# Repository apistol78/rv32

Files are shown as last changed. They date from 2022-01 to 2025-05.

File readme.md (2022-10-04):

# MOJO Risc-V CPU and System-on-a-Chip
The MOJO SOC is an educational and fun system for FPGA and "Bare metal" programming experimentations.\
It's a RISC-V CPU running at 100 MHz, 32 MiB RAM, audio and 320*200 video resolution.
To make user input easy I've moved USB host functionality to an external PCB using Raspberry Pico as a FPGA <-> HID bridge.

# Prerequisites
This project require an install of Traktor to generate required resources.
You will also need a RISC-V GCC toolchain compiled and installed at __/opt/riscv32/bin__ on your machine.

# How to build
Run __build.sh__ to build host (i.e. Linux) and target products:
```
./build.sh
```
After everything has been built you should be able to run the emulators:
```
./build/linux/ReleaseStatic/Rv32T -elf=./build/rv32/ReleaseStatic/Boot
```
or
```
./build/linux/ReleaseStatic/Rv32 -elf=./build/rv32/ReleaseStatic/Boot
```

# CPU
MOJO CPU is a conventional 5-stage (F,D,X,M,W) pipelined RISC-V CPU. It also contain configurable data- and instruction caches.

Written using SystemVerilog and are split up into logical pieces where each stage of the pipeline is in a separate module:

| Module | Description |
|---|---|
| CPU_ALU | ALU unit, fully combinatorial |
| CPU_CSR | CSR control unit |
| CPU_DCache_Comb | Data cache, combinatorial |
| CPU_DCache_Reg | Data cache, registered |
| CPU_DCache_None | Data cache, disabled |
| CPU_Decode | Decode stage |
| CPU_Defines | CPU defines |
| CPU_Divide | Divison wrapper, usually implemented with a vendor IP |
| CPU_Execute | Execute stage |
| CPU_Fetch | Fetch stage |
| CPU_Forward | Register forwarding logic |
| CPU_ICache_Comb | Instruction cache, combinatorial |
| CPU_ICache_Reg | Instruction cache, registered |
| CPU_ICache_None | Instruction cache, disabled |
| CPU_Memory | Memory stage |
| CPU_Multiply | Multiplication wrapper, usually implemented with a vendor IP |
| CPU_Registers | Register file |
| CPU_SkidBuffer | Generalized skid-buffer |
| CPU_Types | CPU types |
| CPU_Writeback | Writeback stage |

# Perifherials
A lot of perifherial modules has been implemented as port of the SoC:
| Module | Description |
|---|---|
| AUDIO_controller, AUDIO_i2s_output, AUDIO_pwm_output | PCM based audio modules |
| BRAM | Various block-ram modules |
| BRIDGE | BUS bridge, to separate BUS devices for improved timing. |
| BROM | Block-rom module |
| BusAccess | BUS multiplexed access |
| ClockDivider | Generic clock divider |
| DMA | Direct memory access controller |
| FIFO_BRAM | Block ram backed FIFO |
| FIFO | Register backed FIFO |
| GPIO | General purpose IO controller |
| I2C | I2C controller |
| LED | LED controller |
| PLIC | PLIC interrupt controller |
| RESET | Reset controller |
| SD | SD controller |
| SDRAM_controller | Generic SDRAM controller |
| SRAM_interface | Generic SRAM controller |
| SystemRegisters | System wide register map |
| Timer | Hardware timer with compare |
| UART | UART controller |
| VIDEO_controller | Video output controller |
| VIDEO_VGA | Video VGA signal generator |
| WriteBuffer | Write buffer (queue) with readback or read-through |

# System-on-a-Chip
A couple of custom PCBs designed to connect to QM-Tech FPGA boards is the physical basis for MOJO SoC.
The SoC support following perifherials:
* HDMI output
* Stereo audio output through PWM and through I2S HDMI.
* SD card interface using 4-bit SD protocol.
* 2 UARTs, one for host and one for HID input.
* Raspberry Pico based USB host to FPGA bridge supporting three external HID devices (keyboard, mouse and gamepad).

## Emulators
Two different emulators, one C++ highlevel emulator and one based on Verilator. The highlevel is useful for application development and the other is used for verification of gate level logic.

## Runtime
C/C++ runtime library, including a preemptive multithreaded kernel, expose all hardware features to user programs. Support CRT for easy portability.

## Schematics
KiCad schematics for all perifherial boards are available and been built using JLCPCB.

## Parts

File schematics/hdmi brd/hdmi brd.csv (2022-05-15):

Comment | Designator | Footprint | LCSC
0.1uF | C1,C2,C7,C8,C9,C10,C11,C12,C13,C14,C15 | Capacitor_SMD:C_0402_1005Metric | C1525
0.1uF | C3,C16,C17,C18 | Capacitor_SMD:C_0805_2012Metric_Pad1.18x1.45mm_HandSolder
100nF | C4,C19,C20,C21 | Capacitor_SMD:C_0805_2012Metric_Pad1.18x1.45mm_HandSolder
10uF | C5 | Capacitor_SMD:CP_Elec_5x5.3
100uF | C6 | Capacitor_SMD:CP_Elec_5x5.3
MountingHole | H1,H2 | MountingHole:MountingHole_3.2mm_M3_DIN965_Pad
Conn_02x32_Odd_Even | J1 | Connector_PinSocket_2.54mm:PinSocket_2x32_P2.54mm_Vertical
685119134923 | J2 | 685119134923 | C720616
0.022uH | L1 | Inductor_SMD:L_0805_2012Metric_Pad1.05x1.20mm_HandSolder
0.022uH | L2,L3,L4 | Inductor_SMD:L_0805_2012Metric_Pad1.15x1.40mm_HandSolder
4.7k | R1,R3,R4,R5,R6,R7 | Resistor_SMD:R_0402_1005Metric | C25900
10k | R2 | Resistor_SMD:R_0402_1005Metric | C11660
TestPoint | TP1,TP2,TP3,TP4 | TestPoint:TestPoint_Pad_D1.0mm
SII9022ACNU | U1 | Package_DFN_QFN:QFN-72-1EP_10x10mm_P0.5mm_EP6x6mm | C369565
AZ1117EH-1.2TRG1 | U2 | Package_TO_SOT_SMD:SOT-223-3_TabPin2 | C92104

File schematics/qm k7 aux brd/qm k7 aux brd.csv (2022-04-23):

Source: | /home/apistol/private/rv32/schematics/qm k7 aux brd/qm k7 aux brd.kicad_sch
Date: | Fri 22 Apr 2022 02:09:59 PM CEST
Tool: | Eeschema 6.0.4-6f826c9f35~116~ubuntu21.10.1
Generator: | /usr/share/kicad/plugins/bom_csv_grouped_by_value.py
Component Count: | 27
Individual Components:
Item | Qty | Reference(s) | Value | LibPart | Footprint | Datasheet
 |  | C1 | 10uF | Device:C_Polarized | Capacitor_SMD:CP_Elec_5x5.3 | ~
 |  | C2 | 100uF | Device:C_Polarized | Capacitor_SMD:CP_Elec_5x5.3 | ~
 |  | C3 | 3.3uF | pspice:C | Capacitor_SMD:C_0805_2012Metric_Pad1.18x1.45mm_HandSolder | ~
 |  | C4 | 3.3uF | pspice:C | Capacitor_SMD:C_0805_2012Metric_Pad1.18x1.45mm_HandSolder | ~
 |  | C5 | 2.7nF | pspice:C | Capacitor_SMD:C_0805_2012Metric_Pad1.18x1.45mm_HandSolder | ~
 |  | C6 | 2.7nF | pspice:C | Capacitor_SMD:C_0805_2012Metric_Pad1.18x1.45mm_HandSolder | ~
 |  | C7 | 10uF | pspice:C | Capacitor_SMD:C_0805_2012Metric_Pad1.18x1.45mm_HandSolder | ~
 |  | C8 | 100nF | pspice:C | Capacitor_SMD:C_0805_2012Metric_Pad1.18x1.45mm_HandSolder | ~
 |  | C9 | 10uF | pspice:C | Capacitor_SMD:C_0805_2012Metric_Pad1.18x1.45mm_HandSolder | ~
 |  | H1 | MountingHole | Mechanical:MountingHole | MountingHole:MountingHole_3.2mm_M3_DIN965_Pad | ~
 |  | H2 | MountingHole | Mechanical:MountingHole | MountingHole:MountingHole_3.2mm_M3_DIN965_Pad | ~
 |  | J1 | LEFT | Connector_Generic:Conn_02x32_Odd_Even | Connector_PinSocket_2.54mm:PinSocket_2x32_P2.54mm_Vertical | ~
 |  | J2 | Micro_SD_Card | Connector:Micro_SD_Card | Connector_Card:microSD_HC_Hirose_DM3D-SF | http://katalog.we-online.de/em/datasheet/693072010801.pdf
 |  | J3 | Conn_01x03 | Connector_Generic:Conn_01x03 | Connector_PinHeader_2.54mm:PinHeader_1x03_P2.54mm_Vertical | ~
 |  | J4 | Conn_01x03 | Connector_Generic:Conn_01x03 | Connector_PinHeader_2.54mm:PinHeader_1x03_P2.54mm_Vertical | ~
 |  | R1 | 4k7 | Device:R | Resistor_SMD:R_0805_2012Metric_Pad1.20x1.40mm_HandSolder | ~
 |  | R2 | 4k7 | Device:R | Resistor_SMD:R_0805_2012Metric_Pad1.20x1.40mm_HandSolder | ~
 |  | R3 | 4k7 | Device:R | Resistor_SMD:R_0805_2012Metric_Pad1.20x1.40mm_HandSolder | ~
 |  | R4 | 4k7 | Device:R | Resistor_SMD:R_0805_2012Metric_Pad1.20x1.40mm_HandSolder | ~
 |  | R5 | 4k7 | Device:R | Resistor_SMD:R_0805_2012Metric_Pad1.20x1.40mm_HandSolder | ~
 |  | R6 | 10k | Device:R | Resistor_SMD:R_0805_2012Metric_Pad1.20x1.40mm_HandSolder | ~
 |  | R7 | 10k | Device:R | Resistor_SMD:R_0805_2012Metric_Pad1.20x1.40mm_HandSolder | ~
 |  | R8 | 470 | Device:R | Resistor_SMD:R_0805_2012Metric_Pad1.20x1.40mm_HandSolder | ~
 |  | R9 | 470 | Device:R | Resistor_SMD:R_0805_2012Metric_Pad1.20x1.40mm_HandSolder | ~
 |  | TP1 | TestPoint | Connector:TestPoint | TestPoint:TestPoint_Pad_D2.5mm | ~
 |  | U1 | AP1117-33 | Regulator_Linear:AP1117-33 | Package_TO_SOT_SMD:SOT-223-3_TabPin2 | http://www.diodes.com/datasheets/AP1117.pdf
 |  | U2 | CS4344-CZZ | 2022-04-22_11-49-30:CS4344-CZZ | footprints:CS4344-CZZ
Collated Components:
Item | Qty | Reference(s) | Value | LibPart | Footprint | Datasheet
1 | 1 | C1 | 10uF | Device:C_Polarized | Capacitor_SMD:CP_Elec_5x5.3 | ~
2 | 1 | C2 | 100uF | Device:C_Polarized | Capacitor_SMD:CP_Elec_5x5.3 | ~
3 | 2 | C3, C4 | 3.3uF | pspice:C | Capacitor_SMD:C_0805_2012Metric_Pad1.18x1.45mm_HandSolder | ~
4 | 2 | C5, C6 | 2.7nF | pspice:C | Capacitor_SMD:C_0805_2012Metric_Pad1.18x1.45mm_HandSolder | ~
5 | 2 | C7, C9 | 10uF | pspice:C | Capacitor_SMD:C_0805_2012Metric_Pad1.18x1.45mm_HandSolder | ~
6 | 1 | C8 | 100nF | pspice:C | Capacitor_SMD:C_0805_2012Metric_Pad1.18x1.45mm_HandSolder | ~
7 | 2 | H1, H2 | MountingHole | Mechanical:MountingHole | MountingHole:MountingHole_3.2mm_M3_DIN965_Pad | ~
8 | 1 | J1 | LEFT | Connector_Generic:Conn_02x32_Odd_Even | Connector_PinSocket_2.54mm:PinSocket_2x32_P2.54mm_Vertical | ~
9 | 1 | J2 | Micro_SD_Card | Connector:Micro_SD_Card | Connector_Card:microSD_HC_Hirose_DM3D-SF | http://katalog.we-online.de/em/datasheet/693072010801.pdf
10 | 2 | J3, J4 | Conn_01x03 | Connector_Generic:Conn_01x03 | Connector_PinHeader_2.54mm:PinHeader_1x03_P2.54mm_Vertical | ~
11 | 5 | R1, R2, R3, R4, R5 | 4k7 | Device:R | Resistor_SMD:R_0805_2012Metric_Pad1.20x1.40mm_HandSolder | ~
12 | 2 | R6, R7 | 10k | Device:R | Resistor_SMD:R_0805_2012Metric_Pad1.20x1.40mm_HandSolder | ~
13 | 2 | R8, R9 | 470 | Device:R | Resistor_SMD:R_0805_2012Metric_Pad1.20x1.40mm_HandSolder | ~
14 | 1 | TP1 | TestPoint | Connector:TestPoint | TestPoint:TestPoint_Pad_D2.5mm | ~
15 | 1 | U1 | AP1117-33 | Regulator_Linear:AP1117-33 | Package_TO_SOT_SMD:SOT-223-3_TabPin2 | http://www.diodes.com/datasheets/AP1117.pdf
16 | 1 | U2 | CS4344-CZZ | 2022-04-22_11-49-30:CS4344-CZZ | footprints:CS4344-CZZ

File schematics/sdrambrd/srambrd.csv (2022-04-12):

Source: | C:\temp\srambrd2\sdrambrd\srambrd.kicad_sch
Date: | 4/6/2022 11:04:05 AM
Tool: | Eeschema (6.0.4)
Generator: | C:\Program Files\KiCad\6.0\bin\scripting\plugins/bom_csv_grouped_by_value_with_fp.py
Component Count: | 24
Ref | Qnty | Value | Cmp name | Footprint | Description | Vendor
C1, C2, | 2 | 100nF | C | Capacitor_SMD:C_0805_2012Metric_Pad1.18x1.45mm_HandSolder | Capacitor symbol for simulation only
C3, C4, C5, C6, | 4 | 10nF | C | Capacitor_SMD:C_0805_2012Metric_Pad1.18x1.45mm_HandSolder | Capacitor symbol for simulation only
C7, C8, | 2 | 100uF | C_Polarized | Capacitor_SMD:CP_Elec_5x5.3 | Polarized capacitor
H1, H2, | 2 | MountingHole | MountingHole | MountingHole:MountingHole_3.2mm_M3_DIN965_Pad | Mounting Hole without connection
J1, | 1 | LEFT | Conn_02x32_Odd_Even | Connector_PinSocket_2.54mm:PinSocket_2x32_P2.54mm_Vertical | Generic connector, double row, 02x32, odd/even pin numbering scheme (row 1 odd numbers, row 2 even numbers), script generated (kicad-library-utils/schlib/autogen/connector/)
J2, | 1 | Micro_SD_Card | Micro_SD_Card | Connector_Card:microSD_HC_Hirose_DM3BT-DSF-PEJS | Micro SD Card Socket
J3, J4, | 2 | Conn_01x03 | Conn_01x03 | Connector_PinHeader_2.54mm:PinHeader_1x03_P2.54mm_Vertical | Generic connector, single row, 01x03, script generated (kicad-library-utils/schlib/autogen/connector/)
R1, R2, R3, R4, R5, R6, R7, R8, R9, | 9 | 4k7 | R | Resistor_SMD:R_0805_2012Metric_Pad1.20x1.40mm_HandSolder | Resistor
U1, | 1 | IS61LV25616AL | IS61LV25616AL | Package_SO:TSOP-II-44_10.16x18.41mm_P0.8mm

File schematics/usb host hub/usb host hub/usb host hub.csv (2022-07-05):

Comment | Designator | Footprint | LCSC
27pF | C1,C2 | Capacitor_SMD:C_0805_2012Metric
1uF | C13,C14 | Capacitor_SMD:C_0402_1005Metric
10uF | C15 | Capacitor_SMD:CP_Elec_5x5.3
100uF | C16 | Capacitor_SMD:CP_Elec_5x5.3
10uF | C19 | Capacitor_SMD:C_0402_1005Metric
10uF | C21,C22,C23 | Capacitor_SMD:C_0805_2012Metric
100nF | C3,C4,C5,C6,C7,C8,C9,C10,C11,C12,C17,C20 | Capacitor_SMD:C_0402_1005Metric | C307331
LED | D1 | LED_SMD:LED_0805_2012Metric | C2297
MountingHole | H1,H2,H3,H4 | MountingHole:MountingHole_3.2mm_M3_DIN965_Pad
292303-1 | J1,J2,J6 | 292303-1:TE_292303-1
Conn_01x04_Male | J4 | Connector_PinHeader_2.54mm:PinHeader_1x04_P2.54mm_Vertical
Conn_01x04_Male | J5 | Connector_JST:JST_EH_B4B-EH-A_1x04_P2.50mm_Vertical
1k | R1 | Resistor_SMD:R_0805_2012Metric
10k | R10 | Resistor_SMD:R_0402_1005Metric | C269674
47 | R11 | Resistor_SMD:R_0805_2012Metric
33k | R12,R14,R15 | Resistor_SMD:R_0805_2012Metric
2.7k 1% | R13 | Resistor_SMD:R_0402_1005Metric | C25885
27 | R2,R3 | Resistor_SMD:R_0805_2012Metric
27 | R4,R5,R6,R7,R8,R9 | Resistor_SMD:R_0402_1005Metric
TestPoint_Small | TP1,TP_DRV1,TP_LED1,TP_LED2,TP_1V1 | TestPoint:TestPoint_Pad_D1.5mm
RP2040 | U1 | parts:QFN40P700X700X90-57N | C2040
FE1.1s | U2 | Package_SO:SSOP-28_3.9x9.9mm_P0.635mm | C9359
W25Q128JVS | U3 | Package_SO:SOIC-8_5.23x5.23mm_P1.27mm | C97521
AZ1117EH-3.3TRG1 | U4 | Package_TO_SOT_SMD:SOT-223-3_TabPin2 | C108494
USBLC6-2SC6 | U5,U6,U7 | Package_TO_SOT_SMD:SOT-23-6
12MHz | Y1,Y2 | Crystal:Crystal_SMD_HC49-SD

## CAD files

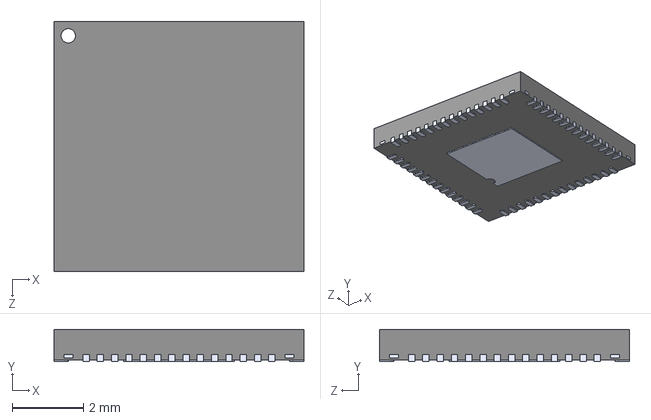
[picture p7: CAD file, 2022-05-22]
schematics/motherboard/parts/rp2040/RP2040.step
7.00 x 0.9 x 7.00 mm

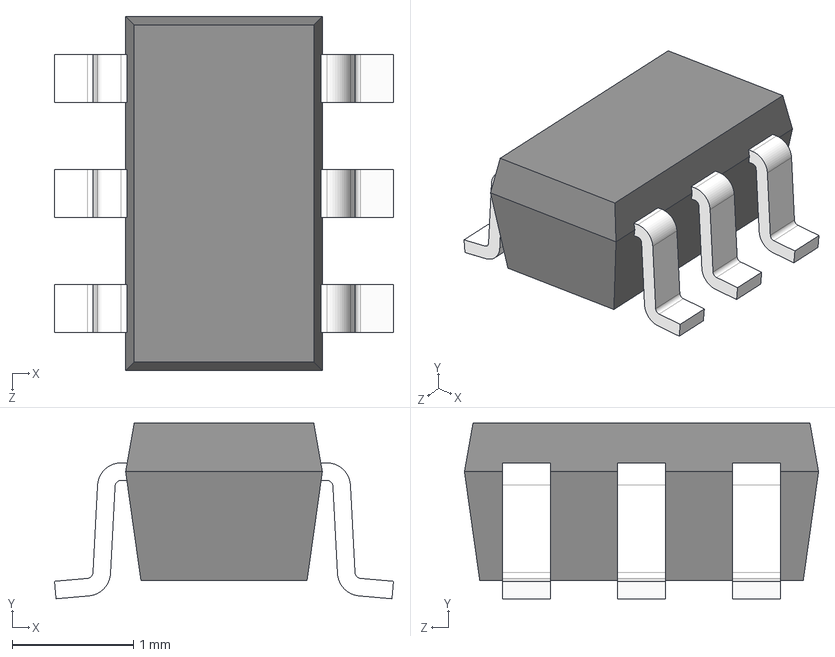
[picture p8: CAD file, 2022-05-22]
schematics/motherboard/parts/USBLC6-2SC6/USBLC6-2SC6.step
2.80 x 1.45 x 2.92 mm

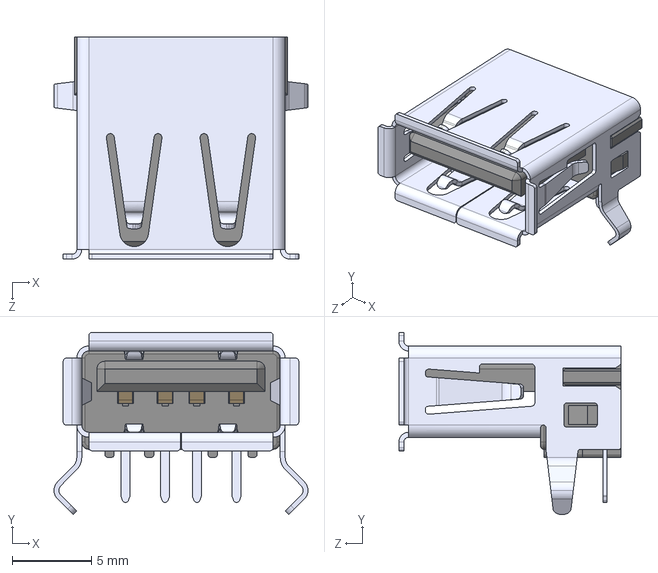
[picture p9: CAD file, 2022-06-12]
schematics/motherboard/parts/292303-1/292303-1.step
16.0 x 11.5 x 14.0 mm

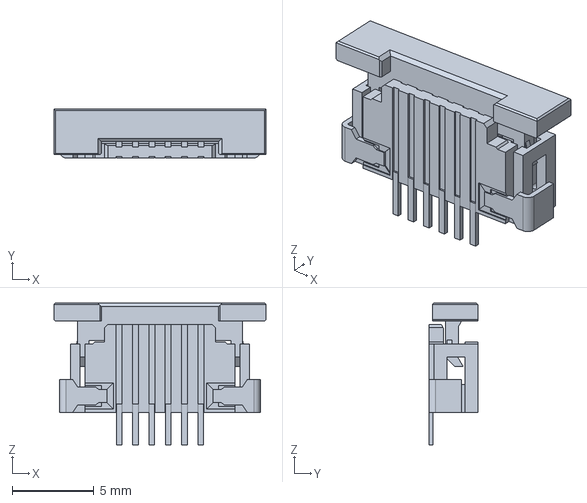
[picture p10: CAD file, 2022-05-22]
schematics/motherboard/parts/52271-0679/52271-0679.step
13.0 x 3.00 x 8.70 mm

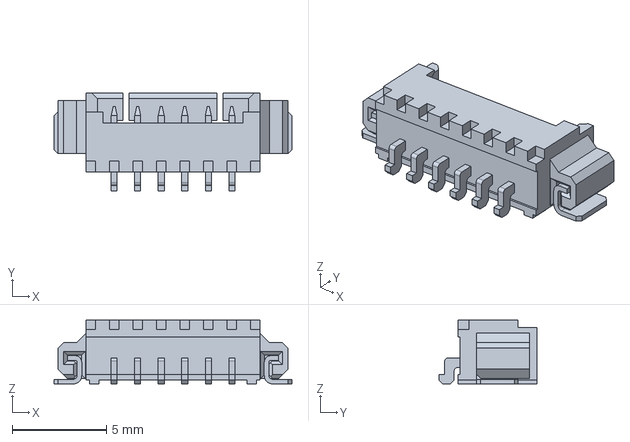
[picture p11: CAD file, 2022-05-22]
schematics/motherboard/parts/532610671/532610671.step
12.7 x 5.20 x 3.40 mm

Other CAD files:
board/qmtech_cv/SoC.stp
board/qmtech_cv_2/SoC.stp
board/SDRAM/stp1.stp
board/terasic_cv_gx/SoC.stp

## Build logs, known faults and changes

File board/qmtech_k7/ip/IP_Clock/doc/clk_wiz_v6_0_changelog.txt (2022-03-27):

2021.2:
 * Version 6.0 (Rev. 9)
 * Bug Fix: CR Fixes
 * Other: CR Fixes

2021.1.1:
 * Version 6.0 (Rev. 8)
 * No changes

2021.1:
 * Version 6.0 (Rev. 8)
 * Bug Fix: Internal GUI fixes
 * Other: CR Fixes

2020.3:
 * Version 6.0 (Rev. 7)
 * Bug Fix: Internal GUI fixes
 * Other: CR Fixes

2020.2.2:
 * Version 6.0 (Rev. 6)
 * No changes

2020.2.1:
 * Version 6.0 (Rev. 6)
 * No changes

2020.2:
 * Version 6.0 (Rev. 6)
 * Bug Fix: Internal GUI fixes
 * Other: CR Fixes

2020.1.1:
 * Version 6.0 (Rev. 5)
 * No changes

2020.1:
 * Version 6.0 (Rev. 5)
 * Bug Fix: Internal GUI fixes
 * Other: CR Fixes

2019.2.2:
 * Version 6.0 (Rev. 4)
 * No changes

2019.2.1:
 * Version 6.0 (Rev. 4)
 * No changes

2019.2:
 * Version 6.0 (Rev. 4)
 * Bug Fix: Internal GUI fixes
 * Other: CR Fixes

2019.1.3:
 * Version 6.0 (Rev. 3)
 * No changes

2019.1.2:
 * Version 6.0 (Rev. 3)
 * No changes

2019.1.1:
 * Version 6.0 (Rev. 3)
 * No changes

2019.1:
 * Version 6.0 (Rev. 3)
 * Bug Fix: Internal GUI fixes
 * Other: New family support added

2018.3.1:
 * Version 6.0 (Rev. 2)
 * No changes

2018.3:
 * Version 6.0 (Rev. 2)
 * Bug Fix: Made input source independent for primary and secondary clock
 * Other: New family support added

2018.2:
 * Version 6.0 (Rev. 1)
 * Bug Fix: Removed vco freq check when Primitive is None
 * Other: New family support added

2018.1:
 * Version 6.0
 * Bug Fix: Bug fixes in Dynamic Reconfiguration feature and Write DRP feature
 * Bug Fix: Bug fixes for connection issue for s_axi_aresetn pin in IPI
 * Feature Enhancement: The default value of USE_PHASE_ALIGMENT is updated to false for UltraScale and UltraScale+ devices. Phase Alignment feature uses extra clock routes in UltraScale and UltraScale+ designs when MMCMs are used. These routing resources are wasted when user do not understand when phase alignment is really needed. Now, implementation tools can use these extra clock routing resources for high fanout signals.
 * Feature Enhancement: A column "Max. freq of buffer" is added in the Output Clock table which shows the maximum frequency that the selected output buffer can support
 * Other: DRCs added for invalid input values in Override mode

2017.4:
 * Version 5.4 (Rev. 3)
 * Bug Fix: Internal GUI issues are fixed for COMPENSATION mode as INTERNAL
 * Bug Fix: Fixed issue in dynamic reconfiguration of fractional values of M in MMCME3, MMCME4

2017.3:
 * Version 5.4 (Rev. 2)
 * General: Internal GUI changes. No effect on the customer design. Added support for aspartan7 devices

2017.2:
 * Version 5.4 (Rev. 1)
 * General: Internal GUI changes. No effect on the customer design.

2017.1:
 * Version 5.4
 * Port Change: Minor version upgrade. CLR pins are added to the pin list when selected buffer is BUFGCEDIV for ultrascale and ultrascale plus devices.
 * Other: Added support for new zynq ultrascale plus devices.

2016.4:
 * Version 5.3 (Rev. 3)
 * Bug Fix: Internal GUI issues are fixed.

2016.3:
 * Version 5.3 (Rev. 2)
 * Feature Enhancement: Added new option "Auto" under PRIMITIVE selection for ultrascale and above devices. This option allows the Wizard to instantiate appropriate primitive for the user inputs.
 * Feature Enhancement: Added Matched Routing Option for better timing solutions.
 * Feature Enhancement: Options 'Buffer' and 'Buffer_with_CE' are added to the buffer selection list.
 * Other: Source HDL files are concatenated into a single file to speed up synthesis and simulation. No changes required by the user
 * Other: Added support for Spartan7 devices.

2016.2:
 * Version 5.3 (Rev. 1)
 * Internal register bit update, no effect on customer designs.

2016.1:
 * Version 5.3
 * Added Clock Monitor Feature as part of clocking wizard
 * DRP registers can be directly written through AXI without resource utilization
 * Changes to HDL library management to support Vivado IP simulation library

2015.4.2:
 * Version 5.2 (Rev. 1)
 * No changes

2015.4.1:
 * Version 5.2 (Rev. 1)
 * No changes

2015.4:
 * Version 5.2 (Rev. 1)
 * Internal device family change, no functional changes

2015.3:
 * Version 5.2
 * IP revision number added to HDL module, library, and include file names, to support designs with both locked and upgraded IP instances
 * Port Renaming tab is hidden in the GUI in IP Integrator as this feature is not supported
 * Phase alignment feature is removed for ultrascale PLL as primitve has limited capabilities of supporting this feature
 * When clocking wizard is targetted on a board part, the frequency values that gets propagated to primary and secondary clocks are displayed in floating number format
 * Example design and simulation files are delivered in verilog only

2015.2.1:
 * Version 5.1 (Rev. 6)
 * No changes

2015.2:
 * Version 5.1 (Rev. 6)
 * No changes

2015.1:
 * Version 5.1 (Rev. 6)
 * Updated mmcm_pll_filter_lookup and mmcm_pll_lock_lookup functions in the header file for 7-Series and UltraScale devices
 * Supported devices and production status are now determined automatically, to simplify support for future devices

2014.4.1:
 * Version 5.1 (Rev. 5)
 * No changes

2014.4:
 * Version 5.1 (Rev. 5)
 * Internal device family change, no functional changes
 * updates related to the source selection based on board interface for zed board

2014.3:
 * Version 5.1 (Rev. 4)
 * Option added to enable dynamic phase and duty cycle for resource optimization in AXI4-Lite interface

2014.2:
 * Version 5.1 (Rev. 3)
 * Updated for AXI4-Lite interface locked status register address and bit mapping to align with the pg065

2014.1:
 * Version 5.1 (Rev. 2)
 * Updated to use inverted output CLKOUTB 0-3 of Clocking Primitive based on requested 180 phase w.r.t. previous clock
 * Internal device family name change, no functional changes

2013.4:
 * Version 5.1 (Rev. 1)
 * Added support for Ultrascale devices
 * Updated Board Flow GUI to select the clock interfaces
 * Fixed issue with Stub file parameter error for BUFR output driver

2013.3:
 * Version 5.1
 * Added AXI4-Lite interface to dynamically reconfigure MMCM/PLL
 * Improved safe clock logic to remove glitches on clock outputs for odd multiples of input clock frequencies
 * Fixed precision issues between displayed and actual frequencies
 * Added tool tips to GUI
 * Added Jitter and Phase error values to IP properties
 * Added support for Cadence IES and Synopsys VCS simulators
 * Reduced warnings in synthesis and simulation
 * Enhanced support for IP Integrator

2013.2:
 * Version 5.0 (Rev. 1)
 * Fixed issue with clock constraints for multiple instances of clocking wizard
 * Updated Life-Cycle status of devices

2013.1:
 * Version 5.0
 * Lower case ports for Verilog
 * Added Safe Clock Startup and Clock Sequencing

(c) Copyright 2008 - 2021 Xilinx, Inc. All rights reserved.

This file contains confidential and proprietary information
of Xilinx, Inc. and is protected under U.S. and
international copyright and other intellectual property
laws.

DISCLAIMER
This disclaimer is not a license and does not grant any
rights to the materials distributed herewith. Except as
otherwise provided in a valid license issued to you by
Xilinx, and to the maximum extent permitted by applicable
law: (1) THESE MATERIALS ARE MADE AVAILABLE "AS IS" AND
WITH ALL FAULTS, AND XILINX HEREBY DISCLAIMS ALL WARRANTIES
AND CONDITIONS, EXPRESS, IMPLIED, OR STATUTORY, INCLUDING
BUT NOT LIMITED TO WARRANTIES OF MERCHANTABILITY, NON-
INFRINGEMENT, OR FITNESS FOR ANY PARTICULAR PURPOSE; and
(2) Xilinx shall not be liable (whether in contract or tort,
including negligence, or under any other theory of
liability) for any loss or damage of any kind or nature
related to, arising under or in connection with these
materials, including for any direct, or any indirect,
special, incidental, or consequential loss or damage
(including loss of data, profits, goodwill, or any type of
loss or damage suffered as a result of any action brought
by a third party) even if such damage or loss was
reasonably foreseeable or Xilinx had been advised of the
possibility of the same.

CRITICAL APPLICATIONS
Xilinx products are not designed or intended to be fail-
safe, or for use in any application requiring fail-safe
performance, such as life-support or safety devices or
systems, Class III medical devices, nuclear facilities,
applications related to the deployment of airbags, or any
other applications that could lead to death, personal
injury, or severe property or environmental damage
(individually and collectively, "Critical
Applications"). Customer assumes the sole risk and
liability of any use of Xilinx products in Critical
Applications, subject only to applicable laws and
regulations governing limitations on product liability.

THIS COPYRIGHT NOTICE AND DISCLAIMER MUST BE RETAINED AS
PART OF THIS FILE AT ALL TIMES.

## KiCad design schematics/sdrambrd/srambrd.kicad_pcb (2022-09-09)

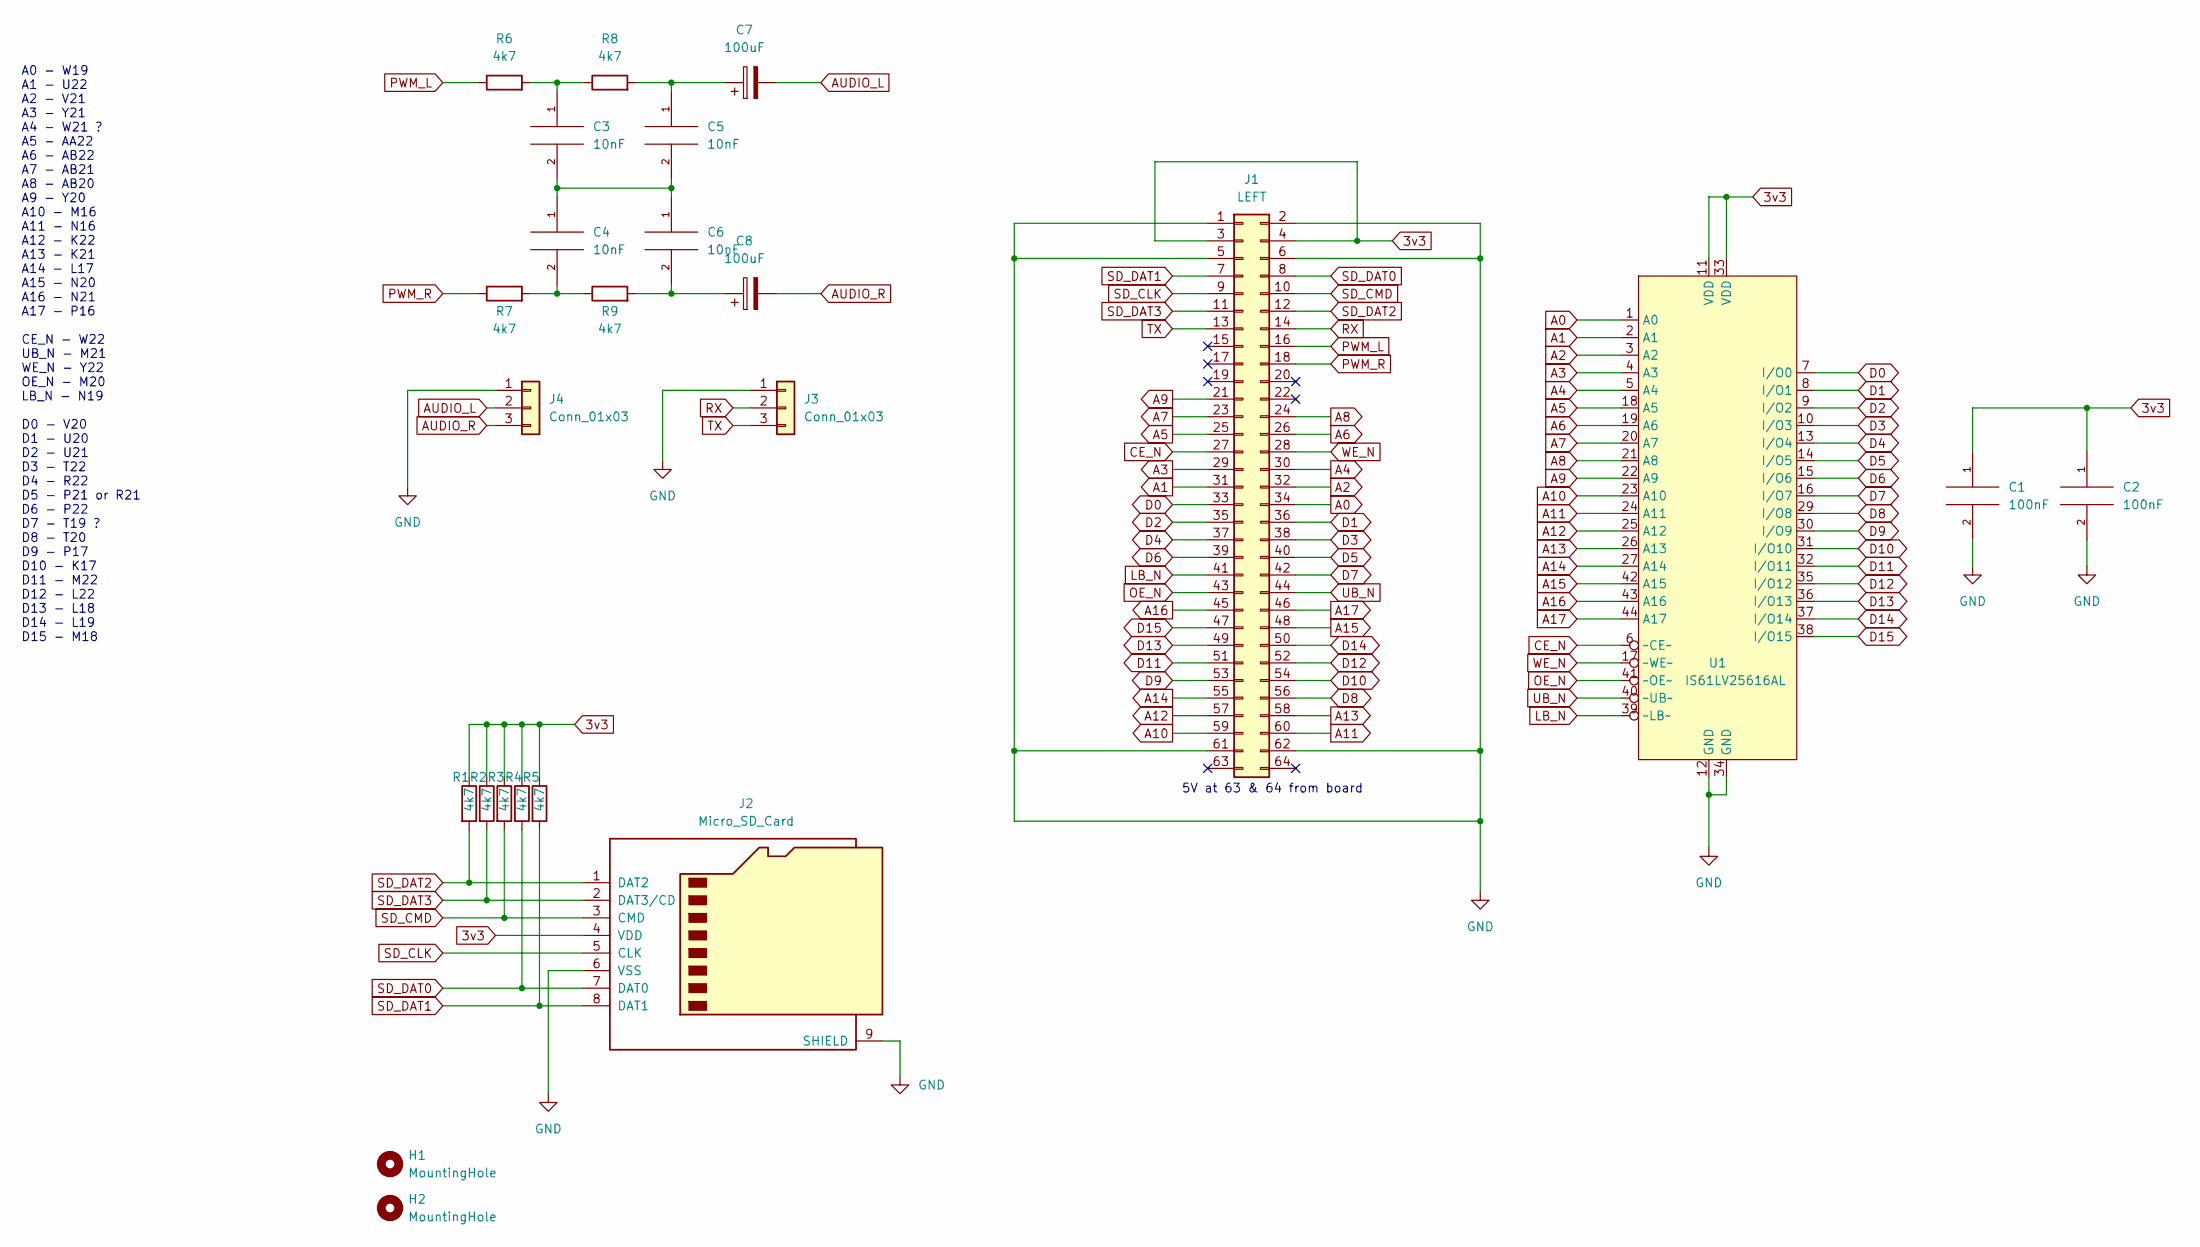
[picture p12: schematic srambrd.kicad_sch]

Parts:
C1, C2: 100nF; C_0805_2012Metric_Pad1.18x1.45mm_HandSolder
C3, C4, C5, C6: 10nF; C_0805_2012Metric_Pad1.18x1.45mm_HandSolder
C7, C8: 100uF; CP_Elec_5x5.3
H1, H2: MountingHole; MountingHole_3.2mm_M3_DIN965_Pad
J1: LEFT; PinSocket_2x32_P2.54mm_Vertical
J2: Micro_SD_Card; microSD_HC_Hirose_DM3D-SF
J3, J4: Conn_01x03; PinHeader_1x03_P2.54mm_Vertical
R1, R2, R3, R4, R5, R6, R7, R8, R9: 4k7; R_0805_2012Metric_Pad1.20x1.40mm_HandSolder
U1: IS61LV25616AL; TSOP-II-44_10.16x18.41mm_P0.8mm

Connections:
3v3: C1.1, C2.1, J1.3, J1.4, J2.4 (VDD), R1.1, R2.1, R3.1, R4.1, R5.1, U1.11 (VDD), U1.33 (VDD)
A0: J1.34, U1.1 (A0)
A1: J1.31, U1.2 (A1)
A2: J1.32, U1.3 (A2)
A3: J1.29, U1.4 (A3)
A4: J1.30, U1.5 (A4)
A5: J1.25, U1.18 (A5)
A6: J1.26, U1.19 (A6)
A7: J1.23, U1.20 (A7)
A8: J1.24, U1.21 (A8)
A9: J1.21, U1.22 (A9)
A10: J1.59, U1.23 (A10)
A11: J1.60, U1.24 (A11)
A12: J1.57, U1.25 (A12)
A13: J1.58, U1.26 (A13)
A14: J1.55, U1.27 (A14)
A15: J1.48, U1.42 (A15)
A16: J1.45, U1.43 (A16)
A17: J1.46, U1.44 (A17)
AUDIO_L: C7.2, J4.2
AUDIO_R: C8.2, J4.3
CE_N: J1.27, U1.6 (~CE~)
D0: J1.33, U1.7 (I/O0)
D1: J1.36, U1.8 (I/O1)
D2: J1.35, U1.9 (I/O2)
D3: J1.38, U1.10 (I/O3)
D4: J1.37, U1.13 (I/O4)
D5: J1.40, U1.14 (I/O5)
D6: J1.39, U1.15 (I/O6)
D7: J1.42, U1.16 (I/O7)
D8: J1.56, U1.29 (I/O8)
D9: J1.53, U1.30 (I/O9)
D10: J1.54, U1.31 (I/O10)
D11: J1.51, U1.32 (I/O11)
D12: J1.52, U1.35 (I/O12)
D13: J1.49, U1.36 (I/O13)
D14: J1.50, U1.37 (I/O14)
D15: J1.47, U1.38 (I/O15)
GND: C1.2, C2.2, J1.1, J1.2, J1.5, J1.6, J1.61, J1.62, J2.6 (VSS), J2.9 (SHIELD), J3.1, J4.1, U1.12 (GND), U1.34 (GND)
LB_N: J1.41, U1.39 (~LB~)
unnamed: C3.1, R6.2, R8.1
unnamed: C3.2, C4.1, C5.2, C6.1
unnamed: C4.2, R7.2, R9.1
unnamed: C5.1, C7.1, R8.2
unnamed: C6.2, C8.1, R9.2
OE_N: J1.43, U1.41 (~OE~)
PWM_L: J1.16, R6.1
PWM_R: J1.18, R7.1
RX: J1.14, J3.2
SD_CLK: J1.9, J2.5 (CLK)
SD_CMD: J1.10, J2.3 (CMD), R3.2
SD_DAT0: J1.8, J2.7 (DAT0), R4.2
SD_DAT1: J1.7, J2.8 (DAT1), R5.2
SD_DAT2: J1.12, J2.1 (DAT2), R1.2
SD_DAT3: J1.11, J2.2 (DAT3/CD), R2.2
TX: J1.13, J3.3
UB_N: J1.44, U1.40 (~UB~)
WE_N: J1.28, U1.17 (~WE~)

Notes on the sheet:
5V at 63 & 64 from board
A0 - W19 A1 - U22 A2 - V21 A3 - Y21 A4 - W21 ? A5 - AA22 A6 - AB22 A7 - AB21 A8 - AB20 A9 - Y20 A10 - M16 A11 - N16 A12 - K22 A13 - K21 A14 - L17 A15 - N20 A16 - N21 A17 - P16 CE_N - W22 UB_N - M21 WE_N - Y22 OE_N - M20 LB_N - N19 D0 - V20 D1 - U20 D2 - U21 D3 - T22 D4 - R22 D5 - P21 or R21 D6 - P2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

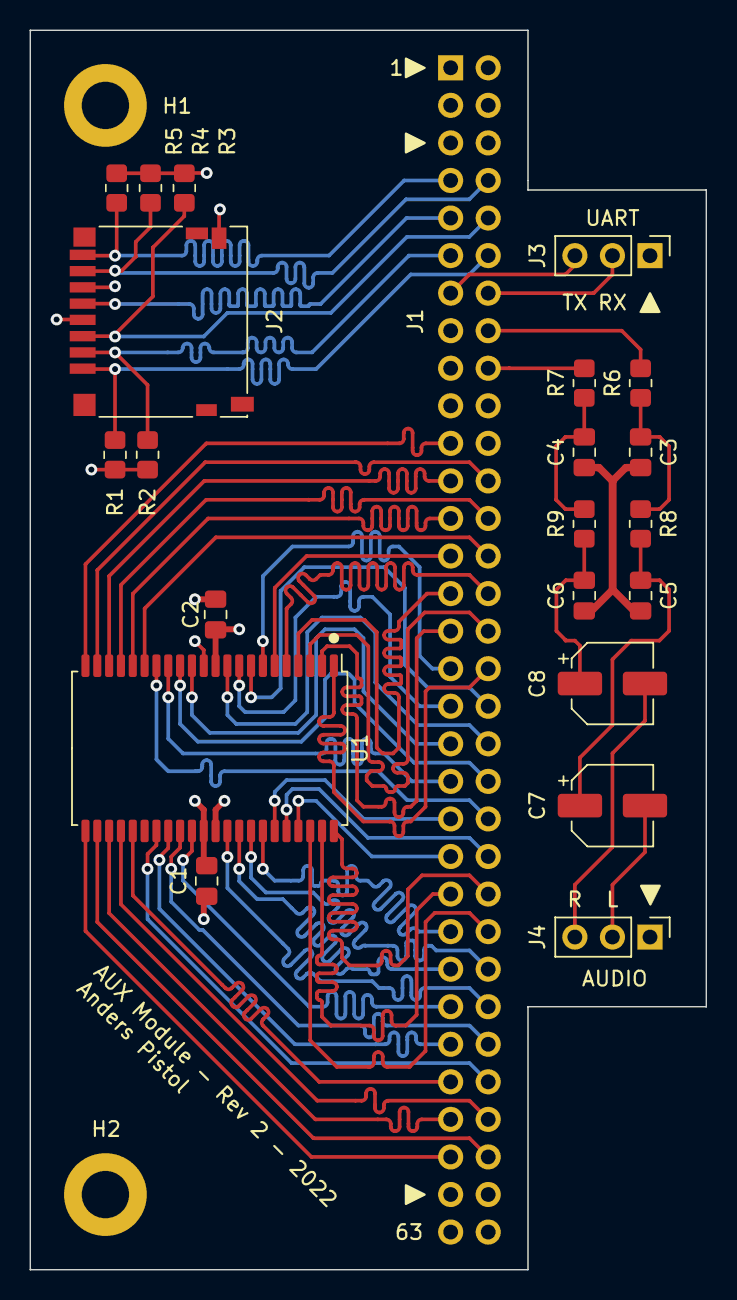
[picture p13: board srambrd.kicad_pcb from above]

Board: 4 copper layers, 45.7 x 83.8 mm, 24 parts (1 on the bottom side), 58 nets.

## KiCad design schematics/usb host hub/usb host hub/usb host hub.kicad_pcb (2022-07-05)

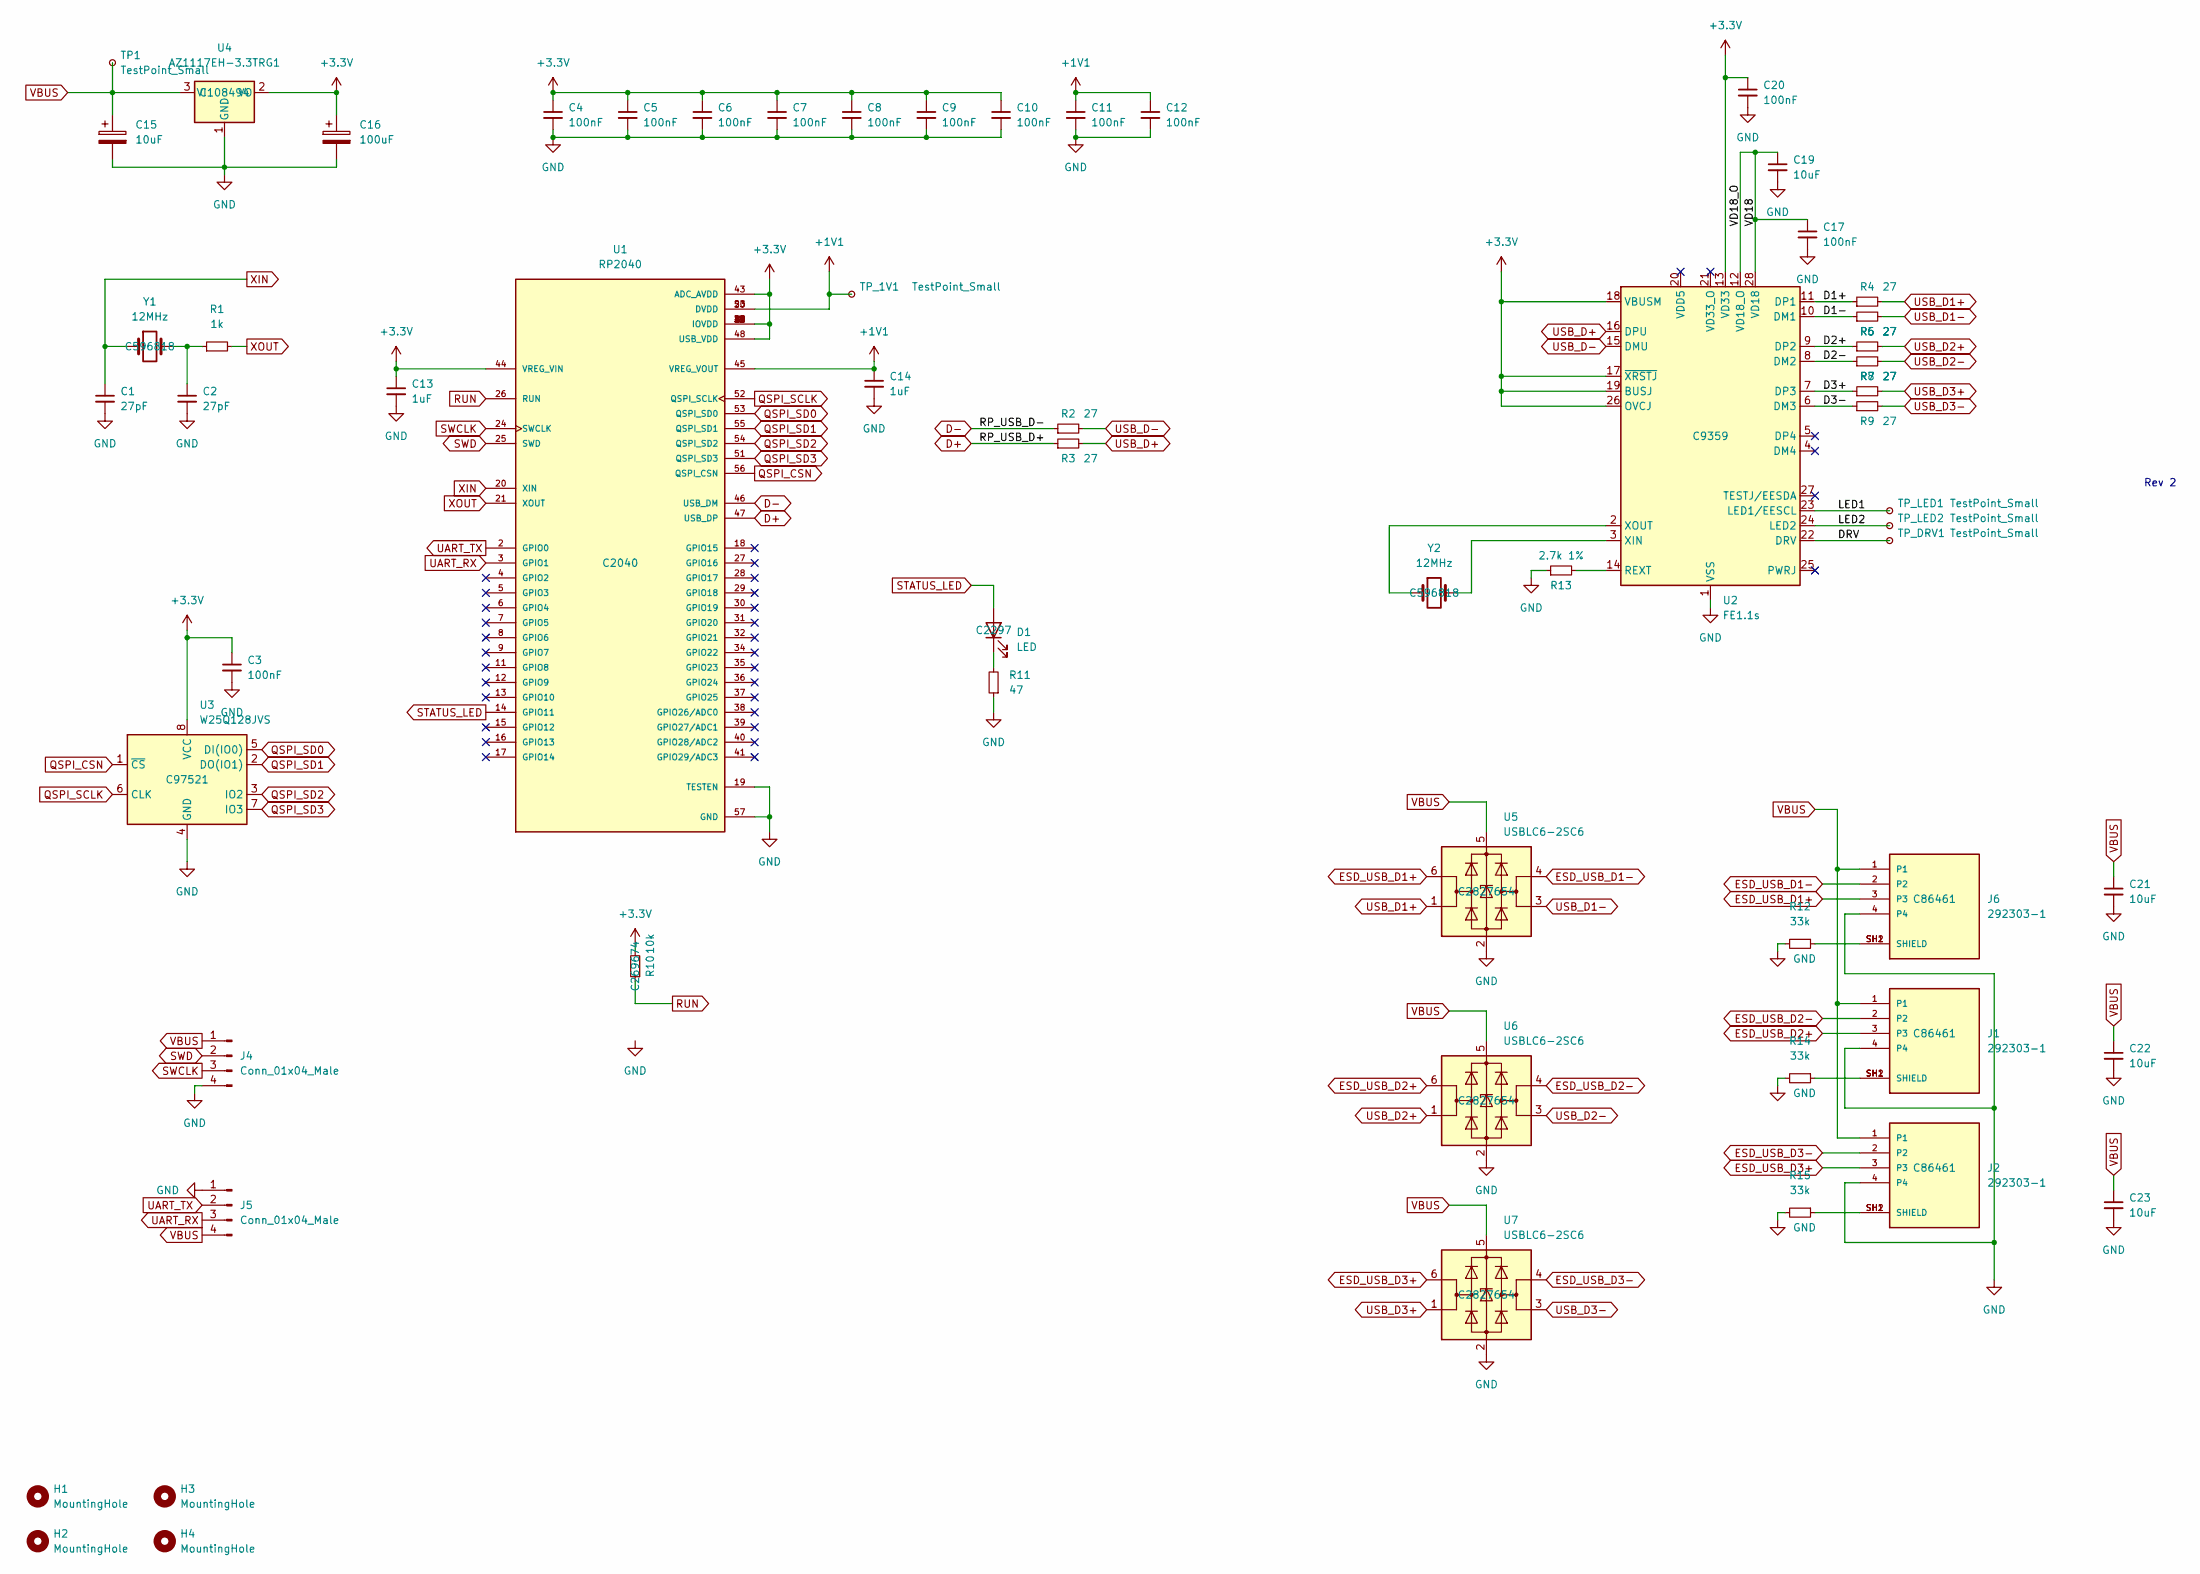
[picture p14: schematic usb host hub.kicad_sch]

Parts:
C1, C2: 27pF; C_0805_2012Metric
C3, C4, C5, C6, C7, C8, C9, C10, C11, C12, C17, C20: 100nF; C_0402_1005Metric; LCSC C307331
C13, C14: 1uF; C_0402_1005Metric
C15: 10uF; CP_Elec_5x5.3
C16: 100uF; CP_Elec_5x5.3
C19: 10uF; C_0402_1005Metric
C21, C22, C23: 10uF; C_0805_2012Metric
D1: LED; LED_0805_2012Metric; LCSC C2297
H1, H2, H3, H4: MountingHole; MountingHole_3.2mm_M3_DIN965_Pad
J1, J2, J6: 292303-1; TE_292303-1
J4: Conn_01x04_Male; PinHeader_1x04_P2.54mm_Vertical
J5: Conn_01x04_Male; JST_EH_B4B-EH-A_1x04_P2.50mm_Vertical
R1: 1k; R_0805_2012Metric
R2, R3: 27; R_0805_2012Metric
R4, R5, R6, R7, R8, R9: 27; R_0402_1005Metric
R10: 10k; R_0402_1005Metric; LCSC C269674
R11: 47; R_0805_2012Metric
R12, R14, R15: 33k; R_0805_2012Metric
R13: 2.7k 1%; R_0402_1005Metric; LCSC C25885
TP1: TestPoint_Small; TestPoint_Pad_D1.5mm
TP_1V1: TestPoint_Small; TestPoint_Pad_D1.5mm
TP_DRV1: TestPoint_Small; TestPoint_Pad_D1.5mm
TP_LED1, TP_LED2: TestPoint_Small; TestPoint_Pad_D1.5mm
U1: RP2040; QFN40P700X700X90-57N; PARTREV 1.6.1; LCSC C2040
U2: FE1.1s; SSOP-28_3.9x9.9mm_P0.635mm; LCSC C9359
U3: W25Q128JVS; SOIC-8_5.23x5.23mm_P1.27mm; LCSC C97521
U4: AZ1117EH-3.3TRG1; SOT-223-3_TabPin2; LCSC C108494
U5, U6, U7: USBLC6-2SC6; SOT-23-6
Y1, Y2: 12MHz; Crystal_SMD_HC49-SD

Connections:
+1V1: C11.1, C12.1, C14.1, TP_1V1.1, U1.23 (DVDD), U1.45 (VREG_VOUT), U1.50 (DVDD)
+3V3: C3.1, C4.1, C5.1, C6.1, C7.1, C8.1, C9.1, C10.1, C13.1, C16.1, C20.1, R10.2, U1.1 (IOVDD), U1.10 (IOVDD), U1.22 (IOVDD), U1.33 (IOVDD), U1.42 (IOVDD), U1.43 (ADC_AVDD), U1.44 (VREG_VIN), U1.48 (USB_VDD), U1.49 (IOVDD), U2.13 (VD33), U2.17 (~XRSTJ), U2.18 (VBUSM), U2.19 (BUSJ), U2.26 (OVCJ), U3.8 (VCC), U4.2 (VO)
/D1+: R4.1, U2.11 (DP1)
/D1-: R5.1, U2.10 (DM1)
/D2+: R6.1, U2.9 (DP2)
/D2-: R7.1, U2.8 (DM2)
/D3+: R8.1, U2.7 (DP3)
/D3-: R9.1, U2.6 (DM3)
/DRV: TP_DRV1.1, U2.22 (DRV)
/LED1: TP_LED1.1, U2.23 (LED1/EESCL)
/LED2: TP_LED2.1, U2.24 (LED2)
/VD18: C17.1, C19.1, U2.12 (VD18_O), U2.28 (VD18)
D+: R3.1, U1.47 (USB_DP)
D-: R2.1, U1.46 (USB_DM)
ESD_USB_D1+: J6.3, U5.6 (I/O1)
ESD_USB_D1-: J6.2, U5.4 (I/O2)
ESD_USB_D2+: J1.3, U6.6 (I/O1)
ESD_USB_D2-: J1.2, U6.4 (I/O2)
ESD_USB_D3+: J2.3, U7.6 (I/O1)
ESD_USB_D3-: J2.2, U7.4 (I/O2)
GND: C1.2, C2.2, C3.2, C4.2, C5.2, C6.2, C7.2, C8.2, C9.2, C10.2, C11.2, C12.2, C13.2, C14.2, C15.2, C16.2, C17.2, C19.2, C20.2, C21.2, C22.2, C23.2, J1.4, J2.4, J4.4, J5.1, J6.4, R11.1, R12.2, R13.1, R14.2, R15.2, U1.19 (TESTEN), U1.57 (GND), U2.1 (VSS), U3.4 (GND), U4.1 (GND), U5.2 (GND), U6.2 (GND), U7.2 (GND)
unnamed: C2.1, R1.1, Y1.2
unnamed: D1.1 (K), R11.2
unnamed: J1.SH1 (SHIELD), J1.SH2 (SHIELD), R14.1
unnamed: J2.SH1 (SHIELD), J2.SH2 (SHIELD), R15.1
unnamed: J6.SH1 (SHIELD), J6.SH2 (SHIELD), R12.1
unnamed: R13.2, U2.14 (REXT)
unnamed: U2.3 (XIN), Y2.2
unnamed: U2.2 (XOUT), Y2.1
QSPI_CSN: U1.56 (QSPI_CSN), U3.1 (~CS)
QSPI_SCLK: U1.52 (QSPI_SCLK), U3.6 (CLK)
QSPI_SD0: U1.53 (QSPI_SD0), U3.5 (DI(IO0))
QSPI_SD1: U1.55 (QSPI_SD1), U3.2 (DO(IO1))
QSPI_SD2: U1.54 (QSPI_SD2), U3.3 (IO2)
QSPI_SD3: U1.51 (QSPI_SD3), U3.7 (IO3)
RUN: R10.1, U1.26 (RUN)
STATUS_LED: D1.2 (A), U1.14 (GPIO11)
SWCLK: J4.3, U1.24 (SWCLK)
SWD: J4.2, U1.25 (SWD)
UART_RX: J5.3, U1.3 (GPIO1)
UART_TX: J5.2, U1.2 (GPIO0)
USB_D1+: R4.2, U5.1 (I/O1)
USB_D1-: R5.2, U5.3 (I/O2)
USB_D2+: R6.2, U6.1 (I/O1)
USB_D2-: R7.2, U6.3 (I/O2)
USB_D3+: R8.2, U7.1 (I/O1)
USB_D3-: R9.2, U7.3 (I/O2)
USB_D+: R3.2, U2.16 (DPU)
USB_D-: R2.2, U2.15 (DMU)
VBUS: C15.1, C21.1, C22.1, C23.1, J1.1, J2.1, J4.1, J5.4, J6.1, TP1.1, U4.3 (VI), U5.5 (VBUS), U6.5 (VBUS), U7.5 (VBUS)
XIN: C1.1, U1.20 (XIN), Y1.1
XOUT: R1.2, U1.21 (XOUT)

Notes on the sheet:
Rev 2

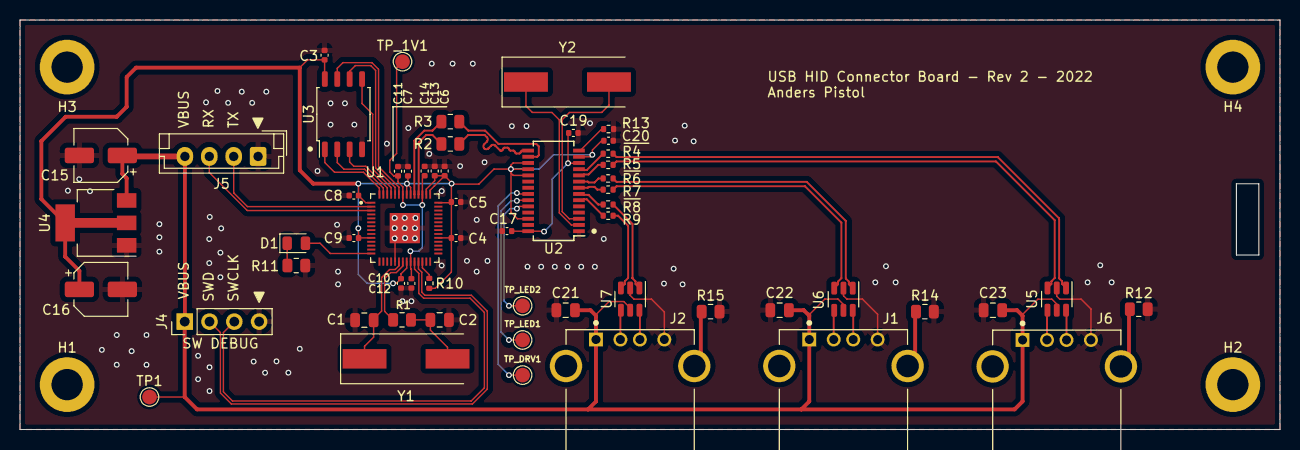
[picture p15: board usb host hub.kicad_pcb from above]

Board: 2 copper layers, 129.0 x 41.9 mm, 61 parts (0 on the bottom side), 52 nets.

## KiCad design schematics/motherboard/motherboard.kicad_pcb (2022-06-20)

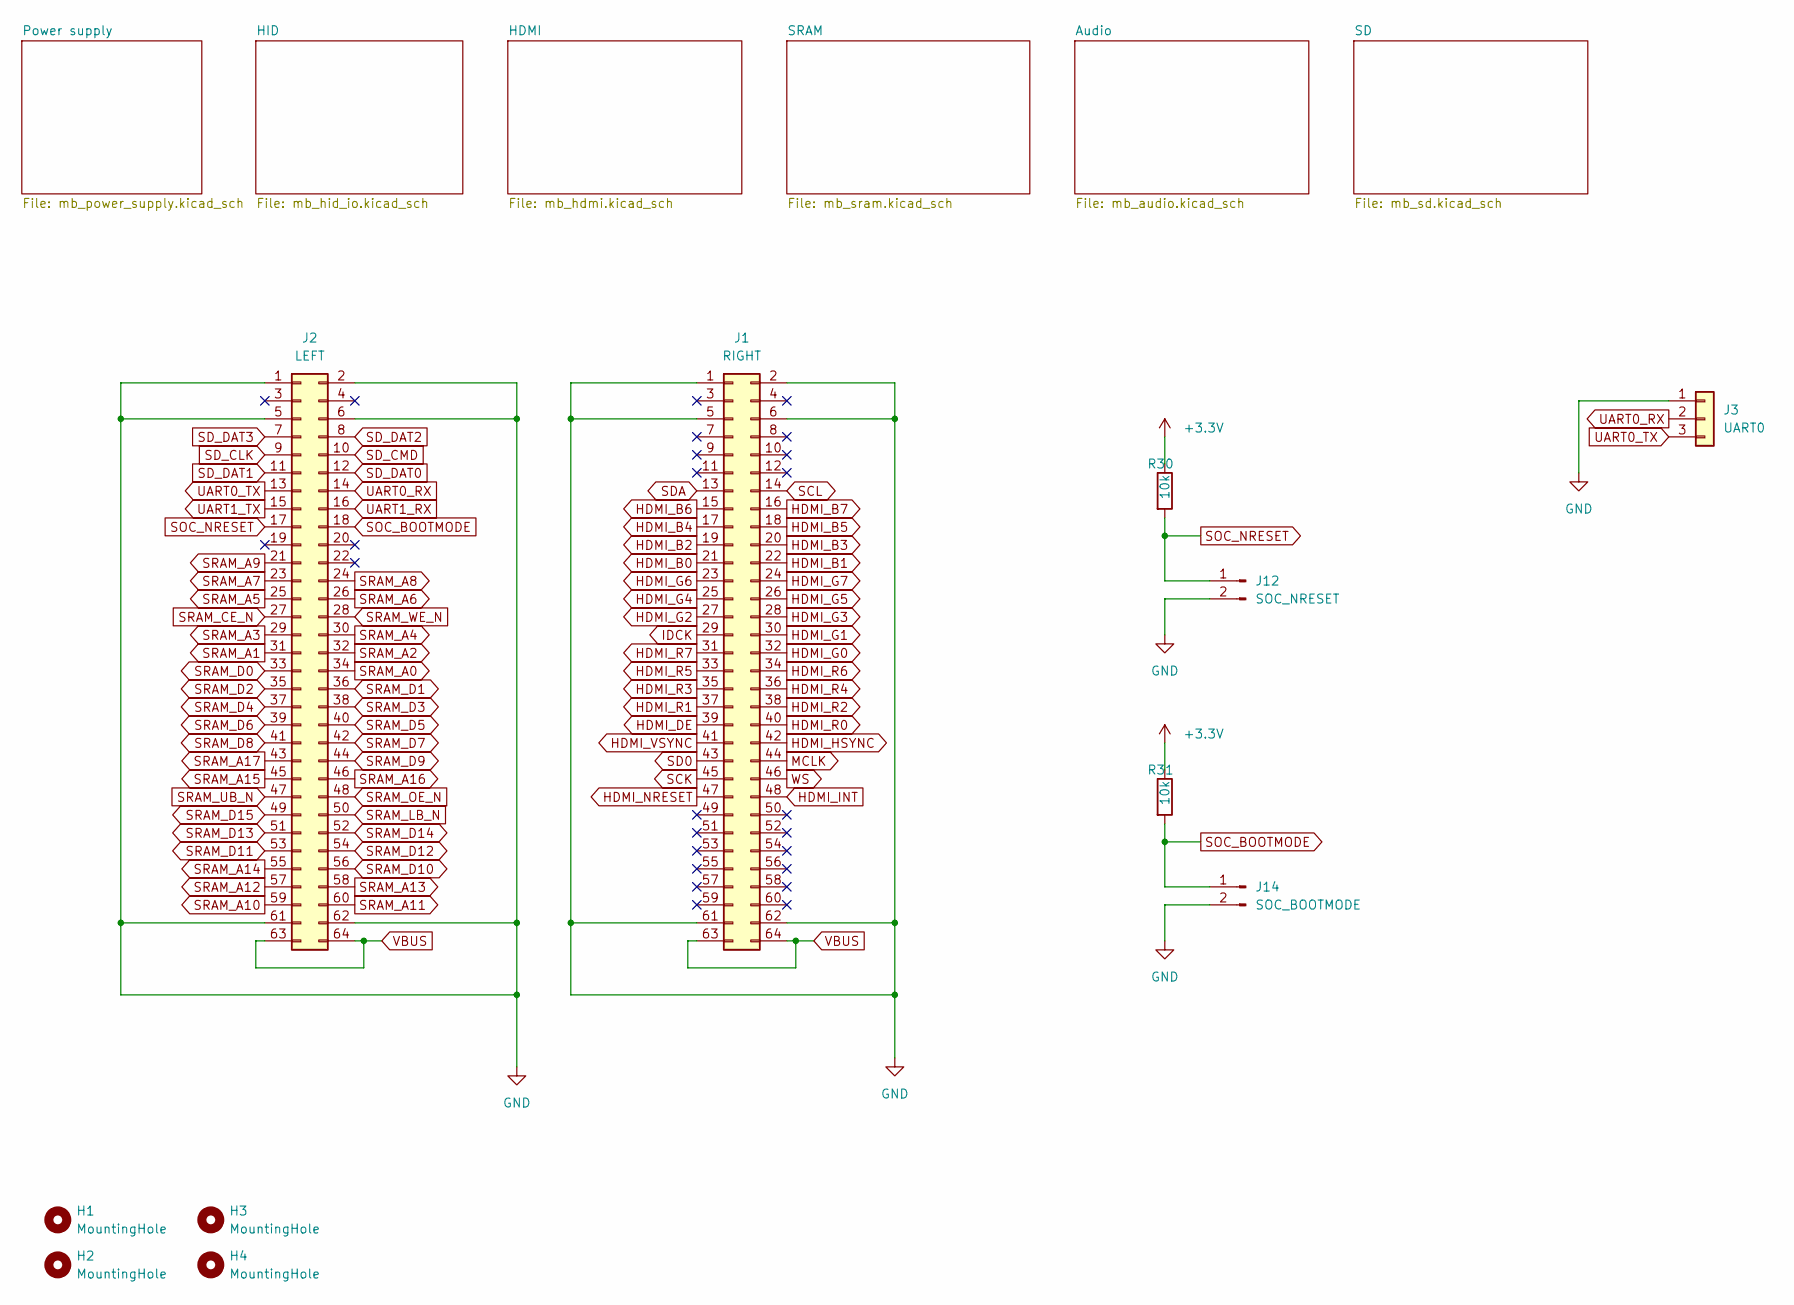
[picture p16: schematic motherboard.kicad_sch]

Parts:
H1, H2, H3, H4: MountingHole; MountingHole_3.2mm_M3_Pad_Via
J1: RIGHT; PinSocket_2x32_P2.54mm_Vertical
J2: LEFT; PinSocket_2x32_P2.54mm_Vertical
J3: UART0; PinHeader_1x03_P2.54mm_Vertical
J12: SOC_NRESET; PinHeader_1x02_P2.54mm_Vertical
J14: SOC_BOOTMODE; PinHeader_1x02_P2.54mm_Vertical
R30, R31: 10k; R_0805_2012Metric_Pad1.20x1.40mm_HandSolder

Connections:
+3V3: R30.1, R31.1; also elsewhere on the board
GND: J1.1, J1.2, J1.5, J1.6, J1.61, J1.62, J2.1, J2.2, J2.5, J2.6, J2.61, J2.62, J3.1, J12.2, J14.2; also elsewhere on the board
HDMI_B0: J1.21; also elsewhere on the board
HDMI_B1: J1.22; also elsewhere on the board
HDMI_B2: J1.19; also elsewhere on the board
HDMI_B3: J1.20; also elsewhere on the board
HDMI_B4: J1.17; also elsewhere on the board
HDMI_B5: J1.18; also elsewhere on the board
HDMI_B6: J1.15; also elsewhere on the board
HDMI_B7: J1.16; also elsewhere on the board
HDMI_DE: J1.39; also elsewhere on the board
HDMI_G0: J1.32; also elsewhere on the board
HDMI_G1: J1.30; also elsewhere on the board
HDMI_G2: J1.27; also elsewhere on the board
HDMI_G3: J1.28; also elsewhere on the board
HDMI_G4: J1.25; also elsewhere on the board
HDMI_G5: J1.26; also elsewhere on the board
HDMI_G6: J1.23; also elsewhere on the board
HDMI_G7: J1.24; also elsewhere on the board
HDMI_HSYNC: J1.42; also elsewhere on the board
HDMI_INT: J1.48; also elsewhere on the board
HDMI_NRESET: J1.47; also elsewhere on the board
HDMI_R0: J1.40; also elsewhere on the board
HDMI_R1: J1.37; also elsewhere on the board
HDMI_R2: J1.38; also elsewhere on the board
HDMI_R3: J1.35; also elsewhere on the board
HDMI_R4: J1.36; also elsewhere on the board
HDMI_R5: J1.33; also elsewhere on the board
HDMI_R6: J1.34; also elsewhere on the board
HDMI_R7: J1.31; also elsewhere on the board
HDMI_VSYNC: J1.41; also elsewhere on the board
IDCK: J1.29; also elsewhere on the board
MCLK: J1.44; also elsewhere on the board
SCK: J1.45; also elsewhere on the board
SCL: J1.14; also elsewhere on the board
SD0: J1.43; also elsewhere on the board
SDA: J1.13; also elsewhere on the board
SD_CLK: J2.9; also elsewhere on the board
SD_CMD: J2.10; also elsewhere on the board
SD_DAT0: J2.12; also elsewhere on the board
SD_DAT1: J2.11; also elsewhere on the board
SD_DAT2: J2.8; also elsewhere on the board
SD_DAT3: J2.7; also elsewhere on the board
SOC_BOOTMODE: J2.18, J14.1, R31.2
SOC_NRESET: J2.17, J12.1, R30.2
SRAM_A0: J2.34; also elsewhere on the board
SRAM_A1: J2.31; also elsewhere on the board
SRAM_A2: J2.32; also elsewhere on the board
SRAM_A3: J2.29; also elsewhere on the board
SRAM_A4: J2.30; also elsewhere on the board
SRAM_A5: J2.25; also elsewhere on the board
SRAM_A6: J2.26; also elsewhere on the board
SRAM_A7: J2.23; also elsewhere on the board
SRAM_A8: J2.24; also elsewhere on the board
SRAM_A9: J2.21; also elsewhere on the board
SRAM_A10: J2.59; also elsewhere on the board
SRAM_A11: J2.60; also elsewhere on the board
SRAM_A12: J2.57; also elsewhere on the board
SRAM_A13: J2.58; also elsewhere on the board
SRAM_A14: J2.55; also elsewhere on the board
SRAM_A15: J2.45; also elsewhere on the board
SRAM_A16: J2.46; also elsewhere on the board
SRAM_A17: J2.43; also elsewhere on the board
SRAM_CE_N: J2.27; also elsewhere on the board
SRAM_D0: J2.33; also elsewhere on the board
SRAM_D1: J2.36; also elsewhere on the board
SRAM_D2: J2.35; also elsewhere on the board
SRAM_D3: J2.38; also elsewhere on the board
SRAM_D4: J2.37; also elsewhere on the board
SRAM_D5: J2.40; also elsewhere on the board
SRAM_D6: J2.39; also elsewhere on the board
SRAM_D7: J2.42; also elsewhere on the board
SRAM_D8: J2.41; also elsewhere on the board
SRAM_D9: J2.44; also elsewhere on the board
SRAM_D10: J2.56; also elsewhere on the board
SRAM_D11: J2.53; also elsewhere on the board
SRAM_D12: J2.54; also elsewhere on the board
SRAM_D13: J2.51; also elsewhere on the board
SRAM_D14: J2.52; also elsewhere on the board
SRAM_D15: J2.49; also elsewhere on the board
SRAM_LB_N: J2.50; also elsewhere on the board
SRAM_OE_N: J2.48; also elsewhere on the board
SRAM_UB_N: J2.47; also elsewhere on the board
SRAM_WE_N: J2.28; also elsewhere on the board
UART0_RX: J2.14, J3.2
UART0_TX: J2.13, J3.3
UART1_RX: J2.16; also elsewhere on the board
UART1_TX: J2.15; also elsewhere on the board
VBUS: J1.63, J1.64, J2.63, J2.64; also elsewhere on the board
WS: J1.46; also elsewhere on the board

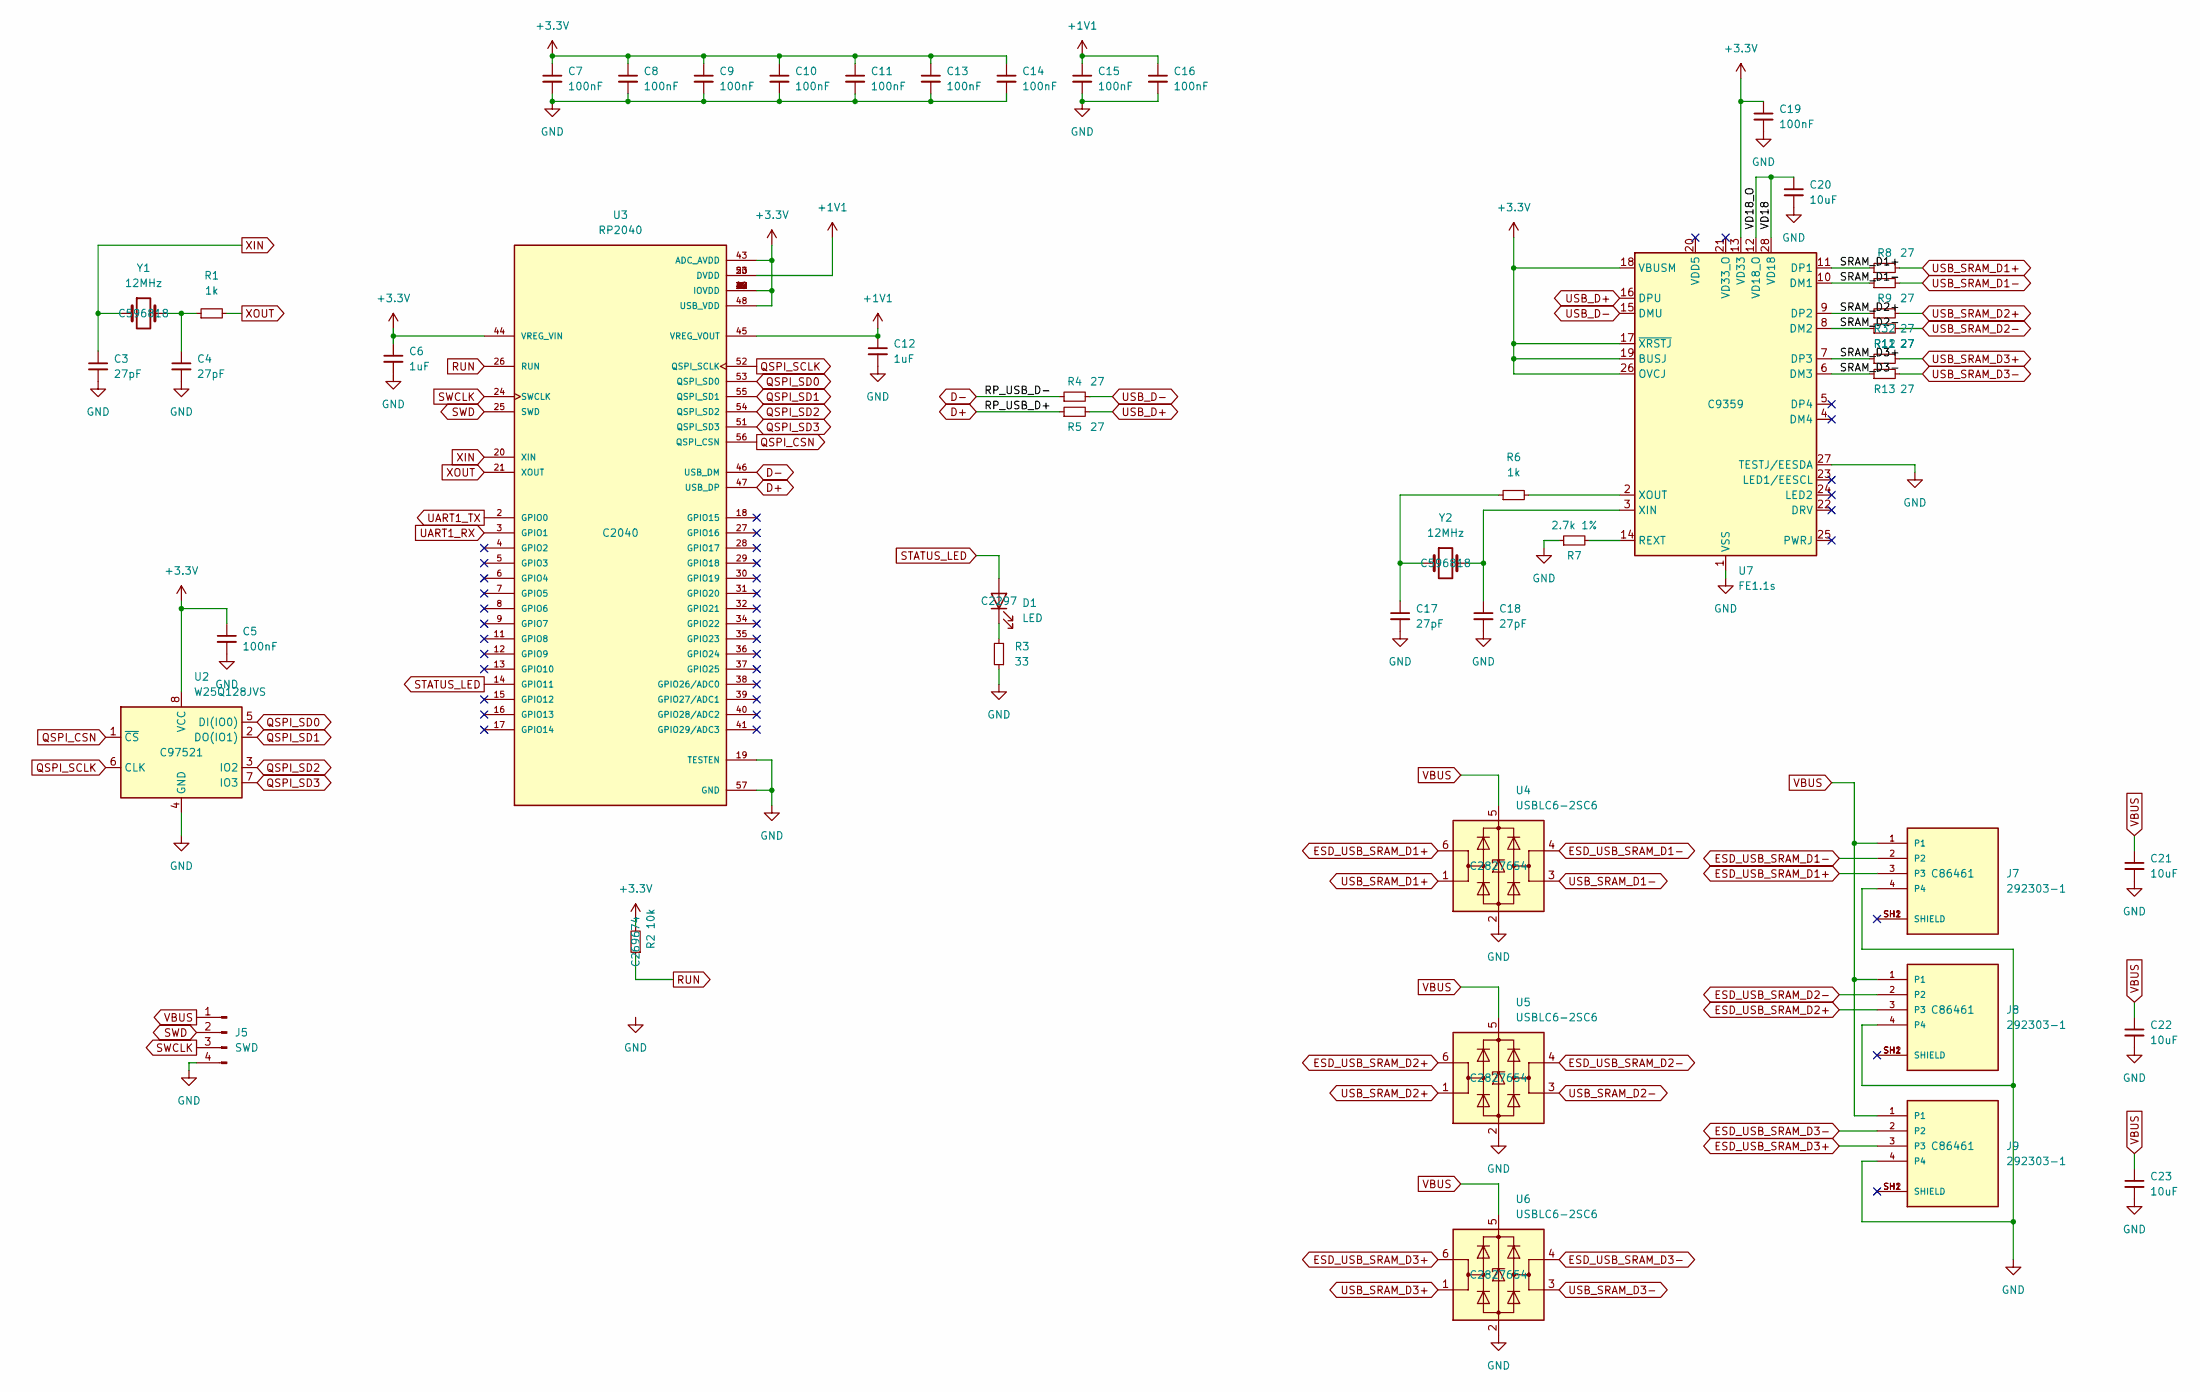
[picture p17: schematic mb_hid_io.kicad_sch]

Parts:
C3, C4, C17, C18: 27pF; C_0805_2012Metric
C5, C7, C8, C9, C10, C11, C13, C14, C15, C16, C19: 100nF; C_0402_1005Metric; LCSC C307331
C6, C12: 1uF; C_0402_1005Metric
C20: 10uF; C_0402_1005Metric
C21, C22, C23: 10uF; C_0805_2012Metric
D1: LED; LED_0805_2012Metric; LCSC C2297
J5: SWD; PinHeader_1x04_P2.54mm_Vertical
J7, J8, J9: 292303-1; TE_292303-1
R1, R6: 1k; R_0805_2012Metric
R2: 10k; R_0402_1005Metric; LCSC C269674
R3: 33; R_0805_2012Metric
R4, R5: 27; R_0805_2012Metric
R7: 2.7k 1%; R_0402_1005Metric; LCSC C25885
R8, R9, R11, R12, R13, R32: 27; R_0402_1005Metric
U2: W25Q128JVS; SOIC-8_5.23x5.23mm_P1.27mm; LCSC C97521
U3: RP2040; QFN40P700X700X90-57N; PARTREV 1.6.1; LCSC C2040
U4, U5, U6: USBLC6-2SC6; SOT-23-6
U7: FE1.1s; SSOP-28_3.9x9.9mm_P0.635mm; LCSC C9359
Y1, Y2: 12MHz; Crystal_SMD_HC49-SD

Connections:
+1V1: C12.1, C15.1, C16.1, U3.23 (DVDD), U3.45 (VREG_VOUT), U3.50 (DVDD)
+3V3: C5.1, C6.1, C7.1, C8.1, C9.1, C10.1, C11.1, C13.1, C14.1, C19.1, R2.2, U2.8 (VCC), U3.1 (IOVDD), U3.10 (IOVDD), U3.22 (IOVDD), U3.33 (IOVDD), U3.42 (IOVDD), U3.43 (ADC_AVDD), U3.44 (VREG_VIN), U3.48 (USB_VDD), U3.49 (IOVDD), U7.13 (VD33), U7.17 (~XRSTJ), U7.18 (VBUSM), U7.19 (BUSJ), U7.26 (OVCJ); also elsewhere on the board
/HID/SRAM_D1+: R8.1, U7.11 (DP1)
/HID/SRAM_D1-: R9.1, U7.10 (DM1)
/HID/SRAM_D2+: R32.1, U7.9 (DP2)
/HID/SRAM_D2-: R11.1, U7.8 (DM2)
/HID/SRAM_D3+: R12.1, U7.7 (DP3)
/HID/SRAM_D3-: R13.1, U7.6 (DM3)
/HID/VD18: C20.1, U7.12 (VD18_O), U7.28 (VD18)
D+: R5.1, U3.47 (USB_DP)
D-: R4.1, U3.46 (USB_DM)
ESD_USB_SRAM_D1+: J7.3, U4.6 (I/O1)
ESD_USB_SRAM_D1-: J7.2, U4.4 (I/O2)
ESD_USB_SRAM_D2+: J8.3, U5.6 (I/O1)
ESD_USB_SRAM_D2-: J8.2, U5.4 (I/O2)
ESD_USB_SRAM_D3+: J9.3, U6.6 (I/O1)
ESD_USB_SRAM_D3-: J9.2, U6.4 (I/O2)
GND: C3.2, C4.2, C5.2, C6.2, C7.2, C8.2, C9.2, C10.2, C11.2, C12.2, C13.2, C14.2, C15.2, C16.2, C17.2, C18.2, C19.2, C20.2, C21.2, C22.2, C23.2, J5.4, J7.4, J8.4, J9.4, R3.1, R7.1, U2.4 (GND), U3.19 (TESTEN), U3.57 (GND), U4.2 (GND), U5.2 (GND), U6.2 (GND), U7.1 (VSS), U7.27 (TESTJ/EESDA); also elsewhere on the board
unnamed: C4.1, R1.1, Y1.2
unnamed: C17.1, R6.1, Y2.1
unnamed: C18.1, U7.3 (XIN), Y2.2
unnamed: D1.1 (K), R3.2
unnamed: R6.2, U7.2 (XOUT)
unnamed: R7.2, U7.14 (REXT)
QSPI_CSN: U2.1 (~CS), U3.56 (QSPI_CSN)
QSPI_SCLK: U2.6 (CLK), U3.52 (QSPI_SCLK)
QSPI_SD0: U2.5 (DI(IO0)), U3.53 (QSPI_SD0)
QSPI_SD1: U2.2 (DO(IO1)), U3.55 (QSPI_SD1)
QSPI_SD2: U2.3 (IO2), U3.54 (QSPI_SD2)
QSPI_SD3: U2.7 (IO3), U3.51 (QSPI_SD3)
RUN: R2.1, U3.26 (RUN)
STATUS_LED: D1.2 (A), U3.14 (GPIO11)
SWCLK: J5.3, U3.24 (SWCLK)
SWD: J5.2, U3.25 (SWD)
UART1_RX: U3.3 (GPIO1); also elsewhere on the board
UART1_TX: U3.2 (GPIO0); also elsewhere on the board
USB_D+: R5.2, U7.16 (DPU)
USB_D-: R4.2, U7.15 (DMU)
USB_SRAM_D1+: R8.2, U4.1 (I/O1)
USB_SRAM_D1-: R9.2, U4.3 (I/O2)
USB_SRAM_D2+: R32.2, U5.1 (I/O1)
USB_SRAM_D2-: R11.2, U5.3 (I/O2)
USB_SRAM_D3+: R12.2, U6.1 (I/O1)
USB_SRAM_D3-: R13.2, U6.3 (I/O2)
VBUS: C21.1, C22.1, C23.1, J5.1, J7.1, J8.1, J9.1, U4.5 (VBUS), U5.5 (VBUS), U6.5 (VBUS); also elsewhere on the board
XIN: C3.1, U3.20 (XIN), Y1.1
XOUT: R1.2, U3.21 (XOUT)

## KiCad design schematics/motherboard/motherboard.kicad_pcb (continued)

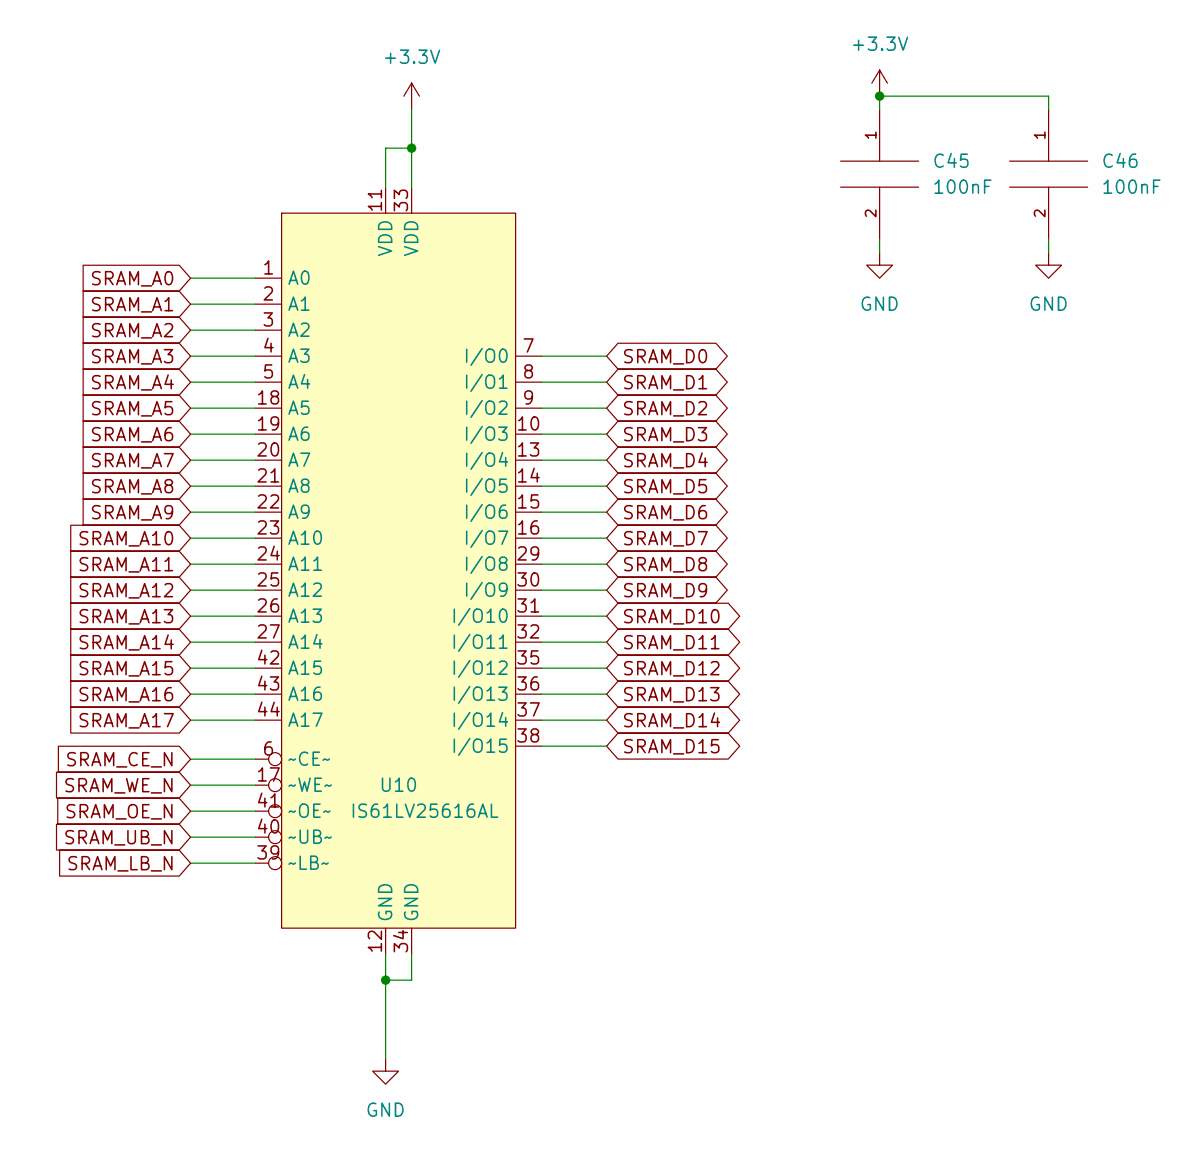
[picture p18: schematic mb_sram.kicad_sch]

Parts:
C45, C46: 100nF; C_0805_2012Metric_Pad1.18x1.45mm_HandSolder
U10: IS61LV25616AL; TSOP-II-44_10.16x18.41mm_P0.8mm

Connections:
+3V3: C45.1, C46.1, U10.11 (VDD), U10.33 (VDD); also elsewhere on the board
GND: C45.2, C46.2, U10.12 (GND), U10.34 (GND); also elsewhere on the board
SRAM_A0: U10.1 (A0); also elsewhere on the board
SRAM_A1: U10.2 (A1); also elsewhere on the board
SRAM_A2: U10.3 (A2); also elsewhere on the board
SRAM_A3: U10.4 (A3); also elsewhere on the board
SRAM_A4: U10.5 (A4); also elsewhere on the board
SRAM_A5: U10.18 (A5); also elsewhere on the board
SRAM_A6: U10.19 (A6); also elsewhere on the board
SRAM_A7: U10.20 (A7); also elsewhere on the board
SRAM_A8: U10.21 (A8); also elsewhere on the board
SRAM_A9: U10.22 (A9); also elsewhere on the board
SRAM_A10: U10.23 (A10); also elsewhere on the board
SRAM_A11: U10.24 (A11); also elsewhere on the board
SRAM_A12: U10.25 (A12); also elsewhere on the board
SRAM_A13: U10.26 (A13); also elsewhere on the board
SRAM_A14: U10.27 (A14); also elsewhere on the board
SRAM_A15: U10.42 (A15); also elsewhere on the board
SRAM_A16: U10.43 (A16); also elsewhere on the board
SRAM_A17: U10.44 (A17); also elsewhere on the board
SRAM_CE_N: U10.6 (~CE~); also elsewhere on the board
SRAM_D0: U10.7 (I/O0); also elsewhere on the board
SRAM_D1: U10.8 (I/O1); also elsewhere on the board
SRAM_D2: U10.9 (I/O2); also elsewhere on the board
SRAM_D3: U10.10 (I/O3); also elsewhere on the board
SRAM_D4: U10.13 (I/O4); also elsewhere on the board
SRAM_D5: U10.14 (I/O5); also elsewhere on the board
SRAM_D6: U10.15 (I/O6); also elsewhere on the board
SRAM_D7: U10.16 (I/O7); also elsewhere on the board
SRAM_D8: U10.29 (I/O8); also elsewhere on the board
SRAM_D9: U10.30 (I/O9); also elsewhere on the board
SRAM_D10: U10.31 (I/O10); also elsewhere on the board
SRAM_D11: U10.32 (I/O11); also elsewhere on the board
SRAM_D12: U10.35 (I/O12); also elsewhere on the board
SRAM_D13: U10.36 (I/O13); also elsewhere on the board
SRAM_D14: U10.37 (I/O14); also elsewhere on the board
SRAM_D15: U10.38 (I/O15); also elsewhere on the board
SRAM_LB_N: U10.39 (~LB~); also elsewhere on the board
SRAM_OE_N: U10.41 (~OE~); also elsewhere on the board
SRAM_UB_N: U10.40 (~UB~); also elsewhere on the board
SRAM_WE_N: U10.17 (~WE~); also elsewhere on the board

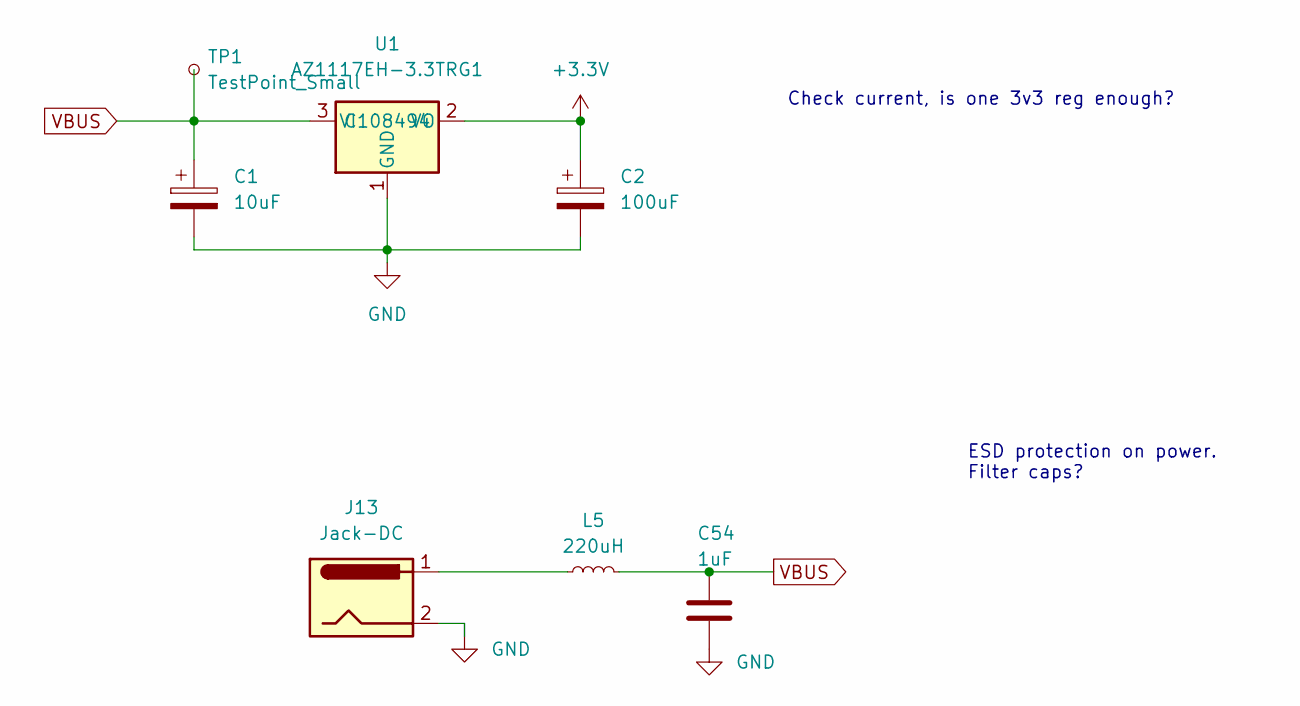
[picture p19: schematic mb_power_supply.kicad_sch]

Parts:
C1: 10uF; CP_Elec_5x5.3
C2: 100uF; CP_Elec_5x5.3
C54: 1uF; C_0805_2012Metric_Pad1.18x1.45mm_HandSolder
J13: Jack-DC; BarrelJack_CLIFF_FC681465S_SMT_Horizontal
L5: 220uH; L_0805_2012Metric
TP1: TestPoint_Small; TestPoint_Pad_D1.5mm
U1: AZ1117EH-3.3TRG1; SOT-223-3_TabPin2; LCSC C108494

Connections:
+3V3: C2.1, U1.2 (VO); also elsewhere on the board
GND: C1.2, C2.2, C54.2, J13.2, U1.1 (GND); also elsewhere on the board
unnamed: J13.1, L5.1
VBUS: C1.1, C54.1, L5.2, TP1.1, U1.3 (VI); also elsewhere on the board

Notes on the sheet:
Check current, is one 3v3 reg enough?
ESD protection on power. Filter caps?

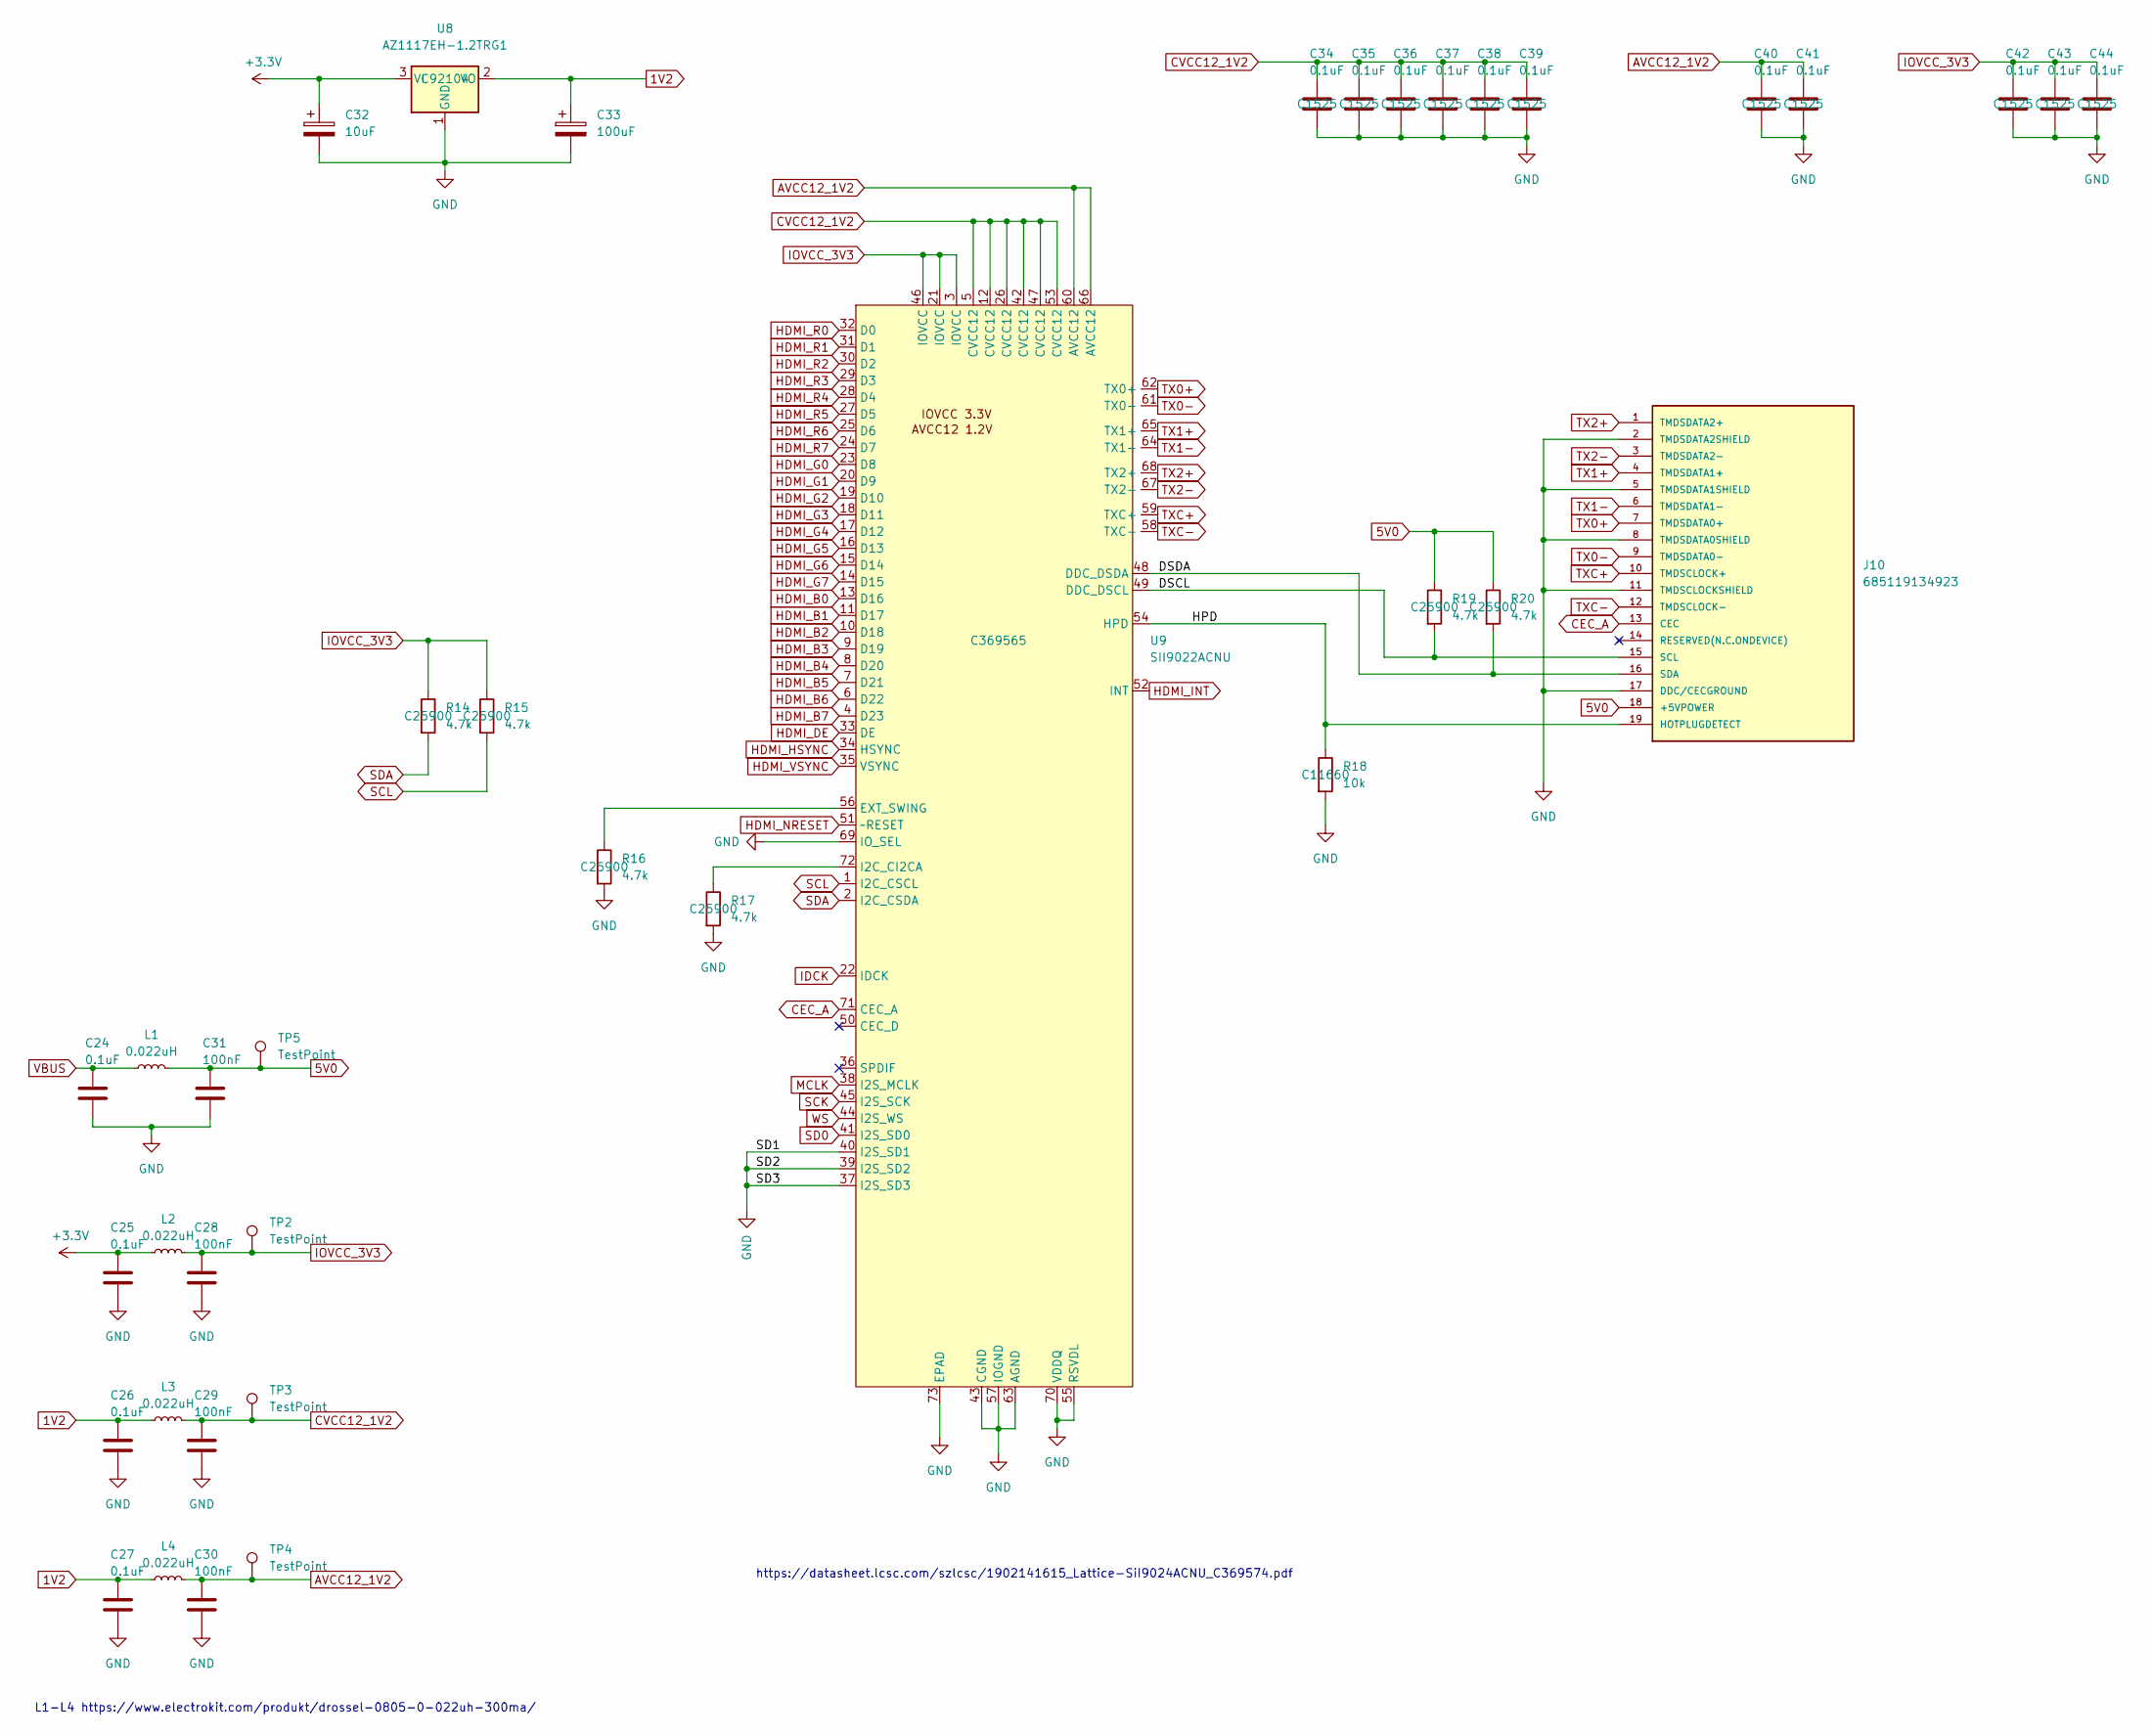
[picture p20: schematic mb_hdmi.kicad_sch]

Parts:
C24, C25, C26, C27: 0.1uF; C_0805_2012Metric_Pad1.18x1.45mm_HandSolder
C28, C29, C30, C31: 100nF; C_0805_2012Metric_Pad1.18x1.45mm_HandSolder
C32: 10uF; CP_Elec_5x5.3
C33: 100uF; CP_Elec_5x5.3
C34, C35, C36, C37, C38, C39, C40, C41, C42, C43, C44: 0.1uF; C_0402_1005Metric; LCSC C1525
J10: 685119134923; LCSC C720616
L1: 0.022uH; L_0805_2012Metric_Pad1.05x1.20mm_HandSolder
L2, L3, L4: 0.022uH; L_0805_2012Metric_Pad1.15x1.40mm_HandSolder
R14, R15, R16, R17, R19, R20: 4.7k; R_0402_1005Metric; LCSC C25900
R18: 10k; R_0402_1005Metric; LCSC C11660
TP2, TP3, TP4, TP5: TestPoint; TestPoint_Pad_D1.0mm
U8: AZ1117EH-1.2TRG1; SOT-223-3_TabPin2; LCSC C92104
U9: SII9022ACNU; QFN-72-1EP_10x10mm_P0.5mm_EP6x6mm; LCSC C369565

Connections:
1V2: C26.1, C27.1, C33.1, L3.1, L4.1, U8.2 (VO)
5V0: C31.1, J10.18 (+5VPOWER), L1.2, R19.1, R20.1, TP5.1
+3V3: C25.1, C32.1, L2.1, U8.3 (VI); also elsewhere on the board
/HDMI/DSCL: J10.15 (SCL), R19.2, U9.49 (DDC_DSCL)
/HDMI/DSDA: J10.16 (SDA), R20.2, U9.48 (DDC_DSDA)
/HDMI/HPD: J10.19 (HOTPLUGDETECT), R18.1, U9.54 (HPD)
AVCC12_1V2: C30.1, C40.1, C41.1, L4.2, TP4.1, U9.60 (AVCC12), U9.66 (AVCC12)
CEC_A: J10.13 (CEC), U9.71 (CEC_A)
CVCC12_1V2: C29.1, C34.1, C35.1, C36.1, C37.1, C38.1, C39.1, L3.2, TP3.1, U9.5 (CVCC12), U9.12 (CVCC12), U9.26 (CVCC12), U9.42 (CVCC12), U9.47 (CVCC12), U9.53 (CVCC12)
GND: C24.2, C25.2, C26.2, C27.2, C28.2, C29.2, C30.2, C31.2, C32.2, C33.2, C34.2, C35.2, C36.2, C37.2, C38.2, C39.2, C40.2, C41.2, C42.2, C43.2, C44.2, J10.2 (TMDSDATA2SHIELD), J10.5 (TMDSDATA1SHIELD), J10.8 (TMDSDATA0SHIELD), J10.11 (TMDSCLOCKSHIELD), J10.17 (DDC/CECGROUND), R16.2, R17.2, R18.2, U8.1 (GND), U9.37 (I2S_SD3), U9.39 (I2S_SD2), U9.40 (I2S_SD1), U9.43 (CGND), U9.55 (RSVDL), U9.57 (IOGND), U9.63 (AGND), U9.69 (IO_SEL), U9.70 (VDDQ), U9.73 (EPAD); also elsewhere on the board
HDMI_B0: U9.13 (D16); also elsewhere on the board
HDMI_B1: U9.11 (D17); also elsewhere on the board
HDMI_B2: U9.10 (D18); also elsewhere on the board
HDMI_B3: U9.9 (D19); also elsewhere on the board
HDMI_B4: U9.8 (D20); also elsewhere on the board
HDMI_B5: U9.7 (D21); also elsewhere on the board
HDMI_B6: U9.6 (D22); also elsewhere on the board
HDMI_B7: U9.4 (D23); also elsewhere on the board
HDMI_DE: U9.33 (DE); also elsewhere on the board
HDMI_G0: U9.23 (D8); also elsewhere on the board
HDMI_G1: U9.20 (D9); also elsewhere on the board
HDMI_G2: U9.19 (D10); also elsewhere on the board
HDMI_G3: U9.18 (D11); also elsewhere on the board
HDMI_G4: U9.17 (D12); also elsewhere on the board
HDMI_G5: U9.16 (D13); also elsewhere on the board
HDMI_G6: U9.15 (D14); also elsewhere on the board
HDMI_G7: U9.14 (D15); also elsewhere on the board
HDMI_HSYNC: U9.34 (HSYNC); also elsewhere on the board
HDMI_INT: U9.52 (INT); also elsewhere on the board
HDMI_NRESET: U9.51 (~RESET); also elsewhere on the board
HDMI_R0: U9.32 (D0); also elsewhere on the board
HDMI_R1: U9.31 (D1); also elsewhere on the board
HDMI_R2: U9.30 (D2); also elsewhere on the board
HDMI_R3: U9.29 (D3); also elsewhere on the board
HDMI_R4: U9.28 (D4); also elsewhere on the board
HDMI_R5: U9.27 (D5); also elsewhere on the board
HDMI_R6: U9.25 (D6); also elsewhere on the board
HDMI_R7: U9.24 (D7); also elsewhere on the board
HDMI_VSYNC: U9.35 (VSYNC); also elsewhere on the board
IDCK: U9.22 (IDCK); also elsewhere on the board
IOVCC_3V3: C28.1, C42.1, C43.1, C44.1, L2.2, R14.1, R15.1, TP2.1, U9.3 (IOVCC), U9.21 (IOVCC), U9.46 (IOVCC)
MCLK: U9.38 (I2S_MCLK); also elsewhere on the board
unnamed: R16.1, U9.56 (EXT_SWING)
unnamed: R17.1, U9.72 (I2C_CI2CA)
SCK: U9.45 (I2S_SCK); also elsewhere on the board
SCL: R15.2, U9.1 (I2C_CSCL); also elsewhere on the board
SD0: U9.41 (I2S_SD0); also elsewhere on the board
SDA: R14.2, U9.2 (I2C_CSDA); also elsewhere on the board
TX0+: J10.7 (TMDSDATA0+), U9.62 (TX0+)
TX0-: J10.9 (TMDSDATA0-), U9.61 (TX0-)
TX1+: J10.4 (TMDSDATA1+), U9.65 (TX1+)
TX1-: J10.6 (TMDSDATA1-), U9.64 (TX1-)
TX2+: J10.1 (TMDSDATA2+), U9.68 (TX2+)
TX2-: J10.3 (TMDSDATA2-), U9.67 (TX2-)
TXC+: J10.10 (TMDSCLOCK+), U9.59 (TXC+)
TXC-: J10.12 (TMDSCLOCK-), U9.58 (TXC-)
VBUS: C24.1, L1.1; also elsewhere on the board
WS: U9.44 (I2S_WS); also elsewhere on the board

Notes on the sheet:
L1-L4 https://www.electrokit.com/produkt/drossel-0805-0-022uh-300ma/
https://datasheet.lcsc.com/szlcsc/1902141615_Lattice-SiI9024ACNU_C369574.pdf

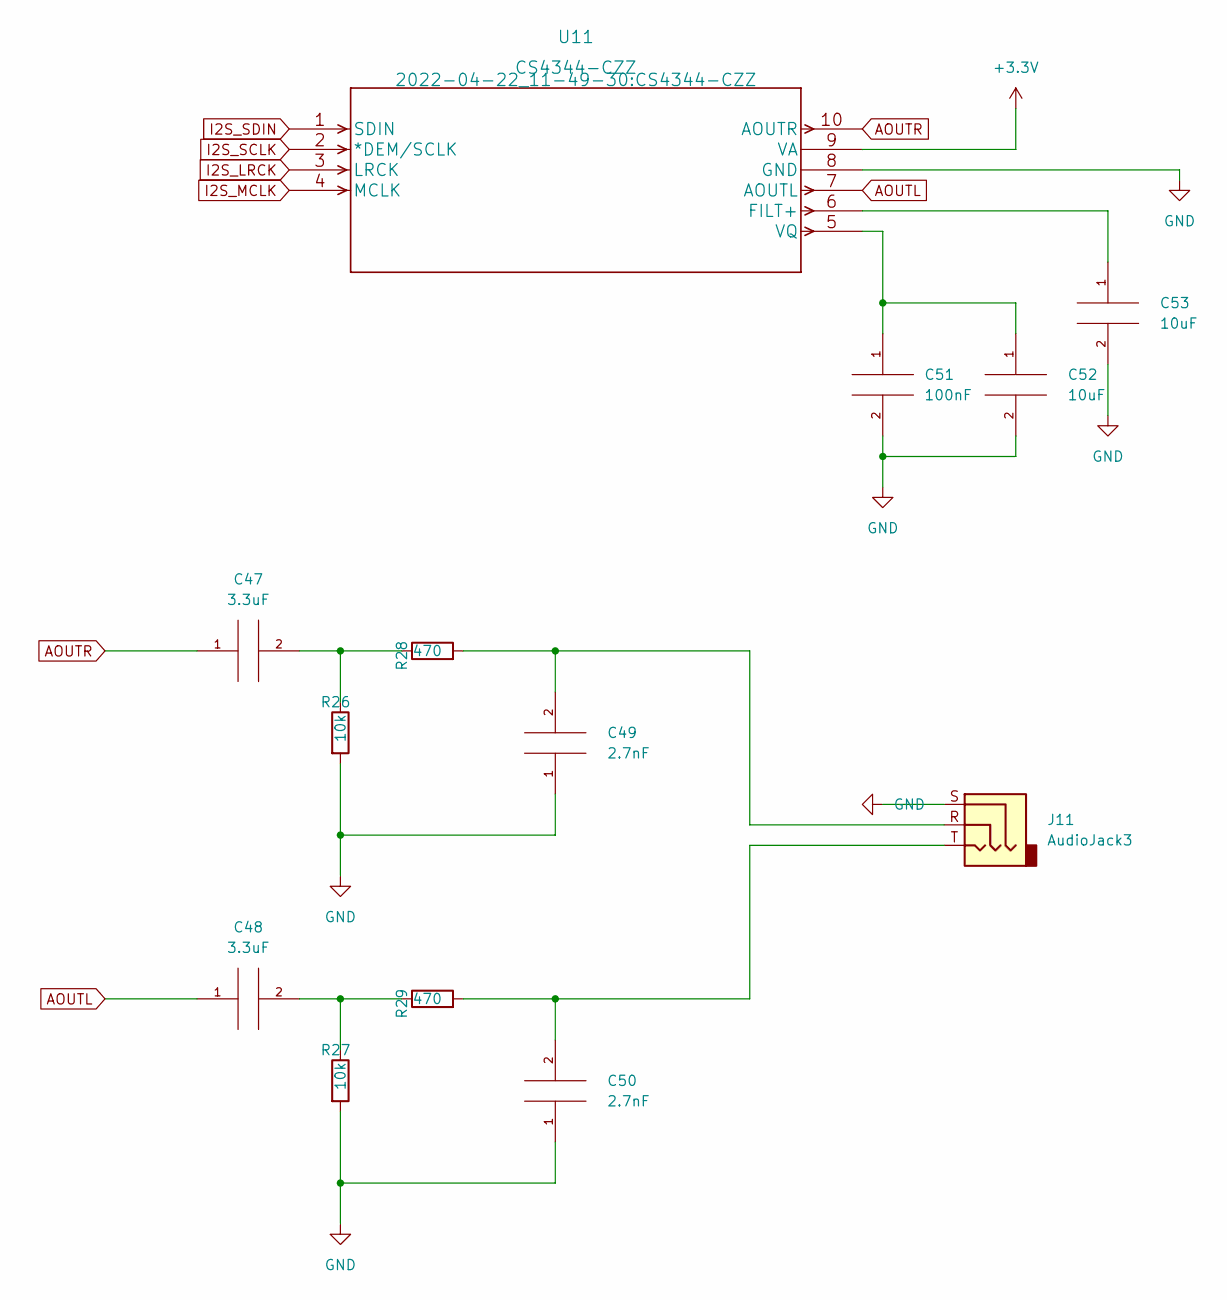
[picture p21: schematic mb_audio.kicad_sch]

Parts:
C47, C48: 3.3uF; C_0805_2012Metric_Pad1.18x1.45mm_HandSolder
C49, C50: 2.7nF; C_0805_2012Metric_Pad1.18x1.45mm_HandSolder
C51: 100nF; C_0805_2012Metric_Pad1.18x1.45mm_HandSolder
C52, C53: 10uF; C_0805_2012Metric_Pad1.18x1.45mm_HandSolder
J11: AudioJack3; Jack_3.5mm_CUI_SJ-3523-SMT_Horizontal
R26, R27: 10k; R_0805_2012Metric_Pad1.20x1.40mm_HandSolder
R28, R29: 470; R_0805_2012Metric_Pad1.20x1.40mm_HandSolder
U11: CS4344-CZZ

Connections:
+3V3: U11.9 (VA); also elsewhere on the board
AOUTL: C48.1, U11.7 (AOUTL)
AOUTR: C47.1, U11.10 (AOUTR)
GND: C49.1, C50.1, C51.2, C52.2, C53.2, J11.S, R26.2, R27.2, U11.8 (GND); also elsewhere on the board
I2S_LRCK: U11.3 (LRCK)
I2S_MCLK: U11.4 (MCLK)
I2S_SCLK: U11.2 (*DEM/SCLK)
I2S_SDIN: U11.1 (SDIN)
unnamed: C47.2, R26.1, R28.1
unnamed: C48.2, R27.1, R29.1
unnamed: C49.2, J11.R, R28.2
unnamed: C50.2, J11.T, R29.2
unnamed: C51.1, C52.1, U11.5 (VQ)
unnamed: C53.1, U11.6 (FILT+)

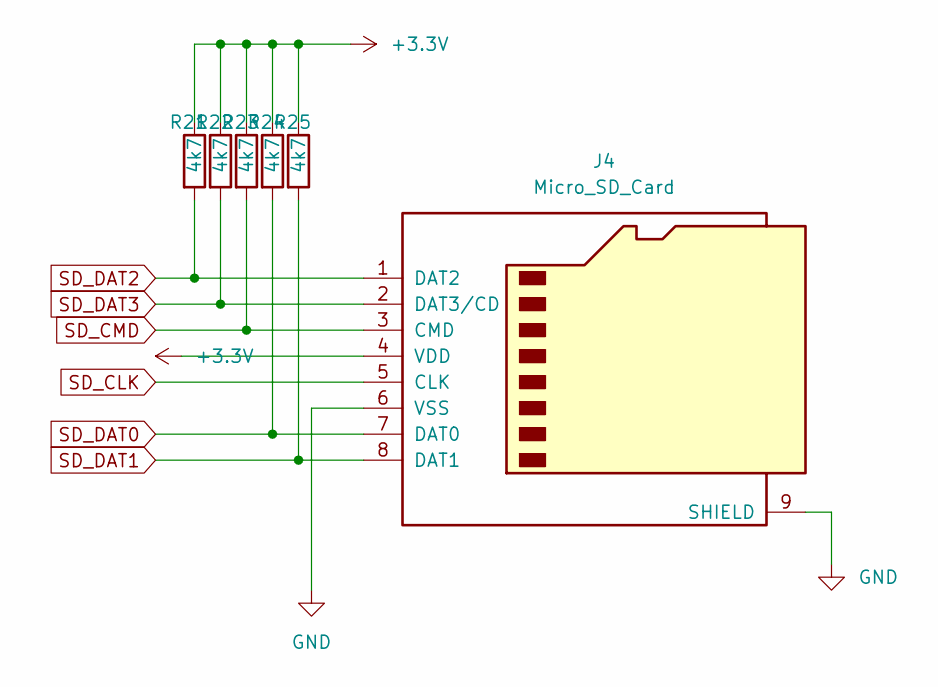
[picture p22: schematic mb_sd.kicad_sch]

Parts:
J4: Micro_SD_Card; microSD_HC_Hirose_DM3D-SF
R21, R22, R23, R24, R25: 4k7; R_0805_2012Metric_Pad1.20x1.40mm_HandSolder

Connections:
+3V3: J4.4 (VDD), R21.1, R22.1, R23.1, R24.1, R25.1; also elsewhere on the board
GND: J4.6 (VSS), J4.9 (SHIELD); also elsewhere on the board
SD_CLK: J4.5 (CLK); also elsewhere on the board
SD_CMD: J4.3 (CMD), R23.2; also elsewhere on the board
SD_DAT0: J4.7 (DAT0), R24.2; also elsewhere on the board
SD_DAT1: J4.8 (DAT1), R25.2; also elsewhere on the board
SD_DAT2: J4.1 (DAT2), R21.2; also elsewhere on the board
SD_DAT3: J4.2 (DAT3/CD), R22.2; also elsewhere on the board

Board: 4 copper layers, 126 parts (0 on the bottom side), 160 nets, no tracks yet.

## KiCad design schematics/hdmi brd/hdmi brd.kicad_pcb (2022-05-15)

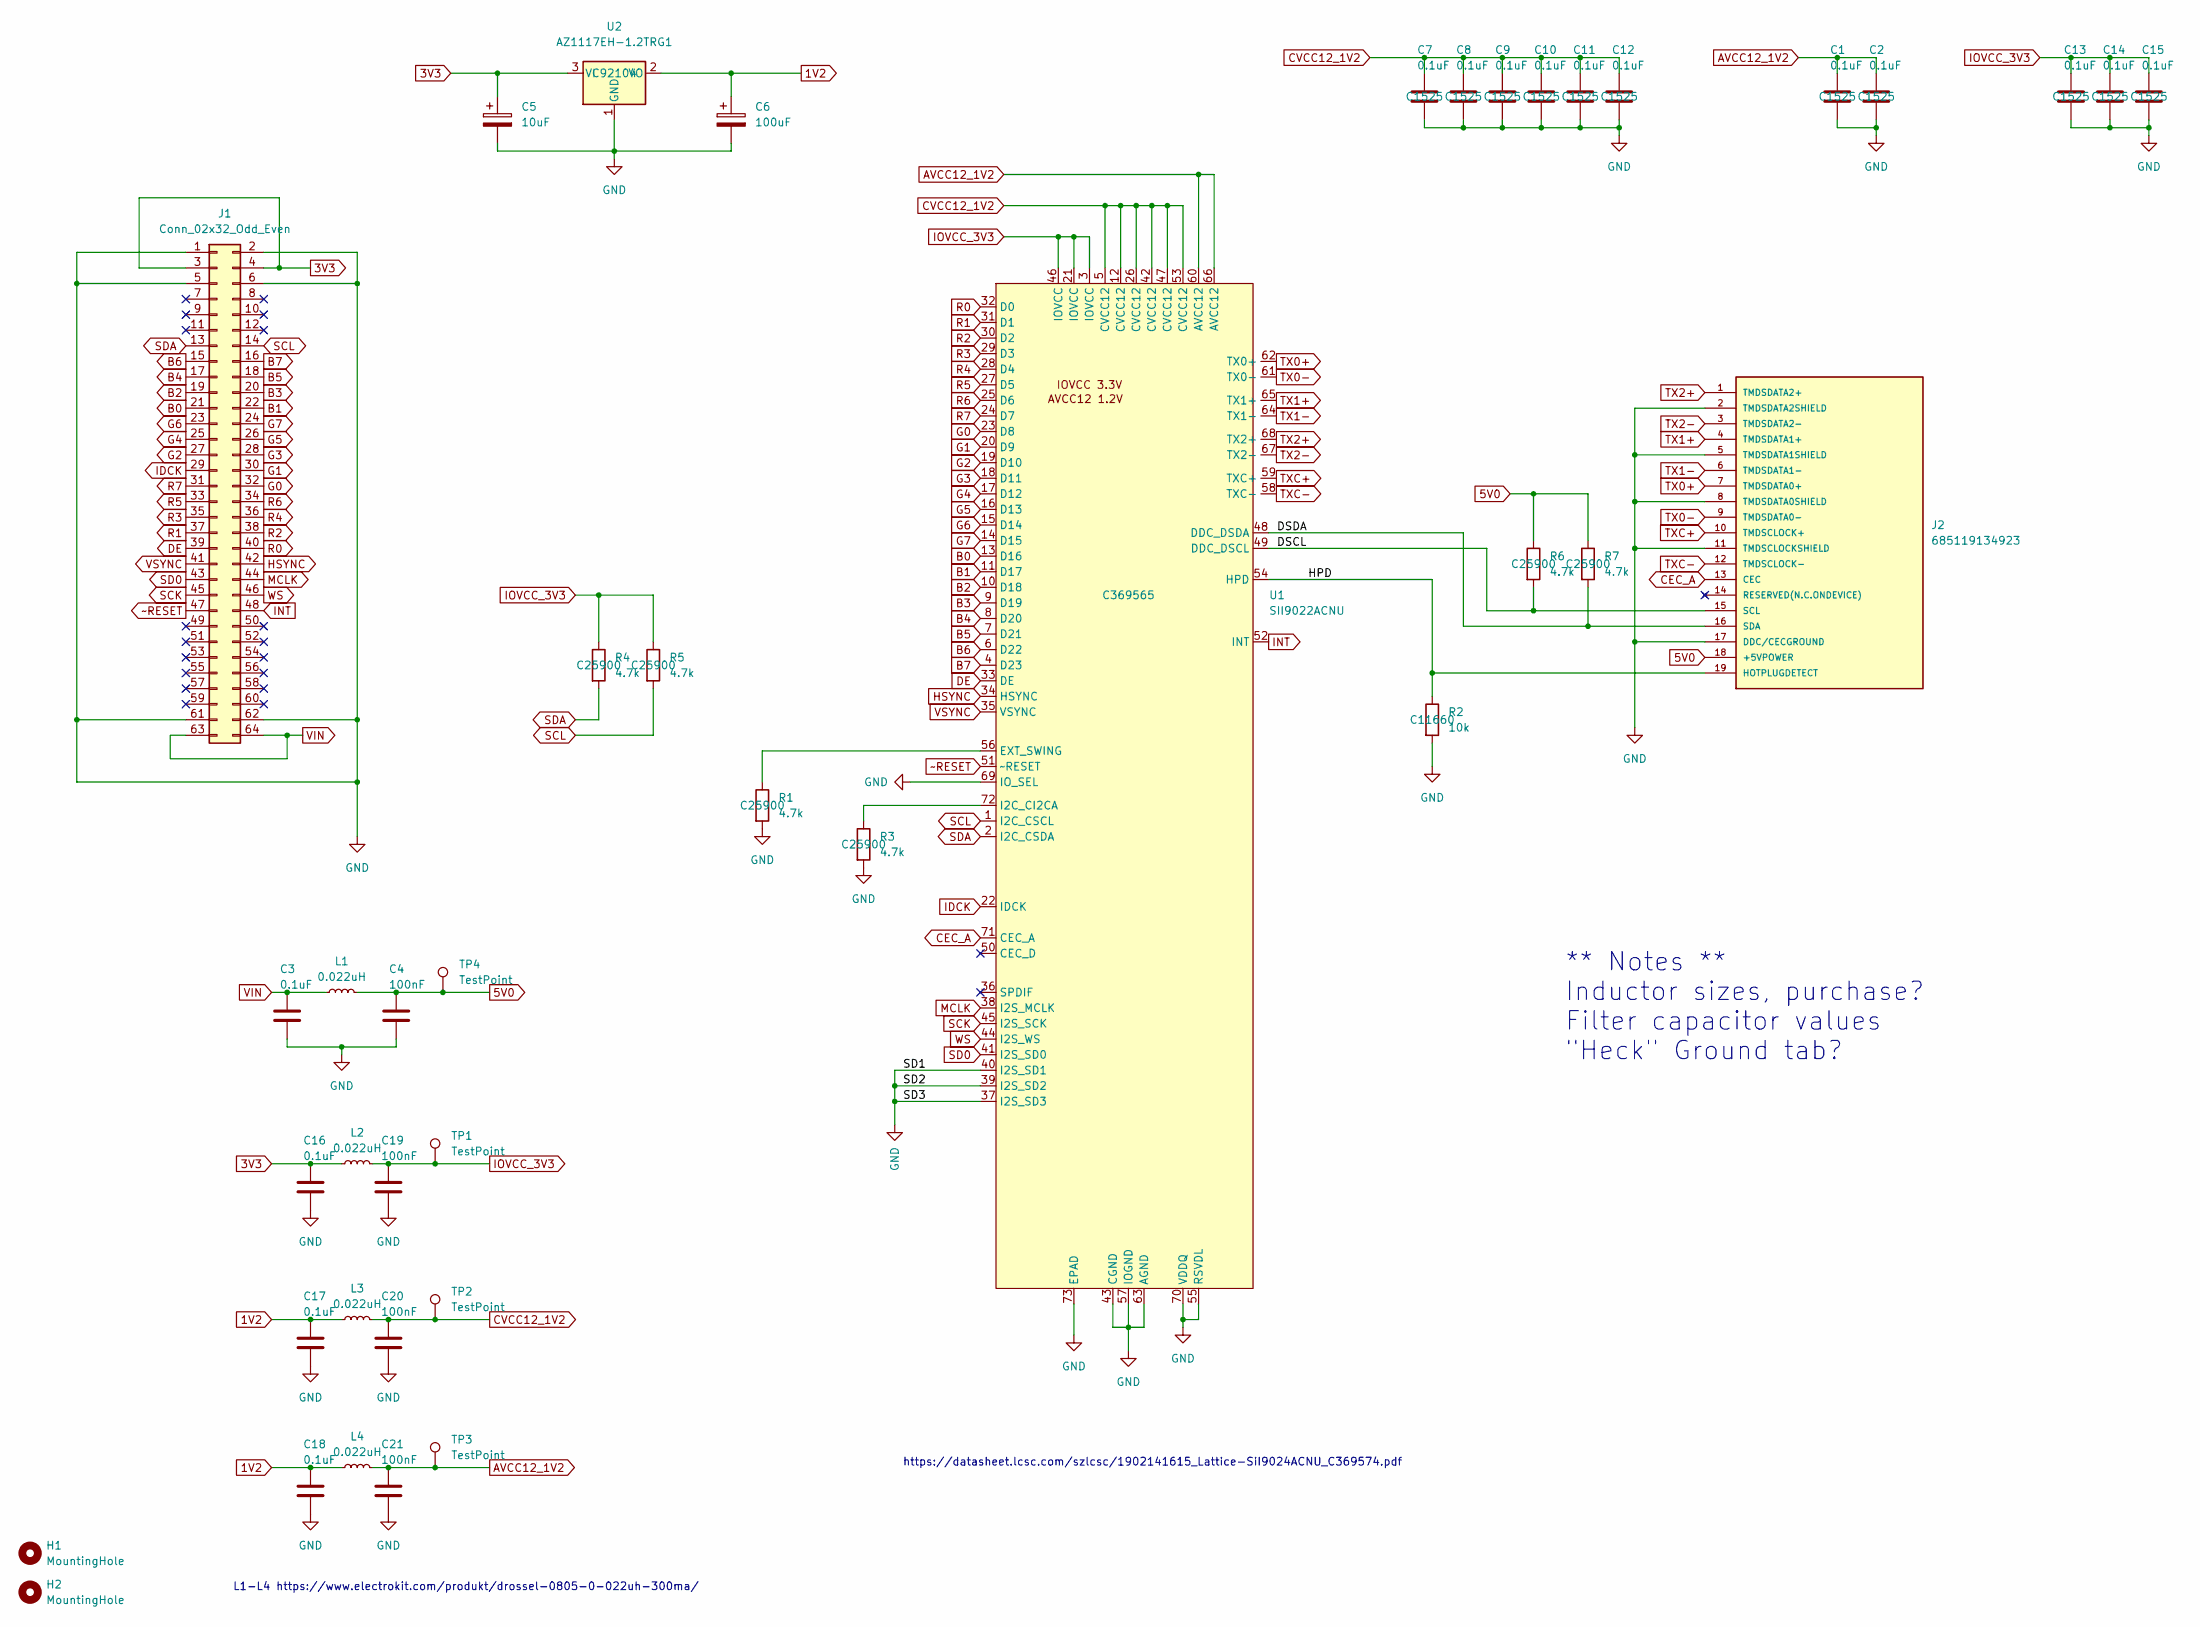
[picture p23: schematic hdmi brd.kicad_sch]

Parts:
C1, C2, C7, C8, C9, C10, C11, C12, C13, C14, C15: 0.1uF; C_0402_1005Metric; LCSC C1525
C3, C16, C17, C18: 0.1uF; C_0805_2012Metric_Pad1.18x1.45mm_HandSolder
C4, C19, C20, C21: 100nF; C_0805_2012Metric_Pad1.18x1.45mm_HandSolder
C5: 10uF; CP_Elec_5x5.3
C6: 100uF; CP_Elec_5x5.3
H1, H2: MountingHole; MountingHole_3.2mm_M3_DIN965_Pad
J1: Conn_02x32_Odd_Even; PinSocket_2x32_P2.54mm_Vertical
J2: 685119134923; LCSC C720616
L1: 0.022uH; L_0805_2012Metric_Pad1.05x1.20mm_HandSolder
L2, L3, L4: 0.022uH; L_0805_2012Metric_Pad1.15x1.40mm_HandSolder
R1, R3, R4, R5, R6, R7: 4.7k; R_0402_1005Metric; LCSC C25900
R2: 10k; R_0402_1005Metric; LCSC C11660
TP1, TP2, TP3, TP4: TestPoint; TestPoint_Pad_D1.0mm
U1: SII9022ACNU; QFN-72-1EP_10x10mm_P0.5mm_EP6x6mm; LCSC C369565
U2: AZ1117EH-1.2TRG1; SOT-223-3_TabPin2; LCSC C92104

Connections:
1V2: C6.1, C17.1, C18.1, L3.1, L4.1, U2.2 (VO)
3V3: C5.1, C16.1, J1.3, J1.4, L2.1, U2.3 (VI)
5V0: C4.1, J2.18 (+5VPOWER), L1.2, R6.1, R7.1, TP4.1
/DSCL: J2.15 (SCL), R6.2, U1.49 (DDC_DSCL)
/DSDA: J2.16 (SDA), R7.2, U1.48 (DDC_DSDA)
/HPD: J2.19 (HOTPLUGDETECT), R2.1, U1.54 (HPD)
AVCC12_1V2: C1.1, C2.1, C21.1, L4.2, TP3.1, U1.60 (AVCC12), U1.66 (AVCC12)
B0: J1.21, U1.13 (D16)
B1: J1.22, U1.11 (D17)
B2: J1.19, U1.10 (D18)
B3: J1.20, U1.9 (D19)
B4: J1.17, U1.8 (D20)
B5: J1.18, U1.7 (D21)
B6: J1.15, U1.6 (D22)
B7: J1.16, U1.4 (D23)
CEC_A: J2.13 (CEC), U1.71 (CEC_A)
CVCC12_1V2: C7.1, C8.1, C9.1, C10.1, C11.1, C12.1, C20.1, L3.2, TP2.1, U1.5 (CVCC12), U1.12 (CVCC12), U1.26 (CVCC12), U1.42 (CVCC12), U1.47 (CVCC12), U1.53 (CVCC12)
DE: J1.39, U1.33 (DE)
G0: J1.32, U1.23 (D8)
G1: J1.30, U1.20 (D9)
G2: J1.27, U1.19 (D10)
G3: J1.28, U1.18 (D11)
G4: J1.25, U1.17 (D12)
G5: J1.26, U1.16 (D13)
G6: J1.23, U1.15 (D14)
G7: J1.24, U1.14 (D15)
GND: C1.2, C2.2, C3.2, C4.2, C5.2, C6.2, C7.2, C8.2, C9.2, C10.2, C11.2, C12.2, C13.2, C14.2, C15.2, C16.2, C17.2, C18.2, C19.2, C20.2, C21.2, J1.1, J1.2, J1.5, J1.6, J1.61, J1.62, J2.2 (TMDSDATA2SHIELD), J2.5 (TMDSDATA1SHIELD), J2.8 (TMDSDATA0SHIELD), J2.11 (TMDSCLOCKSHIELD), J2.17 (DDC/CECGROUND), R1.2, R2.2, R3.2, U1.37 (I2S_SD3), U1.39 (I2S_SD2), U1.40 (I2S_SD1), U1.43 (CGND), U1.55 (RSVDL), U1.57 (IOGND), U1.63 (AGND), U1.69 (IO_SEL), U1.70 (VDDQ), U1.73 (EPAD), U2.1 (GND)
HSYNC: J1.42, U1.34 (HSYNC)
IDCK: J1.29, U1.22 (IDCK)
INT: J1.48, U1.52 (INT)
IOVCC_3V3: C13.1, C14.1, C15.1, C19.1, L2.2, R4.1, R5.1, TP1.1, U1.3 (IOVCC), U1.21 (IOVCC), U1.46 (IOVCC)
MCLK: J1.44, U1.38 (I2S_MCLK)
unnamed: R1.1, U1.56 (EXT_SWING)
unnamed: R3.1, U1.72 (I2C_CI2CA)
R0: J1.40, U1.32 (D0)
R1: J1.37, U1.31 (D1)
R2: J1.38, U1.30 (D2)
R3: J1.35, U1.29 (D3)
R4: J1.36, U1.28 (D4)
R5: J1.33, U1.27 (D5)
R6: J1.34, U1.25 (D6)
R7: J1.31, U1.24 (D7)
SCK: J1.45, U1.45 (I2S_SCK)
SCL: J1.14, R5.2, U1.1 (I2C_CSCL)
SD0: J1.43, U1.41 (I2S_SD0)
SDA: J1.13, R4.2, U1.2 (I2C_CSDA)
TX0+: J2.7 (TMDSDATA0+), U1.62 (TX0+)
TX0-: J2.9 (TMDSDATA0-), U1.61 (TX0-)
TX1+: J2.4 (TMDSDATA1+), U1.65 (TX1+)
TX1-: J2.6 (TMDSDATA1-), U1.64 (TX1-)
TX2+: J2.1 (TMDSDATA2+), U1.68 (TX2+)
TX2-: J2.3 (TMDSDATA2-), U1.67 (TX2-)
TXC+: J2.10 (TMDSCLOCK+), U1.59 (TXC+)
TXC-: J2.12 (TMDSCLOCK-), U1.58 (TXC-)
VIN: C3.1, J1.63, J1.64, L1.1
VSYNC: J1.41, U1.35 (VSYNC)
WS: J1.46, U1.44 (I2S_WS)
~RESET: J1.47, U1.51 (~RESET)

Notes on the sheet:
L1-L4 https://www.electrokit.com/produkt/drossel-0805-0-022uh-300ma/
https://datasheet.lcsc.com/szlcsc/1902141615_Lattice-SiI9024ACNU_C369574.pdf
** Notes ** Inductor sizes, purchase? Filter capacitor values "Heck" Ground tab?


Board: 2 copper layers, 42.7 x 83.8 mm, 42 parts (1 on the bottom side), 58 nets.

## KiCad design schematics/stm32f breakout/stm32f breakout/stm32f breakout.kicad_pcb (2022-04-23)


Board: 2 copper layers, 27.4 x 63.2 mm, 3 parts (0 on the bottom side), 46 nets.

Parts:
J1, J2: Conn_01x24_Male; PinHeader_1x24_P2.54mm_Vertical
U1: STM32F103C6Tx; LQFP-48_7x7mm_P0.5mm

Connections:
GND: J1.2, J1.14, J2.11, U1.23 (VSS), U1.35 (VSS), U1.47 (VSS)
unnamed: J1.3, U1.34 (PA13)
unnamed: J1.4, U1.33 (PA12)
unnamed: J1.5, U1.32 (PA11)
unnamed: J1.12, U1.25 (PB12)
unnamed: J1.15, U1.22 (PB11)
unnamed: J1.16, U1.21 (PB10)
unnamed: J1.17, U1.20 (PB2)
unnamed: J1.18, U1.19 (PB1)
unnamed: J1.19, U1.18 (PB0)
unnamed: J2.5, U1.41 (PB5)
unnamed: J2.6, U1.42 (PB6)
unnamed: J2.7, U1.43 (PB7)
unnamed: J2.8, U1.44 (BOOT0)
unnamed: J2.9, U1.45 (PB8)
unnamed: J2.10, U1.46 (PB9)
unnamed: J2.12, U1.48 (VDD)
unnamed: J2.13, U1.1 (VBAT)
unnamed: J2.14, U1.2 (PC13)
unnamed: J2.15, U1.3 (PC14)
unnamed: J2.16, U1.4 (PC15)
unnamed: J2.17, U1.5 (PD0)
unnamed: J2.22, U1.10 (PA0)
unnamed: J2.23, U1.11 (PA1)
unnamed: J2.24, U1.12 (PA2)
unnamed: J2.18, U1.6 (PD1)
unnamed: J2.19, U1.7 (NRST)
unnamed: J2.20, U1.8 (VSSA)
unnamed: J2.21, U1.9 (VDDA)
unnamed: J1.24, U1.13 (PA3)
unnamed: J1.23, U1.14 (PA4)
unnamed: J1.22, U1.15 (PA5)
unnamed: J1.21, U1.16 (PA6)
unnamed: J1.20, U1.17 (PA7)
unnamed: J1.13, U1.24 (VDD)
unnamed: J1.11, U1.26 (PB13)
unnamed: J1.10, U1.27 (PB14)
unnamed: J1.9, U1.28 (PB15)
unnamed: J1.8, U1.29 (PA8)
unnamed: J1.7, U1.30 (PA9)
unnamed: J1.6, U1.31 (PA10)
unnamed: J1.1, U1.36 (VDD)
unnamed: J2.1, U1.37 (PA14)
unnamed: J2.2, U1.38 (PA15)
unnamed: J2.3, U1.39 (PB3)
unnamed: J2.4, U1.40 (PB4)

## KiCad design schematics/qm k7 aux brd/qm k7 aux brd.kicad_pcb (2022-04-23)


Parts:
C1: 10uF; CP_Elec_5x5.3
C2: 100uF; CP_Elec_5x5.3
C3, C4: 3.3uF; C_0805_2012Metric_Pad1.18x1.45mm_HandSolder
C5, C6: 2.7nF; C_0805_2012Metric_Pad1.18x1.45mm_HandSolder
C7, C9: 10uF; C_0805_2012Metric_Pad1.18x1.45mm_HandSolder
C8: 100nF; C_0805_2012Metric_Pad1.18x1.45mm_HandSolder
H1, H2: MountingHole; MountingHole_3.2mm_M3_DIN965_Pad
J1: LEFT; PinSocket_2x32_P2.54mm_Vertical
J2: Micro_SD_Card; microSD_HC_Hirose_DM3D-SF
J3, J4: Conn_01x03; PinHeader_1x03_P2.54mm_Vertical
R1, R2, R3, R4, R5: 4k7; R_0805_2012Metric_Pad1.20x1.40mm_HandSolder
R6, R7: 10k; R_0805_2012Metric_Pad1.20x1.40mm_HandSolder
R8, R9: 470; R_0805_2012Metric_Pad1.20x1.40mm_HandSolder
TP1: TestPoint; TestPoint_Pad_D2.5mm
U1: AP1117-33; SOT-223-3_TabPin2
U2: CS4344-CZZ

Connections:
3v3: C2.1, J1.3, J1.4, J2.4 (VDD), R1.1, R2.1, R3.1, R4.1, R5.1, TP1.1, U1.2 (VO), U2.9 (VA)
AOUTL: C4.1, U2.7 (AOUTL)
AOUTR: C3.1, U2.10 (AOUTR)
GND: C1.2, C2.2, C5.1, C6.1, C7.2, C8.2, C9.2, J1.1, J1.2, J1.5, J1.6, J1.61, J1.62, J2.6 (VSS), J2.9 (SHIELD), J3.1, J4.2, R6.2, R7.2, U1.1 (GND), U2.8 (GND)
I2S_LRCK: J1.50, U2.3 (LRCK)
I2S_MCLK: J1.52, U2.4 (MCLK)
I2S_SCLK: J1.48, U2.2 (*DEM/SCLK)
I2S_SDIN: J1.46, U2.1 (SDIN)
unnamed: C3.2, R6.1, R8.1
unnamed: C4.2, R7.1, R9.1
unnamed: C5.2, J4.1, R8.2
unnamed: C6.2, J4.3, R9.2
unnamed: C7.1, U2.6 (FILT+)
unnamed: C8.1, C9.1, U2.5 (VQ)
RX: J1.47, J3.2
SD_CLK: J1.53, J2.5 (CLK)
SD_CMD: J1.55, J2.3 (CMD), R3.2
SD_DAT0: J1.51, J2.7 (DAT0), R4.2
SD_DAT1: J1.49, J2.8 (DAT1), R5.2
SD_DAT2: J1.59, J2.1 (DAT2), R1.2
SD_DAT3: J1.57, J2.2 (DAT3/CD), R2.2
TX: J1.45, J3.3
VIN: C1.1, J1.64, U1.3 (VI)

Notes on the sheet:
5V at 63 & 64 from board


Board: 2 copper layers, 47.0 x 83.8 mm, 27 parts (1 on the bottom side), 23 nets.

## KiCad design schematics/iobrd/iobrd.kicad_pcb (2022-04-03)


Board: 2 copper layers, 38.1 x 83.8 mm, 22 parts (1 on the bottom side), 24 nets, no tracks yet.

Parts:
C1, C2, C3, C4: 10nF; C_0805_2012Metric_Pad1.18x1.45mm_HandSolder
C7: 0.1uF; C_0805_2012Metric_Pad1.18x1.45mm_HandSolder
C8: 2.2uF; C_0805_2012Metric_Pad1.18x1.45mm_HandSolder
J1: Conn_02x32_Odd_Even; PinSocket_2x32_P2.54mm_Vertical
J3: Conn_01x08_Male; Molex_KK-254_AE-6410-08A_1x08_P2.54mm_Vertical
J4: Conn_01x03_Male; Molex_KK-254_AE-6410-03A_1x03_P2.54mm_Vertical
J5: Conn_01x04_Male; Molex_KK-254_AE-6410-04A_1x04_P2.54mm_Vertical
J6: Conn_01x02_Male; Molex_KK-254_AE-6410-02A_1x02_P2.54mm_Vertical
R1, R2, R3: 0; R_0805_2012Metric_Pad1.20x1.40mm_HandSolder
R4, R5, R6, R7: 560; R_0805_2012Metric_Pad1.20x1.40mm_HandSolder
TP1: 5v0; TestPoint_Pad_D1.5mm
TP2: 3v3; TestPoint_Pad_D1.5mm
U1: FT232RL; SSOP-28_5.3x10.2mm_P0.65mm
U2: LP2951-3.3_SOIC; SOIC-8_3.9x4.9mm_P1.27mm

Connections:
5v0: J1.63, J1.64, TP1.1
/3v3: C7.1, C8.1, J3.8, J5.4, R1.2, TP2.1, U2.1 (OUT), U2.2 (SENSE)
/AUDIO_PWM_L: J1.49, R4.1
/AUDIO_PWM_R: J1.51, R5.1
/PICO_RX: J1.46, J5.3
/PICO_TX: J1.48, J5.2
/RX: J1.45, U1.5 (RXD)
/SD_CLK: J1.53, J3.7
/SD_CMD: J1.55, J3.6
/SD_DAT0: J1.57, J3.5
/SD_DAT1: J1.59, J3.4
/SD_DAT2: J1.58, J3.3
/SD_DAT3: J1.60, J3.2
/TX: J1.47, U1.1 (TXD)
GND: C1.2, C2.1, C3.2, C4.1, C7.2, C8.2, J1.1, J1.2, J1.5, J1.6, J1.61, J1.62, J3.1, J4.2, J5.1, J6.2, U1.7 (GND), U1.18 (GND), U1.21 (GND), U1.25 (AGND), U1.26 (TEST), U2.3 (SHUTDOWN), U2.4 (GND)
unnamed: C1.1, R4.2, R6.1
unnamed: C2.2, R5.2, R7.1
unnamed: C3.1, R6.2
unnamed: C4.2, R7.2
unnamed: J1.3, J1.4, R1.1
unnamed: R2.1, U1.23 (CBUS0)
unnamed: R3.1, U1.22 (CBUS1)
unnamed: U2.6 (VTAP), U2.7 (FEEDBACK)
VIN: J6.1, U2.8 (IN)

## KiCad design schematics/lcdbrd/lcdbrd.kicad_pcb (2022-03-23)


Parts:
C1, C3: 100nF; C_0805_2012Metric_Pad1.18x1.45mm_HandSolder
C2, C4: 1uF; C_0805_2012Metric_Pad1.18x1.45mm_HandSolder
J1: Conn_02x32_Odd_Even; PinSocket_2x32_P2.54mm_Vertical
J2: Conn_02x20_Odd_Even; IDC-Header_2x20_P2.54mm_Vertical
TP1: 5v0; TestPoint_Pad_D1.5mm
TP2: 3v3; TestPoint_Pad_D1.5mm
TP3: DE; TestPoint_Pad_D1.5mm
TP4: CLK; TestPoint_Pad_D1.5mm
TP5: (no value)

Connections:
3v3: C3.1, C4.1, J1.3, J1.4, J2.3, J2.35, TP2.1
5v0: C1.1, C2.1, J1.63, J1.64, J2.1, TP1.1
/B0: J1.27, J2.21
/B1: J1.28, J2.22
/B2: J1.29, J2.23
/B3: J1.30, J2.24
/B4: J1.31, J2.25
/B5: J1.32, J2.26
/B6: J1.33, J2.27
/B7: J1.34, J2.28
/BKL: J1.46, J2.36, TP5.1
/CLK: J1.42, J2.31, TP4.1
/DE: J1.38, J2.32, TP3.1
/G0: J1.17, J2.13
/G1: J1.18, J2.14
/G2: J1.19, J2.15
/G3: J1.20, J2.16
/G4: J1.21, J2.17
/G5: J1.22, J2.18
/G6: J1.23, J2.19
/G7: J1.24, J2.20
/R0: J1.7, J2.5
/R1: J1.8, J2.6
/R2: J1.9, J2.7
/R3: J1.10, J2.8
/R4: J1.11, J2.9
/R5: J1.12, J2.10
/R6: J1.13, J2.11
/R7: J1.14, J2.12
GND: C1.2, C2.2, C3.2, C4.2, J1.1, J1.2, J1.5, J1.6, J1.61, J1.62, J2.2, J2.4


Board: 2 copper layers, 30.5 x 83.8 mm, 11 parts (1 on the bottom side), 30 nets.

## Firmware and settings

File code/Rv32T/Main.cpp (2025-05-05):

/*
 TRAKTOR
 Copyright (c) 2023 Anders Pistol.

 This Source Code Form is subject to the terms of the Mozilla Public
 License, v. 2.0. If a copy of the MPL was not distributed with this
 file, You can obtain one at https://mozilla.org/MPL/2.0/.
*/
#if defined(__LINUX__) || defined(__RPI__) || defined(__APPLE__)
#	include <sys/types.h>
#	include <sys/stat.h>
#	include <signal.h>
#	include <stdio.h>
#	include <stdlib.h>
#	include <fcntl.h>
#	include <errno.h>
#	include <unistd.h>
#	include <syslog.h>
#	include <string.h>
#endif
#include <Core/Io/DynamicMemoryStream.h>
#include <Core/Io/FileSystem.h>
#include <Core/Io/FileOutputStream.h>
#include <Core/Io/StreamCopy.h>
#include <Core/Io/Utf8Encoding.h>
#include <Core/Log/Log.h>
#include <Core/Misc/CommandLine.h>
#include <Core/Misc/SafeDestroy.h>
#include <Core/Misc/String.h>
#include <Core/Misc/TString.h>
#include <Core/Timer/Timer.h>
#include <Net/Network.h>
#include <Net/SocketAddressIPv4.h>
#include <Net/SocketStream.h>
#include <Net/UdpSocket.h>
#include <Ui/Application.h>
#include <Ui/Bitmap.h>
#include <Ui/Button.h>
#include <Ui/Image.h>
#include <Ui/Form.h>
#include <Ui/FloodLayout.h>
#include <Ui/TableLayout.h>
#include <Ui/StatusBar/StatusBar.h>
#if defined(_WIN32)
#	include <Ui/Win32/WidgetFactoryWin32.h>
#elif defined(__APPLE__)
#	include <Ui/Cocoa/WidgetFactoryCocoa.h>
#elif defined(__LINUX__) || defined(__RPI__)
#	include <Ui/X11/WidgetFactoryX11.h>
#endif
#include "Rv32T/AUDIO.h"
#include "Rv32T/ELF.h"
#include "Rv32T/HDMI.h"
#include "Rv32T/LEDR.h"
#include "Rv32T/Measure.h"
#include "Rv32T/ProfilerBUS.h"
#include "Rv32T/SD.h"
#include "Rv32T/TraceEXE.h"
#include "Rv32T/TracePC.h"
#include "Rv32T/TraceWB.h"
#include "Rv32T/UART_RX.h"
#include "Rv32T/UART_TX.h"

// Verilated SoC
#include "verilated.h"
#include "verilated_fst_c.h"
#include "SoC/VSoC.h"
#include "SoC/VSoC___024root.h"

using namespace traktor;

const uint32_t c_memoryAvail = 0x2000000;
bool g_going = true;

double sc_time_stamp() { return 0.0; }

class CustomLogTarget : public ILogTarget
{
public:
	virtual void log(uint32_t threadId, int32_t level, const wchar_t* str) override final
	{
		VL_PRINTF_MT("%s\n", wstombs(str).c_str());
	}	
};

#if defined(__LINUX__) || defined(__RPI__) || defined(__APPLE__)
void abortHandler(int s)
{
	g_going = false;
}
#endif

bool loadELF(VSoC* soc, const std::wstring& fileName, bool jumpTo)
{
	AlignedVector< uint8_t > elf;
	uint32_t start = -1;
	auto root = soc->rootp;

	// Read entire ELF into memory.
	{
		Ref< IStream > f = FileSystem::getInstance().open(fileName, File::FmRead);
		if (!f)
		{
			log::error << L"Unable to open ELF \"" << fileName << L"\"." << Endl;
			return false;
		}

		DynamicMemoryStream dms(elf, false, true);
		if (!StreamCopy(&dms, f).execute())
		{
			log::error << L"Unable to open ELF \"" << fileName << L"\"; failed to read file." << Endl;
			return false;
		}
	}

	auto hdr = (const ELF32_Header*)elf.c_ptr();

	if (hdr->e_machine != 0xF3)
	{
		log::error << L"Unable to parse ELF \"" << fileName << L"\"; incorrect machine type." << Endl;
		return false;		
	}

	auto shdr = (const ELF32_SectionHeader*)(elf.c_ptr() + hdr->e_shoff);
	for (uint32_t i = 0; i < hdr->e_shnum; ++i)
	{
		if (
			shdr[i].sh_type == 0x01 ||	// SHT_PROGBITS
			shdr[i].sh_type == 0x0e ||	// SHT_INIT_ARRAY
			shdr[i].sh_type == 0x0f		// SHT_FINI_ARRAY
		)
		{
			if ((shdr[i].sh_flags & 0x02) == 0x02)	// SHF_ALLOC
			{
				const auto pbits = (const uint8_t*)(elf.c_ptr() + shdr[i].sh_offset);
				const uint32_t addr = shdr[i].sh_addr;

				const uint32_t base = 0x20000000;

				uint8_t* dst = 0; // (uint8_t*)root->SoC__DOT__sdram__DOT__data;
				for (uint32_t j = 0; j < shdr[i].sh_size; ++j)
					dst[addr - base + j] = pbits[j];
			}
		}
		else if (shdr[i].sh_type == 0x02 && jumpTo)	// SHT_SYMTAB
		{
			const char* strings = (const char*)(elf.c_ptr() + shdr[shdr[i].sh_link].sh_offset);
			auto sym = (const ELF32_Sym*)(elf.c_ptr() + shdr[i].sh_offset);
			for (int32_t j = 0; j < shdr[i].sh_size / sizeof(ELF32_Sym); ++j)
			{
				const char* name = strings + sym[j].st_name;
				if (strcmp(name, "_start") == 0)
				{
					log::info << L"Entry found, " << str(L"0x%08x", sym[j].st_value) << Endl;
					start = sym[j].st_value;
					break;
				}
			}
		}
	}

	if (start != -1)
		root->SoC__DOT__cpu__DOT__fetch__DOT__pc = start;

	return true;
}

int main(int argc, const char **argv)
{
	CommandLine cmdLine(argc, argv);
	Timer timer;

	net::Network::initialize();

	if (!cmdLine.hasOption(L'h', L"headless"))
	{
#if defined(_WIN32)
		ui::Application::getInstance()->initialize(
			new ui::WidgetFactoryWin32(),
			nullptr
		);
#elif defined(__APPLE__)
		ui::Application::getInstance()->initialize(
			new ui::WidgetFactoryCocoa(),
			nullptr
		);
#elif defined(__LINUX__) || defined(__RPI__)
		ui::Application::getInstance()->initialize(
			new ui::WidgetFactoryX11(),
			nullptr
		);
#endif
	}

#if defined(__LINUX__) || defined(__RPI__) || defined(__APPLE__)
	{
		struct sigaction sa = { SIG_IGN };
		sigaction(SIGPIPE, &sa, nullptr);
	}
	{
		struct sigaction sa;
		sa.sa_handler = abortHandler;
		sigemptyset(&sa.sa_mask);
		sa.sa_flags = 0;
		sigaction(SIGINT, &sa, nullptr);
	}
#endif

	Ref< CustomLogTarget > logTarget = new CustomLogTarget();
	log::info.setGlobalTarget(logTarget);
	log::warning.setGlobalTarget(logTarget);
	log::error.setGlobalTarget(logTarget);

	bool trace = false;
	bool reset = false;
	bool key1 = false;
	bool slow = false;
	bool mute = false;

	if (cmdLine.hasOption(L"slow"))
		slow = true;

	if (cmdLine.hasOption(L"mute"))
		mute = true;

	// Create user interface.
	Ref< ui::Form > form;
	Ref< ui::StatusBar > statusBar;
	Ref< ui::Bitmap > framebuffer;
	Ref< ui::Image > image;

	if (!cmdLine.hasOption(L'h', L"headless"))
	{
		form = new ui::Form();
		form->create(L"RV32", 640_ut, 400_ut, ui::Form::WsDefault, new ui::TableLayout(L"100%", L"*,100%,*", 4_ut, 4_ut));

		Ref< ui::Container > container = new ui::Container();
		container->create(form, ui::WsNone, new ui::TableLayout(L"*,*,*,*", L"*", 0_ut, 4_ut));

		Ref< ui::Button > buttonTrace = new ui::Button();
		buttonTrace->create(container, L"Trace");
		buttonTrace->addEventHandler< ui::ButtonClickEvent >([&](ui::ButtonClickEvent* event) {
			buttonTrace->setEnable(false);
			trace = true;
		});

		Ref< ui::Button > buttonReset = new ui::Button();
		buttonReset->create(container, L"Reset");
		buttonReset->addEventHandler< ui::ButtonClickEvent >([&](ui::ButtonClickEvent* event) {
			reset = true;
		});	

		Ref< ui::Button > buttonKey1 = new ui::Button();
		buttonKey1->create(container, L"KEY1");
		buttonKey1->addEventHandler< ui::ButtonClickEvent >([&](ui::ButtonClickEvent* event) {
			key1 = true;
		});

		Ref< ui::Button > buttonSpeed = new ui::Button();
		buttonSpeed->create(container, L"Fast/Slow");
		buttonSpeed->addEventHandler< ui::ButtonClickEvent >([&](ui::ButtonClickEvent* event) {
			slow = !slow;
		});

		framebuffer = new ui::Bitmap(640, 400);
		
		Ref< ui::Container > containerImage = new ui::Container();
		containerImage->create(form, ui::WsNone, new ui::FloodLayout());

		image = new ui::Image();
		image->create(containerImage, framebuffer, ui::Image::WsScale | ui::Image::WsNearestFilter);

		statusBar = new ui::StatusBar();
		statusBar->create(form);
		statusBar->addColumn(100);	// IPC
		statusBar->addColumn(200);	// BUS
		statusBar->addColumn(240);	// STALL
		statusBar->addColumn(200);	// PC
		statusBar->addColumn(200);	// FRAME COUNT

		form->update();
		form->show();
	}

	// Create SoC simulation.
	VSoC* soc = new VSoC();
	soc->rootp->CPU_RESET_n = 1;
	soc->rootp->CLOCK_125_p = 0;

	soc->eval();

	// VL_PRINTF_MT("*");

	// Randomize cache data.
	// for (int i = 0; i < sizeof_array(soc->SoC__DOT__cpu__DOT__fetch__DOT__genblk2__DOT__icache__DOT__cache__DOT__data); ++i)
	// 	soc->SoC__DOT__cpu__DOT__fetch__DOT__genblk2__DOT__icache__DOT__cache__DOT__data[i] = -1;
	// for (int i = 0; i < sizeof_array(soc->SoC__DOT__cpu__DOT__memory__DOT__genblk2__DOT__dcache__DOT__cache__DOT__data); ++i)
	// 	soc->SoC__DOT__cpu__DOT__memory__DOT__genblk2__DOT__dcache__DOT__cache__DOT__data[i] = -1;

	if (cmdLine.hasOption(L"elf-kernal"))
	{
		std::wstring fileName = cmdLine.getOption(L"elf-kernal").getString();
		if (!loadELF(soc, fileName, false))
			return 1;
	}	

	if (cmdLine.hasOption(L'e', L"elf"))
	{
		std::wstring fileName = cmdLine.getOption(L'e', L"elf").getString();
		if (!loadELF(soc, fileName, true))
			return 1;
	}

	if (cmdLine.hasOption('s', L"stack"))
	{
		const uint32_t sp = (uint32_t)cmdLine.getOption('s', L"stack").getInteger();
		soc->rootp->SoC__DOT__cpu__DOT__registers__DOT__r[2] = sp;
		log::info << L"Inital SP " << str(L"0x%08x", sp) << Endl;
	}
	else
	{
		// Initialize stack at end of SDRAM, this is same as firmware does when launching applications.
		const uint32_t sp = 0x20000000 + c_memoryAvail - 0x8;		
		soc->rootp->SoC__DOT__cpu__DOT__registers__DOT__r[2] = sp;
		log::info << L"Inital SP " << str(L"0x%08x", sp) << Endl;
	}

	// Create signal trace.
	VerilatedFstC* tfp = nullptr;
	if (cmdLine.hasOption(L't', L"trace"))
		trace = true;

	// Create devices.
	HDMI hdmi;
	AUDIO audio;

	RefArray< Device > devices;
	devices.push_back(&hdmi);
	devices.push_back(new LEDR());
	devices.push_back(new UART_TX(soc->rootp->UART_TX));
	devices.push_back(new UART_TX(soc->rootp->UART_1_TX));
	devices.push_back(new SD());

	// Create receiving UART.
	if (cmdLine.hasOption(L"udp"))
	{
		Ref< net::UdpSocket > socket = new net::UdpSocket();
		if (!socket->bind(net::SocketAddressIPv4(45123)))
		{
			log::error << L"Unable to bind socket to port." << Endl;
			return 1;
		}

		Ref< IStream > target = new net::SocketStream(socket, true, true, 1000);
		devices.push_back(new UART_RX(target, soc->rootp->UART_RX));
	}

	// Add audio device to record PWM audio.
	if (cmdLine.hasOption(L"record-audio"))
		devices.push_back(&audio);

	// Create trace devices.
	if (cmdLine.hasOption(L"trace-pc"))
	{
		Ref< IStream > f = FileSystem::getInstance().open(cmdLine.getOption(L"trace-pc").getString(), File::FmWrite);
		if (!f)
		{
			log::error << L"Unable to create PC trace." << Endl;
			return 1;
		}
		devices.push_back(new TracePC(
			new FileOutputStream(f, new Utf8Encoding())
		));
	}

	if (cmdLine.hasOption(L"trace-execute"))
	{
		Ref< IStream > f = FileSystem::getInstance().open(cmdLine.getOption(L"trace-execute").getString(), File::FmWrite);
		if (!f)
		{
			log::error << L"Unable to create EXECUTE trace." << Endl;
			return 1;
		}
		devices.push_back(new TraceEXE(
			new FileOutputStream(f, new Utf8Encoding())
		));
	}

	if (cmdLine.hasOption(L"trace-writeback"))
	{
		Ref< IStream > f = FileSystem::getInstance().open(cmdLine.getOption(L"trace-writeback").getString(), File::FmWrite);
		if (!f)
		{
			log::error << L"Unable to create WRITEBACK trace." << Endl;
			return 1;
		}
		devices.push_back(new TraceWB(
			new FileOutputStream(f, new Utf8Encoding())
		));
	}

	devices.push_back(new ProfilerBUS());

	uint64_t time = 0;
	uint64_t lastCycles = 0;
	uint64_t lastRetired = 0;
	uint64_t lastStarve = 0;
	Measure busActive;
	Measure busSDRAM;
	Measure stallExecute;
	Measure stallMemory;
	int32_t Tp = 0;

	timer.reset();
	while (g_going)
	{
		if (form)
		{
			if (!ui::Application::getInstance()->process())
				break;
		}

		const uint64_t Tc = (uint64_t)(timer.getElapsedTime() * 1000);
		const uint64_t count = slow ? std::min< uint64_t >(Tc - Tp, 1000) : 50000;
		Tp = Tc;

		bool shouldDraw = false;
		
		for (uint64_t i = 0; i < count; ++i)
		{
			if (trace)
			{
				Verilated::traceEverOn(true);
				tfp = new VerilatedFstC;
				soc->trace(tfp, 99);  // Trace 99 levels of hierarchy
				tfp->open("Rv32T.fst");
				trace = false;
				log::info << L"TRACE CREATED" << Endl;
			}

			const bool hdmiTxInt = hdmi.shouldDraw();
			shouldDraw |= hdmiTxInt;

			++time;
			soc->rootp->CLOCK_125_p = 0;
			soc->rootp->CPU_RESET_n = reset ? 0 : 1;
			soc->rootp->KEY |= key1 ? 2 : 0;
			soc->rootp->HDMI_TX_INT = hdmiTxInt;

			soc->eval();

			if (tfp)
				tfp->dump(time);

			++time;
			soc->rootp->CLOCK_125_p = 1;
			soc->rootp->CPU_RESET_n = reset ? 0 : 1;
			soc->rootp->KEY |= key1 ? 2 : 0;
			soc->rootp->HDMI_TX_INT = hdmiTxInt;

			soc->eval();

			if (tfp)
				tfp->dump(time);

			for (auto device : devices)
				device->eval(soc, time);

			// Count number of cycles bus is active.
			// if (soc->SoC__DOT__cpu_ibus_request || soc->SoC__DOT__cpu_dbus_request)
			// 	busActive++;
			// if (soc->SoC__DOT__sdram_request)
			//  	busSDRAM++;

			if (soc->rootp->o_execute_busy)
				stallExecute++;
			if (soc->rootp->o_memory_busy)
				stallMemory++;

			key1 = false;
			reset = false;

			if (soc->rootp->SoC__DOT__cpu__DOT__decode_fault)
			{
				log::warning << L"DECODE fault, terminating." << Endl;
				g_going = false;
				break;
			}
			if (soc->rootp->SoC__DOT__cpu__DOT__execute_fault)
			{
				log::warning << L"EXECUTE fault, terminating." << Endl;
				g_going = false;
				break;
			}
			if (soc->rootp->o_debug_bus_fault)
			{
				const wchar_t* faults[] = { L"NA", L"IBUS", L"DBUS", L"DMA" };
				log::warning << L"BUS fault, invalid address " << str(L"0x%08x", soc->rootp->o_debug_bus_fault_address) << L" (" << faults[soc->rootp->o_debug_bus_fault_type] << L"), terminating." << Endl;
				g_going = false;
				break;				
			}
		}

		if (form)
		{
			if (shouldDraw)
			{
				framebuffer->copyImage(hdmi.getImage());
				image->setImage(framebuffer);
			}

			if ((Tc % 30) == 0)
			{
				const uint32_t dc = soc->rootp->SoC__DOT__timer__DOT__cycles - lastCycles;
				const uint32_t dr = soc->rootp->SoC__DOT__cpu__DOT__writeback__DOT__retired - lastRetired;

				statusBar->setText(0, str(L"%.2f IPC", ((double)dr) / dc));
				
				statusBar->setText(1,
					str(
						L"%.2f%% (%.2f%%) BUS",
						((double)busActive.delta() * 100.0) / dc,
						((double)busSDRAM.delta() * 100.0) / dc
					)
				);

				statusBar->setText(2, 
					str(
						L"%.2f%% / %.2f%% STALL X/M",
						((double)stallExecute.delta() * 100.0) / dc,
						((double)stallMemory.delta() * 100.0) / dc
					)
				);

				statusBar->setText(
					3,
					str(
						L"%08x PC",
						soc->rootp->SoC__DOT__cpu__DOT__fetch__DOT__pc
					)
				);

				statusBar->setText(
					4,
					str(
						L"%d FRAMES",
						hdmi.frameCount()
					)
				);

				lastCycles = soc->rootp->SoC__DOT__timer__DOT__cycles;
				lastRetired = soc->rootp->SoC__DOT__cpu__DOT__writeback__DOT__retired;

				busActive.snapshot();
				busSDRAM.snapshot();
				stallExecute.snapshot();
				stallMemory.snapshot();					
			}
		}
		else if (!mute)
		{
			if ((Tc % 600) == 0)
			{
				const uint32_t dc = soc->rootp->SoC__DOT__timer__DOT__cycles - lastCycles;
				const uint32_t dr = soc->rootp->SoC__DOT__cpu__DOT__writeback__DOT__retired - lastRetired;
				const uint32_t ds = soc->rootp->SoC__DOT__cpu__DOT__fetch__DOT__starve - lastStarve;

				const uint32_t ich = soc->rootp->o_icache_hit;
				const uint32_t icm = soc->rootp->o_icache_miss;
				const double icr = (ich * 100.0) / (ich + icm);

				const uint32_t dch = soc->rootp->o_dcache_hit;
				const uint32_t dcm = soc->rootp->o_dcache_miss;
				const double dcr = (dch * 100.0) / (dch + dcm);

				log::info << L"### " <<
					str(L"%08x PC", soc->rootp->SoC__DOT__cpu__DOT__fetch__DOT__pc) << L", " <<
					str(L"%.2f IPC", ((double)dr) / dc) << L", " <<
					str(L"%.2f%% BUS", ((double)busActive.delta() * 100.0) / dc) << L", " <<
					str(L"%.2f%% STALL X", ((double)stallExecute.delta() * 100.0) / dc) << L", " <<
					str(L"%.2f%% STALL M", ((double)stallMemory.delta() * 100.0) / dc) << L", " <<
					str(L"%.2f%% STARVE", ((double)ds * 100.0) / dc) << L", " <<
					str(L"%d MPIE", soc->rootp->SoC__DOT__cpu__DOT__csr__DOT__mstatus_mpie ? 1 : 0) << L", " <<
					str(L"%d MIE", soc->rootp->SoC__DOT__cpu__DOT__csr__DOT__mstatus_mie ? 1 : 0) << L", " <<
					str(L"%d MEIE", soc->rootp->SoC__DOT__cpu__DOT__csr__DOT__mie_meie ? 1 : 0) << L", " <<
					str(L"%d MEIP", soc->rootp->SoC__DOT__cpu__DOT__csr__DOT__mip_meip ? 1 : 0) << L", " <<
					str(L"%d MTIE", soc->rootp->SoC__DOT__cpu__DOT__csr__DOT__mie_mtie ? 1 : 0) << L", " <<
					str(L"%d MTIP", soc->rootp->SoC__DOT__cpu__DOT__csr__DOT__mip_mtip ? 1 : 0) << L", " <<
					str(L"%08x MSCRATCH", soc->rootp->SoC__DOT__cpu__DOT__csr__DOT__mscratch) << L", " <<
					str(L"%d TIME", soc->rootp->SoC__DOT__cpu__DOT__csr__DOT__wtime) << L", " <<
					str(L"%.2f%% I$ HIT", icr) << L", " <<
					str(L"%.2f%% D$ HIT", dcr) << L", " <<
					Endl;

				lastCycles = soc->rootp->SoC__DOT__timer__DOT__cycles;
				lastRetired = soc->rootp->SoC__DOT__cpu__DOT__writeback__DOT__retired;
				lastStarve = soc->rootp->SoC__DOT__cpu__DOT__fetch__DOT__starve;
				
				busActive.snapshot();
				stallExecute.snapshot();
				stallMemory.snapshot();
			}	
		}
	}

	log::info << Endl;
	log::info << L"--- Terminated ---" << Endl;
	log::info << L"PC        : " << str(L"%08x", soc->rootp->SoC__DOT__cpu__DOT__fetch__DOT__pc) << Endl;
	log::info << L"CYCLES    : " << soc->rootp->SoC__DOT__timer__DOT__cycles << Endl;
	log::info << L"RETIRE    : " << soc->rootp->SoC__DOT__cpu__DOT__writeback__DOT__retired << Endl;
	log::info << L"BUS       : " << busActive.value() << L", " << (busActive.value() * 100) / soc->rootp->SoC__DOT__timer__DOT__cycles << L"%" << Endl;

	log::info << Endl;
	log::info << L"RA        : " << str(L"%08x", soc->rootp->SoC__DOT__cpu__DOT__registers__DOT__r[1]) << Endl;
	log::info << L"SP        : " << str(L"%08x", soc->rootp->SoC__DOT__cpu__DOT__registers__DOT__r[2]) << Endl;
	log::info << L"GP        : " << str(L"%08x", soc->rootp->SoC__DOT__cpu__DOT__registers__DOT__r[3]) << Endl;
	log::info << L"TP        : " << str(L"%08x", soc->rootp->SoC__DOT__cpu__DOT__registers__DOT__r[4]) << Endl;
	log::info << L"T0        : " << str(L"%08x", soc->rootp->SoC__DOT__cpu__DOT__registers__DOT__r[5]) << Endl;
	log::info << L"A0        : " << str(L"%08x", soc->rootp->SoC__DOT__cpu__DOT__registers__DOT__r[10]) << Endl;
	log::info << L"A1        : " << str(L"%08x", soc->rootp->SoC__DOT__cpu__DOT__registers__DOT__r[11]) << Endl;
	log::info << L"A2        : " << str(L"%08x", soc->rootp->SoC__DOT__cpu__DOT__registers__DOT__r[12]) << Endl;
	log::info << L"A3        : " << str(L"%08x", soc->rootp->SoC__DOT__cpu__DOT__registers__DOT__r[13]) << Endl;
	log::info << L"A4        : " << str(L"%08x", soc->rootp->SoC__DOT__cpu__DOT__registers__DOT__r[14]) << Endl;
	log::info << L"A5        : " << str(L"%08x", soc->rootp->SoC__DOT__cpu__DOT__registers__DOT__r[15]) << Endl;
	log::info << L"S2        : " << str(L"%08x", soc->rootp->SoC__DOT__cpu__DOT__registers__DOT__r[18]) << Endl;

	hdmi.getImage()->save(L"Rv32T.png");

	if (tfp)
	{
		tfp->close();
		delete tfp;
	}

	safeDestroy(form);
	return 0;
}

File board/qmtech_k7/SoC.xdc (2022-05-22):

# create async clock groups from system clock and video clock.
#set_clock_groups -asynchronous -group [get_clocks {pll_clk|ip_pll_clk_inst|altera_pll_i|general[0].gpll~PLL_OUTPUT_COUNTER|divclk}] -group [get_clocks {pll_clk|ip_pll_clk_inst|altera_pll_i|general[2].gpll~PLL_OUTPUT_COUNTER|divclk}]
set_false_path -from [get_clocks -of_objects [get_pins ipclk/inst/mmcm_adv_inst/CLKOUT2]] -to [get_clocks -of_objects [get_pins ipclk/inst/mmcm_adv_inst/CLKOUT0]]

# UART FTDI
set_property IOSTANDARD LVCMOS33 [get_ports {uart_0_rx}]
set_property PACKAGE_PIN Y23 [get_ports {uart_0_rx}]
set_property IOSTANDARD LVCMOS33 [get_ports {uart_0_tx}]
set_property PACKAGE_PIN Y22 [get_ports {uart_0_tx}]

# UART IO
set_property IOSTANDARD LVCMOS33 [get_ports {uart_1_rx}]
set_property PACKAGE_PIN B26 [get_ports {uart_1_rx}]
set_property IOSTANDARD LVCMOS33 [get_ports {uart_1_tx}]
set_property PACKAGE_PIN C26 [get_ports {uart_1_tx}]

# SD
set_property IOSTANDARD LVCMOS33 [get_ports {sd_clk}]
set_property PACKAGE_PIN AE22 [get_ports {sd_clk}]
set_property IOSTANDARD LVCMOS33 [get_ports {sd_cmd}]
set_property PACKAGE_PIN AE23 [get_ports {sd_cmd}]
set_property IOSTANDARD LVCMOS33 [get_ports {sd_dat[0]}]
set_property PACKAGE_PIN AA25 [get_ports {sd_dat[0]}]
set_property IOSTANDARD LVCMOS33 [get_ports {sd_dat[1]}]
set_property PACKAGE_PIN AC23 [get_ports {sd_dat[1]}]
set_property IOSTANDARD LVCMOS33 [get_ports {sd_dat[2]}]
set_property PACKAGE_PIN AD26 [get_ports {sd_dat[2]}]
set_property IOSTANDARD LVCMOS33 [get_ports {sd_dat[3]}]
set_property PACKAGE_PIN AF24 [get_ports {sd_dat[3]}]

# I2S
set_property IOSTANDARD LVCMOS33 [get_ports {i2s_sdout}]
set_property PACKAGE_PIN AA22 [get_ports {i2s_sdout}]
set_property IOSTANDARD LVCMOS33 [get_ports {i2s_sclk}]
set_property PACKAGE_PIN AA24 [get_ports {i2s_sclk}]
set_property IOSTANDARD LVCMOS33 [get_ports {i2s_lrck}]
set_property PACKAGE_PIN AC24 [get_ports {i2s_lrck}]
set_property IOSTANDARD LVCMOS33 [get_ports {i2s_mclk}]
set_property PACKAGE_PIN AB25 [get_ports {i2s_mclk}]


#set_property IOSTANDARD LVCMOS33 [get_ports {led_1}]
#set_property PACKAGE_PIN B14 [get_ports {led_1}]
#set_property IOSTANDARD LVCMOS33 [get_ports {led_2}]
#set_property PACKAGE_PIN C14 [get_ports {led_2}]
#set_property IOSTANDARD LVCMOS33 [get_ports {led_3}]
#set_property PACKAGE_PIN E25 [get_ports {led_3}]

set_property IOSTANDARD LVCMOS33 [get_ports sys_rst]
set_property PACKAGE_PIN AB26 [get_ports sys_rst]

set_property IOSTANDARD LVCMOS33 [get_ports sys_clk]
set_property PACKAGE_PIN F22 [get_ports sys_clk]

# LCD

set_property IOSTANDARD LVCMOS33 [get_ports {hdmi_nreset}]
set_property PACKAGE_PIN C9 [get_ports {hdmi_nreset}]

set_property IOSTANDARD LVCMOS33 [get_ports {hdmi_sda}]
set_property PACKAGE_PIN D10 [get_ports {hdmi_sda}]
set_property IOSTANDARD LVCMOS33 [get_ports {hdmi_scl}]
set_property PACKAGE_PIN E10 [get_ports {hdmi_scl}]


set_property IOSTANDARD LVCMOS33 [get_ports {hdmi_idck}]
set_property PACKAGE_PIN D16 [get_ports {hdmi_idck}]

set_property IOSTANDARD LVCMOS33 [get_ports {hdmi_vsync}]
set_property PACKAGE_PIN B19 [get_ports {hdmi_vsync}]

set_property IOSTANDARD LVCMOS33 [get_ports {hdmi_hsync}]
set_property PACKAGE_PIN C19 [get_ports {hdmi_hsync}]

set_property IOSTANDARD LVCMOS33 [get_ports {hdmi_int}]
set_property PACKAGE_PIN A23 [get_ports {hdmi_int}]

set_property IOSTANDARD LVCMOS33 [get_ports {hdmi_de}]
set_property PACKAGE_PIN A19 [get_ports {hdmi_de}]

set_property IOSTANDARD LVCMOS33 [get_ports {hdmi_sdo}]
set_property PACKAGE_PIN A20 [get_ports {hdmi_sdo}]
set_property IOSTANDARD LVCMOS33 [get_ports {hdmi_sck}]
set_property PACKAGE_PIN D20 [get_ports {hdmi_sck}]
set_property IOSTANDARD LVCMOS33 [get_ports {hdmi_mclk}]
set_property PACKAGE_PIN B20 [get_ports {hdmi_mclk}]
set_property IOSTANDARD LVCMOS33 [get_ports {hdmi_ws}]
set_property PACKAGE_PIN D19 [get_ports {hdmi_ws}]


set_property PACKAGE_PIN A18 [get_ports {hdmi_r[0]}]
set_property PACKAGE_PIN C18 [get_ports {hdmi_r[1]}]
set_property PACKAGE_PIN C17 [get_ports {hdmi_r[2]}]
set_property PACKAGE_PIN D18 [get_ports {hdmi_r[3]}]
set_property PACKAGE_PIN E18 [get_ports {hdmi_r[4]}]
set_property PACKAGE_PIN A17 [get_ports {hdmi_r[5]}]
set_property PACKAGE_PIN B17 [get_ports {hdmi_r[6]}]
set_property PACKAGE_PIN B16 [get_ports {hdmi_r[7]}]

set_property PACKAGE_PIN C16 [get_ports {hdmi_g[0]}]
set_property PACKAGE_PIN D15 [get_ports {hdmi_g[1]}]
set_property PACKAGE_PIN A15 [get_ports {hdmi_g[2]}]
set_property PACKAGE_PIN B15 [get_ports {hdmi_g[3]}]
set_property PACKAGE_PIN C13 [get_ports {hdmi_g[4]}]
set_property PACKAGE_PIN C14 [get_ports {hdmi_g[5]}]
set_property PACKAGE_PIN A14 [get_ports {hdmi_g[6]}]
set_property PACKAGE_PIN B14 [get_ports {hdmi_g[7]}]
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

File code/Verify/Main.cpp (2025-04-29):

/*
 TRAKTOR
 Copyright (c) 2023 Anders Pistol.

 This Source Code Form is subject to the terms of the Mozilla Public
 License, v. 2.0. If a copy of the MPL was not distributed with this
 file, You can obtain one at https://mozilla.org/MPL/2.0/.
*/
#include <stdio.h>
#include <Core/Log/Log.h>
#include <Core/Math/Random.h>
#include "verilated.h"
#include "verilated_fst_c.h"
#include "SoC/VSoC.h"

//#define CHECK_FPU

using namespace traktor;

bool g_primeICache = true;

VSoC* create_soc()
{
	VSoC* tb = new VSoC();
	tb->CPU_RESET_n = 1;
	tb->CLOCK_125_p = 0;
	tb->eval();

	// Fill rom with NOP since prefetch might read more instructions
	// than we evaluate.
	for (int i = 0; i < 256; ++i)
		tb->SoC__DOT__rom__DOT__data[i] = 0x00000013;

	return tb;
}

void evaluate(VSoC* tb, const char* trace, int32_t steps)
{
	VerilatedFstC* tfp = nullptr;
	if (trace)
	{
		Verilated::traceEverOn(true);
		tfp = new VerilatedFstC;
		tb->trace(tfp, 99);  // Trace 99 levels of hierarchy
		tfp->open(trace); // "simx.vcd");
	}

	// Prime icache.
	// if (g_primeICache)
	// {
	// 	for (int i = 0; i < 10; ++i)
	// 	{
	// 		const uint32_t pc = i * 4;
	// 		const uint32_t inst = tb->SoC__DOT__rom__DOT__data[i];
	// 		tb->SoC__DOT__cpu__DOT__fetch__DOT__genblk1__DOT__icache__DOT__cache__DOT__data[i] =
	// 			(pc | 1) |
	// 			(uint64_t(inst) << 32);
	// 	};
	// }

	int32_t time = 0;
	for (int32_t i = 0; i < steps; ++i)
	{
		const uint32_t from = tb->SoC__DOT__cpu__DOT__writeback__DOT__retired;
		while (tb->SoC__DOT__cpu__DOT__writeback__DOT__retired == from)
		{
			++time;
			
			tb->CLOCK_125_p = 1;
			tb->eval();

			if (tfp)
				tfp->dump(time);

			++time;
			tb->CLOCK_125_p = 0;
			tb->eval();

			if (tfp)
				tfp->dump(time);

			if (time > 10000)
			{
				log::info << L"Unable to execute, seems stuck!" << Endl;
				break;
			}
		}
	}

	if (tfp)
	{
		tfp->close();
		delete tfp;
	}
}

#define ITERATIONS 10000

#define S0 8
#define S1 9
#define S2 18
#define S3 19
#define A2 12
#define A5 15
#define RA 1

traktor::Random g_rnd;

int32_t rnd12()
{
	int32_t r = (int32_t)g_rnd.next();
	int32_t v = (r & 0x7ff);

	if (g_rnd.nextFloat() > 0.5f)
		v = -v;
		
	return v;
}

int32_t rnd32()
{
	return (int32_t)g_rnd.next();
}

uint32_t urnd32()
{
	return g_rnd.next();
}

float rndf()
{
	for (;;)
	{
		uint32_t v = urnd32();
		float f = *(float*)&v;
		if (!std::isnan(f))
			return f;
	}
}

uint32_t patchImmediateI(uint32_t instruction, int32_t value)
{
	return (value << 20) | (instruction & 0xfffff);
}

//================================================

bool verify_ADD(const char* trace)
{
	int32_t s1 = rnd32();
	int32_t s2 = rnd32();

	auto tb = create_soc();
	tb->SoC__DOT__cpu__DOT__registers__DOT__r[S0] = 0;
	tb->SoC__DOT__cpu__DOT__registers__DOT__r[S1] = s1;
	tb->SoC__DOT__cpu__DOT__registers__DOT__r[S2] = s2;
	tb->SoC__DOT__rom__DOT__data[0] = 0x01248433; // add	s0,s1,s2

	evaluate(tb, trace, 1);

	if (tb->SoC__DOT__cpu__DOT__registers__DOT__r[S0] != (s1 + s2))
		return false;

	delete tb;
	return true;
}

bool verify_ADDI(const char* trace)
{
	int32_t s1 = rnd32();
	int32_t i1 = rnd12();

	auto tb = create_soc();
	tb->SoC__DOT__cpu__DOT__registers__DOT__r[S0] = 0;
	tb->SoC__DOT__cpu__DOT__registers__DOT__r[S1] = s1;
	tb->SoC__DOT__rom__DOT__data[0] = patchImmediateI(0x00348413, i1); // addi	s0,s1,<imm>

	evaluate(tb, trace, 1);

	// printf("%d + %d = %d\n", s1, i1, s1 + i1);
	// printf("-- %d\n", tb->SoC__DOT__cpu__DOT__registers__DOT__r[S0]);

	if (tb->SoC__DOT__cpu__DOT__registers__DOT__r[S0] != (s1 + i1))
		return false;

	delete tb;
	return true;
}

bool verify_AND(const char* trace)
{
	int32_t s1 = rnd32();
	int32_t s2 = rnd32();

	auto tb = create_soc();
	tb->SoC__DOT__cpu__DOT__registers__DOT__r[S0] = 0;
	tb->SoC__DOT__cpu__DOT__registers__DOT__r[S1] = s1;
	tb->SoC__DOT__cpu__DOT__registers__DOT__r[S2] = s2;
	tb->SoC__DOT__rom__DOT__data[0] = 0x0124f433; // and	s0,s1,s2

	evaluate(tb, trace, 1);

	if (tb->SoC__DOT__cpu__DOT__registers__DOT__r[S0] != (s1 & s2))
		return false;

	delete tb;
	return true;
}

bool verify_ANDI(const char* trace)
{
	int32_t s1 = rnd32();

	auto tb = create_soc();
	tb->SoC__DOT__cpu__DOT__registers__DOT__r[S0] = 0;
	tb->SoC__DOT__cpu__DOT__registers__DOT__r[S1] = s1;
	tb->SoC__DOT__rom__DOT__data[0] = 0x03f4f413; // andi	s0,s1,63

	evaluate(tb, trace, 1);

	if (tb->SoC__DOT__cpu__DOT__registers__DOT__r[S0] != (s1 & 63))
		return false;

	delete tb;
	return true;
}

bool verify_AUIPC(const char* trace)
{
	auto tb = create_soc();
	tb->SoC__DOT__cpu__DOT__registers__DOT__r[S0] = 0;
	tb->SoC__DOT__rom__DOT__data[0] = 0x0003f417; // auipc	s0,0x3f

	evaluate(tb, trace, 1);

	if (tb->SoC__DOT__cpu__DOT__registers__DOT__r[S0] != (0x3f << 12))
		return false;

	delete tb;
	return true;
}

bool verify_BEQ(const char* trace)
{
	uint32_t a = rand() & 15;
	uint32_t b = rand() & 15;

	auto tb = create_soc();
	tb->SoC__DOT__cpu__DOT__registers__DOT__r[S0] = a;
	tb->SoC__DOT__cpu__DOT__registers__DOT__r[S1] = b;
	tb->SoC__DOT__rom__DOT__data[0] = 0x00940663; // beq	s0,s1,c <jt>	0
	tb->SoC__DOT__rom__DOT__data[1] = 0x00100413; // li	s0,1			4
	tb->SoC__DOT__rom__DOT__data[2] = 0x00000013; // nop					8
	tb->SoC__DOT__rom__DOT__data[3] = 0x00200413; // li	s0,2			c
	tb->SoC__DOT__rom__DOT__data[4] = 0x00000013; // nop					10

	evaluate(tb, trace, 3);

	// printf("PC: %08x\n", tb->SoC__DOT__cpu__DOT__fetch_pc);
	// printf("%08x != %08x -> %d\n", a, b, tb->SoC__DOT__cpu__DOT__registers__DOT__r[S0]);

	if (a == b)
	{
		// if (tb->SoC__DOT__cpu__DOT__fetch_pc != 0x10)
		// 	return false;
		if (tb->SoC__DOT__cpu__DOT__registers__DOT__r[S0] != 2)
			return false;
	}
	else
	{
		// if (tb->SoC__DOT__cpu__DOT__fetch_pc != 0x08)
		// 	return false;
		if (tb->SoC__DOT__cpu__DOT__registers__DOT__r[S0] != 1)
			return false;
	}

	delete tb;
	return true;
}

bool verify_BGE(const char* trace)
{
	int32_t a = (int32_t)(rand() & 15) - 7;
	int32_t b = (int32_t)(rand() & 15) - 7;

	auto tb = create_soc();
	tb->SoC__DOT__cpu__DOT__registers__DOT__r[S0] = a;
	tb->SoC__DOT__cpu__DOT__registers__DOT__r[S1] = b;
	tb->SoC__DOT__rom__DOT__data[0] = 0x00945663; // bge	s0,s1,c <jt>	0
	tb->SoC__DOT__rom__DOT__data[1] = 0x00100413; // li	s0,1			4
	tb->SoC__DOT__rom__DOT__data[2] = 0x00000013; // nop					8
	tb->SoC__DOT__rom__DOT__data[3] = 0x00200413; // li	s0,2			c
	tb->SoC__DOT__rom__DOT__data[4] = 0x00000013; // nop					10

	evaluate(tb, trace, 3);

	// printf("%08x != %08x -> %d\n", a, b, tb->SoC__DOT__cpu__DOT__registers__DOT__r[S0]);

	if (a >= b)
	{
		// if (tb->SoC__DOT__cpu__DOT__fetch_pc != 0x10)
		// 	return false;
		if (tb->SoC__DOT__cpu__DOT__registers__DOT__r[S0] != 2)
			return false;
	}
	else
	{
		// if (tb->SoC__DOT__cpu__DOT__fetch_pc != 0x08)
		// 	return false;
		if (tb->SoC__DOT__cpu__DOT__registers__DOT__r[S0] != 1)
			return false;
	}

	delete tb;
	return true;
}
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

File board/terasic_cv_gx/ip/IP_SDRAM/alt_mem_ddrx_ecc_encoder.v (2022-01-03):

// (C) 2001-2021 Intel Corporation. All rights reserved.
// Your use of Intel Corporation's design tools, logic functions and other 
// software and tools, and its AMPP partner logic functions, and any output 
// files from any of the foregoing (including device programming or simulation 
// files), and any associated documentation or information are expressly subject 
// to the terms and conditions of the Intel Program License Subscription 
// Agreement, Intel FPGA IP License Agreement, or other applicable 
// license agreement, including, without limitation, that your use is for the 
// sole purpose of programming logic devices manufactured by Intel and sold by 
// Intel or its authorized distributors.  Please refer to the applicable 
// agreement for further details.


//altera message_off 10036

`timescale 1 ps / 1 ps

module alt_mem_ddrx_ecc_encoder #
    ( parameter
        CFG_DATA_WIDTH              =   40,
        CFG_ECC_CODE_WIDTH          =   8,
        CFG_ECC_ENC_REG             =   0,
        CFG_MMR_DRAM_DATA_WIDTH     =   7,
        CFG_MMR_LOCAL_DATA_WIDTH    =   7,
        
        CFG_PORT_WIDTH_ENABLE_ECC   =   1
    )
    (
        ctl_clk,
        ctl_reset_n,
        
        cfg_local_data_width,
        cfg_dram_data_width,
        cfg_enable_ecc,
        
        input_data,
        input_ecc_code,
        input_ecc_code_overwrite,
        output_data
    );

localparam CFG_ECC_DATA_WIDTH = (CFG_DATA_WIDTH > 8) ? (CFG_DATA_WIDTH - CFG_ECC_CODE_WIDTH) : (CFG_DATA_WIDTH);

input  ctl_clk;
input  ctl_reset_n;
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

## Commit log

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2021-12-12 RV32: Got HW to execute and "debug print" in sim. Also implemented read-only memory in EMU since we need to fix ROM/RAM data segments and copying at startup.
    [Main.cpp]
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2021-12-16 RV32: Begun implementing ROM firmware which will receive binaries from UART. Also fixed memory layout of HW, TB and EMU.
    [Firmware.c, Main.cpp]
2021-12-17 RV32: Fixed UART. Added Serial class to Launcher.
    [Main.cpp, SoC.qsf]
2021-12-18 RV32: Some fixes in firmware. Also fixed build projects script.
    [Firmware.c, Main.cpp]
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2021-12-20 RV32: Firmware error code in leds.
    [Firmware.c]
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2021-12-21 RV32: Fetch next instruction in retire state. Fixed issues with GPIO, I2C and SD ports. Added waiting signal from UART.
    [Main.cpp, SoC.qsf]
2021-12-22 RV32: Fixed UART RX hang.
    [Main.cpp]
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2021-12-26 RV32: Implemented a Register File which reduced synthesize time a lot. Fixed a lot of issues with timing and warnings, added SRAM constraints etc. Able to reset display using I2C to HDMI encoder chip.
    [SoC.stp]
2021-12-26 RV32: Fixed timing issues in HW, implemented SD controller, implemented some missing HW instructions. Almost got SD initialization working in Bare.
    [SoC.stp]
2021-12-26 RV32: Fixed build emulator.
    [Main.cpp]
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2021-12-28 RV32: Work on pipelined CPU, stalling pipeline when memory is accessed. Scheduling between stages using a tag instead of execute signal.
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2021-12-29 RV32: Pipelined CPU running on HW.
    [SoC.stp]
2021-12-29 RV32: Implemented byte and half memory access in pipeline CPU. Able to run firmware and upload binary again.
    [SoC.stp]
2021-12-30 RV32: Paged VRAM, able to swap between two pages of video memory, one for output and one for writing thus able to double buffer output.
    [SoC.stp]
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2021-12-30 RV32: Fixed emulation UART.
2022-01-01 RV32: Generated a DDR2 SDRAM IP and hooked it up, not tested on HW.
    [IP_SDRAM_example.csv, params.txt]
2022-01-01 RV32: Reduced timing of SDRAM IP to fix timing violations.
    [IP_SDRAM_example.csv, params.txt]
2022-01-02 RV32: Able to use SDRAM on HW.
    [IP_SDRAM_example.csv, SoC.stp, params.txt]
2022-01-03 RV32: Implemented reset in HW. Also removed hack when forwarding register values after writeback. Fixed bug in memory stage output pipelined values too early.
    [SoC.stp]
2022-01-03 RV32: Able to read file from SD card, with a FAT32 FS.
    [mkfs.xlsx]
2022-01-10 RV32: A lot of bug fixes but now both UART and CPU memory access should be more stable.
    [SoC.stp]
2022-01-10 RV32: Build solution for target projects.
    [mkfs.xlsx]
2022-01-10 RV32: UART rewritten, using same clock.
    [SoC.stp]
2022-01-10 RV32: Unsigned mul and div in HW.
    [SoC.stp]
2022-01-10 RV32: Removed SDRAM example design.
    [IP_SDRAM_example.csv, params.txt]
2022-01-10 RV32: Timing optimizations in HW, improved slack a lot. Experimenting with running at 100 MHz for now.
    [SoC.stp]
2022-01-10 RV32: Working on some bug fixing.
    [Main.c]
2022-01-11 RV32: Some fixes in HW, more correct.
    [SoC.stp]
2022-01-11 RV32: Trace and dump, need to figure out what goes wrong.
2022-01-11 RV32: Temporary experiment to figure out why HW doesn't work, these should be reverted later...
    [Main.c, Main.cpp]
2022-01-11 RV32: Scanning trace diffs, able to fix some instructions.
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2022-01-11 RV32: Doom running on HW.
    [SoC.stp]
2022-01-12 RV32: Video in SRAM, a bit unstable but seems to work ok.
    [SoC.qsf]
2022-01-12 RV32: No longer check SRAM during memcheck.
    [Main.cpp]
2022-01-14 RV32: A lot of optimizations, improved usage of ALU etc. Also improved icache.
    [SoC.stp]
2022-01-16 RV32: Prefetch work, also added a SoC top for Verilator.
    [SoC.stp]
2022-01-17 RV32: Reverted "Optimized prefetcher."
    [SoC.qsf]
2022-01-18 RV32: 8-bit, palette, video mode.
    [SoC.stp]
2022-01-20 RV32: Verilator emulator improved, able to record trace, VGA display fixed, stubbed SD.
    [Main.cpp]
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2022-01-26 RV32: Using highest nibble to determine peripherial. Some work on DMA and Video, still issues with waiting on DMA to finish.
    [SoC.stp]
2022-01-26 RV32: Memory stall only after first cycle, slight more room to initiate more work before stall.
2022-01-26 RV32: Fixed stalls. Also improved fetch FSM.
2022-01-27 RV32: Fixed start vector in RV32T, after fetch refactor.
    [Main.cpp]
2022-01-27 RV32: Fixed memory map in emulator.
    [Main.cpp]
2022-01-29 RV32: Basic CSR with interrupts implemented, far from compliant with specification.
    [SoC.stp]
2022-01-29 RV32: Fixed latch issue in EXEC stage. Also cleaned up some warnings.
    [SoC.stp]
2022-01-31 RV32: Implemented CSR instructions again. Also implemented "fence" to flush D-cache.
    [SoC.stp]
2022-01-31 RV32: Basic CSR registers working. Timer interrupt working.
    [SoC.stp]
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2022-02-05 RV32: Fixed compile issues in Quartus.
    [SoC.qsf]
2022-02-06 RV32: Reverted some pipeline buffering code, was causing too bad timing. Kept in FETCH since it's not used by forwarding and could be used for prefetching.
    [SoC.stp]
2022-02-07 Rv32: Implemented memory RAW hazard detection, stalling EXE if hazard detected. Also using FST for trace logs.
    [Main.cpp]
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2022-02-07 Rv32: Fixed orientation of triangles.
    [Main.c]
2022-02-08 Rv32: Measure DMA and CPU bus collision rate in Rv32T.
    [Main.cpp]
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2022-02-10 Rv32: Various Quake fixes.
    [quakedef.h]
2022-02-10 Rv32: Two uarts, one on USB and one on GPIO.
    [SoC.stp]
2022-02-11 Rv32: CPU stall measurements in Rv32T.
    [Main.cpp]
2022-02-11 Rv32: Split shift ALU instructions into separate comb to improve timing. Updated SDRAM configuration from spec. Implemented a WriteBuffer but is disabled for now.
    [SoC.stp]
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2022-02-15 Rv32: Fixed fused mul operations, was wrong signed.
2022-02-22 Rv32: Float compare registered to fix timing issues. Register indices as an enum to improve simulation. Added a skid buffer, not used since I cannot figure out forwarding issues.
    [Main.cpp, SoC.qsf]
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2022-02-23 Rv32: Bare is updated to be a C++ example. Fixed linker script. Updated runtime headers.
    [GPIO.h, Main.cpp]
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2022-02-23 Rv32: Added qmtech cv board project, CPU running at 50 MHz with smaller caches. No peripherials.
    [IP_SDRAM_p0_summary.csv, c5_pin_model_dump.txt]
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2022-02-24 Rv32: Priming icache in Verify to cover pipeline pressure issues better. Also improved some verifications.
    [Main.cpp]
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2022-02-25 Rv32: Fixed issue where FPU instructions was started before previous memory op still busy.
    [Main.cpp]
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2022-02-28 Rv32: Updated HW boards, added support for PLIC on HW etc. Fixed issues with interrupts in Runtime.
    [IP_SDRAM_p0_summary.csv]
2022-03-02 Rv32: SDRAM controller implemented in QM-Tech board.
    [SoC.stp]
2022-03-04 Rv32: Implemented thread sleep, still need to fix yield.
    [Main.cpp]
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2022-03-07 Rv32: Fixed ECALL hang. Implemented thread sleep/yield.
2022-03-08 Rv32: Added CSR verify steps. Fixed issue with clear instructions.
    [Main.cpp]
2022-03-09 Rv32: Worked on interrupts and MT kernel. Still issues prob were timer reenters ecall interrupts.
    [Main.cpp]
2022-03-10 Rv32: SDRAM updated. Optimized timing on forwards.
    [IP_SDRAM_p0_summary.csv]
2022-03-11 Rv32: Begun implementing an audio controller and pwm output. Also fixed some small things in Rv32 emulator.
    [Main.cpp, Runtime.c]
2022-03-12 Rv32: Some work, added audio to Terasic board etc.
    [IP_SDRAM_p0_summary.csv]
2022-03-14 Rv32: SDRAM working on QMTech board, using another, modified, SDRAM controller.
    [SoC.stp]
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2022-03-16 Rv32: LCD legend schematic added.
    [CV Legend.kicad_pcb, CV Legend.kicad_sch]
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2022-03-23 Rv32: At070TN92 video signal generator, added to QMTech CV board.
    [SoC.stp]
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2022-03-24 Rv32: BRAM reduced to same size on all boards, no longer as a quick hack for offscreen framebuffer. Need to figure out a more generic method.
    [Main.cpp]
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2022-03-26 Rv32: DMA compile issues fixed.
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2022-03-28 Rv32: Fixed UART TX bug. Also minor cleanup in GPIO.
    [GPIO.sv]
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2022-03-29 Rv32: Updated GX board top. Also fixed issue in Rv32T top.
2022-03-30 Rv32: First sign of life of DDR3 ram on K7, still not working properly.
    [SoC.xdc]
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2022-04-03 Rv32: Added some legend to LCD board schematics.
    [lcdbrd.kicad_sch]
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2022-04-06 Rv32: Updated SRAM brd schematic. Also updated legend in lcdbrd.
    [lcdbrd.kicad_sch, srambrd.kicad_pcb, srambrd.kicad_sch]
2022-04-11 Rv32: Some work on Terasic CV GX board, brought back into life. Also some reset logic fixes.
    [IP_SDRAM_p0_summary.csv, SoC.stp]
2022-04-11 Rv32: Removed FIFO IPs and merged our FIFO & FIFO64 into a single module.
    [IP_SDRAM_p0_summary.csv]
2022-04-11 Rv32: Added "busy" signals from BusAccess so we can monitor traffic, used to stall DMA when video is accessing VRAM.
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2022-04-12 Rv32: SRAM Aux board schematics updated. JLCPCB v1
    [srambrd-B_Cu.gbr, srambrd-B_Mask.gbr, srambrd-B_Paste.gbr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]
2022-04-15 Rv32: Added some legend to SRAM board schematics.
    [srambrd.kicad_sch]
2022-04-15 Rv32: Fixed video in Rv32T.
    [Main.cpp]
2022-04-15 Rv32: Added "pre-decode" stage to CPU to fix some timing issues.
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2022-04-15 Rv32: Setup for QM-CV board in Video fixed.
2022-04-17 Rv32: Added a BRIDGE component to isolate peripherials from bus and thus improve timing. Fixed a lot ot issues with K7 board, able to use LRU cache to improve DDR3 access.
    [Firmware.c, Runtime.c]
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2022-04-23 Rv32: Begun on a QMTech K7 aux board with SD, I2S DAC and 3v3 power.
    [qm k7 aux brd.csv, qm k7 aux brd.kicad_pcb, qm k7 aux brd.kicad_sch]
2022-04-23 Rv32: QM K7 aux schematic and STM32 breakout schematic. Both ordered.
    [qm k7 aux brd-B_Cu.gbr, qm k7 aux brd-B_Mask.gbr, qm k7 aux brd-B_Paste.gbr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]
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2022-04-26 Rv32: Moved VRAM behind BRIDGE for improved timing. Reverted "one hot" FSM encoding, seems to be counter efficient.
    [SoC.xdc]
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2022-04-27 Rv32: Able to control CPU/GPU read and write offsets in VMODE, no longer have to DMA frames.
    [Main.cpp]
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2022-05-09 Rv32: Audio interrupt implemented, issued at half point of queued samples.
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2022-05-09 Rv32: Wired up interrupt from UART RX. Also replaced a lot of reg/logic to bit type.
2022-05-15 Rv32: Rev 2 of HDMI board. Ordered from JLCPCB.
    [hdmi brd-B_Cu.gbr, hdmi brd-B_Mask.gbr, hdmi brd-B_Paste.gbr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]
2022-05-22 Rv32: HDMI board working. Implemented HID IO through SHID.
    [IP_SDRAM_p0_summary.csv]
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2022-05-22 Rv32: Video size in Rv32 emulator fixed.
    [Main.cpp]
2022-05-27 Rv32: Able to query UART status in Rv32 emulator. Fixed some buffer sizes in SHID.
    [tusb_config.h]
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2022-05-31 Rv32: Improved video VRAM access, almost able to use SRAM on T CV GX board. Some slight noise.
    [IP_SDRAM_p0_summary.csv]
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2022-06-12 Rv32: More USB host board work, using USB connector available on JLCPCB.
    [292303-1.step, usb host hub.kicad_pcb, usb host hub.kicad_sch]
2022-06-14 Rv32: USB HID HUB schematic updated. Ordered from JLCPCB.
    [usb host hub-B_Cu.gbr, usb host hub-B_Mask.gbr, usb host hub-B_Paste.gbr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]
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2022-06-17 Rv32: Do not cache boot mode switch at reset, always read switch instead.
2022-06-17 Rv32: Able to load and execute "boot.elf" from SD by firmware. No longer need block RAM, instead rely entirely on SDRAM.
    [Firmware.c, Runtime.c]
2022-06-18 Rv32: Fixed default stack pointer in emulator. Also reduced video size to match HW.
    [Main.cpp]
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2022-06-21 Rv32: Able to load firmware into emulator. Fixed memory issues in firmware and UART code. Able to detected out-of-range errors in Rv32T.
    [Firmware.c, Main.cpp]
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2022-07-05 Rv32: Rev 2 USB Host schematics. Ordered from JLCPCB.
    [usb host hub-B_Cu.gbr, usb host hub-B_Mask.gbr, usb host hub-B_Paste.gbr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]
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2022-07-18 Rv32: QMTech CV 1 working. Able to verify USB interface board. Optimized firmware by removing atexit stuff. Disabled IRQ handling in CPU for now for timing. Optimized ALU operand lookup using one-hot.
    [SoC.stp]
2022-07-28 Rv32: SDRAM controller; able to run Doom on QMTech CV.
    [SoC.stp]
2022-07-30 Rv32: QMTech CV board 2 up and running. Some issue with SRAM and video garbage.
    [Pin assignments.ods]
2022-08-03 Rv32: Added sysreg define for QMTech CV 5 board.
    [Pin assignments.ods]
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2022-08-23 Rv32: Registered DCache improved, fixed issues with flush. Implemented "cold reset" by writing to a special sysreg. Increased max memory on CV2. Launch able to reset target.
    [SoC.stp]
2022-08-25 Rv32: Interrupts are working on HW, timer and audio interrupts tested. Implemented a "play" command in shell to play some music using interrupts.
    [SoC.stp]
2022-08-28 Rv32: Fixed ECALL bug. Improved emulator, supports more keys.
    [Main.cpp, SoC.qsf]
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2022-08-29 Rv32: Fixed offset issue in VMODE. Default to 16 MiB RAM in emulators.
    [Main.cpp]
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2022-08-29 Rv32: Updated ScummVM, using official (but old) version.
    [example.cfg]
2022-08-30 Rv32: PD, D and WB stages no longer check tag since they always execute in one cycle without stalls.
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2022-09-03 Rv32: Push/pop interrupt enable bit to prevent reentrant interrupts.
    [Firmware.c, Main.cpp, Runtime.c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]
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2022-09-06 Rv32: Another revision of the AUX board, ordered from JLCPCB.
    [srambrd-B_Cu.gbr, srambrd-B_Mask.gbr, srambrd-B_Paste.gbr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]
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2022-09-09 Rv32: Fixed bug with JALR in emulator. Added fake Audio device to emulator.
    [Main.cpp]
2022-09-09 Rv32: Able to raise timer interrupt manually thus no longer need ecall hack to yield kernel.
    [Firmware.c]
2022-09-09 Rv32: SRAM AUX board fix, reuploaded to JLCPCB.
    [srambrd-B_Cu.gbr, srambrd-B_Mask.gbr, srambrd-B_Paste.gbr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]
2022-09-11 Rv32: Increased UART speed. Cleaned up firmware. Using BRAM fifo in audio. Fixed file overwrite bug in RT.
    [Firmware.c, Main.cpp]
2022-09-12 Rv32: LFN support enabled in File. Fixed overlay issues in ScummRV. Begun implementing game browser support in ScummRV. Renamed FIFO64 to FIFO.
    [Main.cpp, SoC.qsf, main.cpp]
2022-09-12 Rv32: SD write support in emulator. Fixed browsing interface in ScummVM.
    [Main.cpp]
2022-09-12 Rv32: Fixed mouse button emulation.
    [Main.cpp]
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2022-09-17 Rv32: Using Rev 2 of SRAM module in QMTech CV 2. Fixed a lot of other issues as well, video much improved etc.
    [Pin assignments.ods, SoC.stp]
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2022-09-18 Rv32: Implemented a couple of SD patterns in HW to improve through put. Improved boot shell. Fixed alot of issues with SD handling.
    [SoC.stp]
2022-09-18 Rv32: Increased UART 1 RX buffer size, was missing some input from HID. Added constants for file_seek.
    [Main.cpp]
2022-09-19 Rv32: Fixed HDMI device in Rv32T.
2022-09-21 Rv32: No longer uses "tag" but instead a strobe signal, not passed through but each stage toggle when output is valid.
    [Main.cpp]
2022-09-21 Rv32: Missing CPU rdata from VIDEO_controller fixed when wbuffer is enabled.
    [VIDEO_controller.sv]
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2022-09-25 Rv32: Kernel signals implemented. Fixed issues with interrupts and PLIC controller locking. Video synchronized to vblank interrupt.
    [Main.cpp, Runtime.c]
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2022-09-28 Rv32: Improved critical section handling, no longer skip in interrupt handler.
2022-09-28 Rv32: Timer interrupt pending instead of ignored when TIE disabled; still doesn't work and need verification.
2022-09-30 Rv32: More work on Kernel; fixed issues with MIE and MTIE, able to handle critical section quickly.
    [SoC.stp]
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2022-10-05 Rv32: Some fixes in emulator with timers.
2022-10-11 Rv32: Fixed issues with kernel since rdtime change.
    [Main.cpp]
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2022-10-11 Rv32: Removed "external interrupt enable" pin; was skipping vblanks.
2022-10-17 Revert "Rv32: Improved busy signal in execute stage."
    This reverts commit 04b672fc6ef5741f86827638843a72b8a336524a.
2022-10-17 Rv32: Two modes of interrupts in Timer. Able to use countdown in Kernel.
    [SoC.stp]
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2022-10-19 Rv32: Stupid mistake, forgot to enable MUL/DIV in GCC config. Implemented a rudimentrary profiler in emulator.
    [Main.cpp]
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2022-10-24 Rv32: Rewrote icache, no longer require a stall signal, only "reg" is working atm.
    [Main.cpp]
2022-10-25 Rv32: Fixed bus profiler in Rv32T.
    [Main.cpp]
2022-10-26 Rv32: Modified sysregs a bit, moved cold reset into control bits.
    [Runtime.c]
2022-10-26 Rv32: Reverted change in VIDEO controller. Added "full" signal from WriteBuffer.
    [VIDEO_controller.sv]
2022-10-31 Rv32: Do not precharge banks before reset if none is open. Also tweaked parameters a bit.
    [SDRAM_controller.sv]
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2022-10-31 Rv32: Fixed memtest in launcher.
    [Main.cpp]
2022-11-01 Rv32: Fix in comb D$ for flush. Added "read offset" register to Video controller, will copy entire frame before presenting to reduce tearing.
    [VIDEO_controller.sv]
2022-11-04 Rv32: Fixed edge cases of video controller. SRAM interface registered IO. Kernel signal timeout bug fixed. Pink console.
    [Firmware.c, Main.cpp, Runtime.c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]
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2022-11-08 Rv32: Fixed quake framebuffer.
2022-11-09 Rv32: Fixed interrupts in emulator. Also fixed video in emulator.
    [Main.cpp]
2022-11-15 Rv32: Removed CV legend schematic; no longer relevant.
    [CV Legend.kicad_pcb, CV Legend.kicad_sch]
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2023-01-15 Rv32: A lot of work, primarily to get 640x400 to work properly on HW.
    [SoC.stp]
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2023-01-15 Rv32: Video working, still first scanline broken but no garbage or blank screen.
    [SoC.stp]
2023-01-19 Rv32: Implemented a BusValidator module. Fixed logging of both verilator and Traktor pipes.
    [Main.cpp]
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2023-01-20 Rv32: Fixed issue in video controller which caused flicker on HW.
    [VIDEO_controller.sv]
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2023-01-20 Rv32: DualPort is now combinatorial, saves some cycles. Fixed video issues; video fully correct now on HW.
    [VIDEO_controller.sv]
2023-01-31 Rv32: Fixed video in Rv32 emulator.
    [Main.cpp]
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2023-10-29 Rv32: Compile fixes for the emulators.
    [Main.cpp]
2025-04-29 Rv32: Fixed verification of ADDI instruction.
    [Main.cpp]

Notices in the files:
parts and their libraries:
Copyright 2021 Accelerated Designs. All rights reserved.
